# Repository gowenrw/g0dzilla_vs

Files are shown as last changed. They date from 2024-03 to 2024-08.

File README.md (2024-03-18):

# godzilla_vs

Godzilla VS Badge Artifacts

This is a DEFCON Indie badge created for DC32.

This is where all the files for the Badge will be stored.

This includes code and art and cad and fab files.  All the things.

## File Structure

This is the file structure of this repository

* [/](/README.md) - YOU ARE HERE
* [/art/](./art/) - Artwork and other graphics created by this project
  * [/art/inspiration/](./art/inspiration/) - Art and graphics pulled f6 other sources used as inspiration for this project
  * [/art/fonts/](./art/fonts/) - Fonts used in art and graphics
* [/code/](./code/) - All project related Code / Firmware
* [/docs/](./docs/) - Documentation created by this project including web pages
* [/eda/](./eda/) - Electronic Design Automation files (i.e. KiCad)
  * [/eda/godzilla_vs/](./eda/godzilla_vs/) - KiCad 7.x project folder for the godzilla_vs PCB
* [/reference_parts/](./reference_parts/) - Documentation pulled from other sources related to components
* [/README.md](/README.md) - This File
* [/LICENSE](/LICENSE) - Currently set to MIT

Note: the reference_parts directory is a link to a submodule repository.
To add it use the following cmd after cloning this:
```
git submodule update --init --recursive
```
If adding for the first time (i.e., it is not linked in the remote master) use this:
```
git submodule add https://github.com/gowenrw/reference_parts reference_parts
```
This will make a link to the current commit of that repo.
To update it to a newer commit after its been added use this cmd:
```
git submodule update --remote
```

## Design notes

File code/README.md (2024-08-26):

# Code

This is where all the project related Code / Firmware is located

# File Structure

This is the file structure of this repository

* [/](/README.md) - Home
* [/code/](/code/) - YOU ARE HERE

# Arduino IDE/CLI

The code presented here is mostly Arduino code.

In order to use this code and push new code to the ESP32 on the badge we recommend using the Arduino IDE/CLI software.
This can be downloaded for various platforms at [arduino.cc](https://www.arduino.cc/en/software).

The Arduino IDE UI will require some manual configuration to work with the badge ESP32 and our code.

The Arduino CLI can be used instead and allows for scripting much of the initial setup and use of whichever IDE you like (in my case I use VSCode).

# Arduino Versions

These are the Arduino IDE and CLI versions we have tested the code with:

* Arduino IDE v 2.3.2
  * [Windows MSI Link](https://downloads.arduino.cc/arduino-ide/arduino-ide_2.3.2_Windows_64bit.msi)
  * [Linux 64bit AppImage Link](https://downloads.arduino.cc/arduino-ide/arduino-ide_2.3.2_Linux_64bit.AppImage)
  * [MacOS ARM64bit DMG Link](https://downloads.arduino.cc/arduino-ide/arduino-ide_2.3.2_macOS_arm64.dmg)
  * [Installation Instructions](https://docs.arduino.cc/software/ide-v2/tutorials/getting-started/ide-v2-downloading-and-installing)
* Arduino CLI v 0.35.3
  * [Windows MSI Link](https://github.com/arduino/arduino-cli/releases/download/v0.35.3/arduino-cli_0.35.3_Windows_64bit.msi)
  * [Linux 64bit Tarball Link](https://github.com/arduino/arduino-cli/releases/download/v0.35.3/arduino-cli_0.35.3_Linux_64bit.tar.gz)
  * [MacOS ARM64bit Tarball Link](https://github.com/arduino/arduino-cli/releases/download/v0.35.3/arduino-cli_0.35.3_macOS_ARM64.tar.gz)
  * [Installation Instructions](https://arduino.github.io/arduino-cli/0.35/installation/)

WARNING - DO NOT use Arduino CLI v 1.x if you want the scripts here to work, it is very buggy concerning local config files and relative paths

# Quickstart

If you want to jump right in and start compiling and uploading code using the Arduino CLI and the scripts provided then checkout the [QUICKSTART page](QUICKSTART.md).

# Arduino IDE setup and use

Some additional setup is required to use the Arduino IDE with the ESP32 on the badge:

* Add the ESP32 boards manager URL in preferences
  * Under File->Preferences find the "Additional boards manager URLs" section and add the following
  * https://espressif.github.io/arduino-esp32/package_esp32_index.json
  * Then click OK and close the IDE.  When it is reopened it wil download the ESP32 board definitions.
* Select the board "ESP32 Dev Module"
  * You need to select a board to associate with the code even if that board is not connected
  * In the "Select Board" dropdown, choose "ESP32 Dev Module" from the list
  * The first time you do this it may download some addiotional software.
* Connect the ESP32 via USB cable and select the COM port if it is not autodetected
  * In most cases it should autodetect the port
  * Sometimes on first connect you need to help it by going to Tools->Port and choosing the port
* This code exceeds the normal partition size so make sure you select the Minimal SPIFFS Partition type
  * This setting can be found under Tools -> Partition Scheme
* This code uses the AdaFruit NeoPixel library which needs to be installed
  * The library can be installed via the Arduino IDE library manager or manually
  * Installation instructions can be found at [the adafruit neopixel github page](https://github.com/adafruit/Adafruit_NeoPixel)

Once the Arduino IDE environment has been set up you can simply open one of the sketches here, make whatever changes you like, then compile and upload the code to the badge.

# Arduino CLI

In an effort to bring portability to the code here (since this is lacking in the Arduino 2.x IDE) we will be providing a local configuration file for the Arduino CLI and scripts to make use of it.

While we cannot ensure this will work on all systems, the files provided should at a minimum help you configure your local environment.

## Using the CLI Local Config

The arduino cli will use a global default config if a config file is not specified.

A local config file is provided named ```arduino-cli.yml``` which uses relative path references for the data and staging and build and user area that Arduino CLI should use.

These directories are local to the repository code directory and the CLI will install all its needed files here instead of in the various places it usually defualts to on differnt systems.

While this might duplicate many files on your system if they are already installed in default locations, it provides a consistent cross platform way of knowing exactly what libraries, headers, etc., that Arduino will use in the compilation of your code.

NOTE that the .gitignore for this repository has been set up to ignore the local directories used to store the core and library files to prevent these files from accidentally getting uploaded to github.

To use the Arduino CLI with this local config file simply add the ```--config-file arduino-cli.yml``` argument to each CLI command.

For example, the command below uses the local config file and will dump the current config to the screen
```
arduino-cli --config-file arduino-cli.yml config dump
```

## Setup for CLI

There are a few things that need to be done to setup the Arduino CLI for use with the badge ESP32 and our code.

The ESP32 board core files must be loaded as well as any libraries the code will use.

To simplify this setup we have created setup bash script named ```cli-setup.sh``` that can be run on Linux and Windows (via Git Bash for Windows).

To perform the CLI setup via the script execute it in the code directory
```
bash ./cli-setup.sh
```

This script will save any std_out and std_err output to a file named ```arduino_cli_setup.log``` which you can review if you are having issues.

To perform the CLI setup manually without this script you can use the commands outlined below.

### Installing the ESP32 board core for CLI

Since the config is specifying a third party core for the ESP32 we need to pull an initial index from it.  This search command will pull that index.
```
arduino-cli --config-file arduino-cli.yml core search esp32
```

Next we need to install the ESP32 board core files using this command.
```
arduino-cli --config-file arduino-cli.yml core install esp32:esp32
```

If the ESP32 board core files were already installed the above will simply say already installed.

To update the core file indexs to check for newer versions of previously installed cores, use the following command
```
arduino-cli --config-file arduino-cli.yml core update-index
```

To upgrade any previously installed cores use the following command
```
arduino-cli --config-file arduino-cli.yml core upgrade
```

### Installing the Neopixel Library

This code uses the AdaFruit NeoPixel library which needs to be installed

If this is the first time we are installing a library we will need the indexes so this search command will get them
```
arduino-cli --config-file arduino-cli.yml lib search 'Adafruit NeoPixel'
```

Next we need to install the Adafruit NeoPixel library files with this command
```
arduino-cli --config-file arduino-cli.yml lib install 'Adafruit NeoPixel'
```

If the Adafruit NeoPixel library files were already installed the above will simply say already installed.

To upgrade a previously installed version of this library use the following command
```
arduino-cli --config-file arduino-cli.yml lib upgrade 'Adafruit NeoPixel'
```

### Installing Other Libraries

In addition to the Neopixel Library above the CTF portion of our code requires a few more libraries.

These should be installed using the same steps as above.

This is the list of additional libraries needed

* "AsyncTCP"
* "ESPAsyncWebSrv"
* "DNSServer"

## Connect badge ESP32 board via CLI

The following command will dump a list of all available board cores installed
```
arduino-cli --config-file arduino-cli.yml board listall
```

Make sure the ESP32 we are using on the badge is in that list
```
  ESP32 Dev Module                 esp32:esp32:esp32
```

If it is not then retry the CLI setup to install the core files.

Next we will connect the badge ESP32 to our machine using a USB C cable
and check if the CLI can see it.

The following command will list all the connected boards the CLI sees
```
arduino-cli --config-file arduino-cli.yml board list
```

This will show the detected COM port and board type (which may be Unknown)
```
  Port Protocol Type                Board Name FQBN Core
  COM4 serial   Serial Port (USB)   Unknown
```

Don't worry if the board FQBN shows up as Unknown since we can set that

Take note of the COM port since we will need that to communicate with it later

## Compile code via CLI

At this point we should be ready to compile and upload code to the badge ESP32 board.

In the following examples we will be referencing the sketch ```g0dzilla_vs_01``` code so you will need to change this for whichever sketch you wish to use.

The following command will compile the named sketch for use with our board fqbn
```
arduino-cli --config-file arduino-cli.yml compile --fqbn esp32:esp32:esp32 --build-path _build --export-binaries g0dzilla_vs_01 --build-property build.partitions=min_spiffs --build-property upload.maximum_size=1966080
```

The arg ```--build-path _build``` is optional to have it put all build artifacts here instead of temp for ease of troubleshooting.

The arg ```--export-binaries``` will save the final binary files into ```<sketch_name>/build/<fqbn>/``` for use by upload.

The build property args ```--build-property build.partitions=min_spiffs --build-property upload.maximum_size=1966080``` make sure that the partition size and upload size are set properly.
Our code is THIC and wont fit in the default partition size.

When the CLI compile is run it should show you compile stats and/or errors similar to this
```
  Sketch uses 1827197 bytes (92%) of program storage space. Maximum is 1966080 bytes.
  Global variables use 48884 bytes (14%) of dynamic memory, leaving 278796 bytes for local variables.
  Maximum is 327680 bytes.
  Used library        Version Path
  Adafruit NeoPixel   1.11.0  .\code\libraries\Adafruit_NeoPixel
  WiFi                2.0.0   .\code\_data\packages\esp32\hardware\esp32\2.0.11\libraries\WiFi
  AsyncTCP            1.1.4   .\code\libraries\AsyncTCP
  DNSServer           2.0.0   .\code\_data\packages\esp32\hardware\esp32\2.0.11\libraries\DNSServer
  ESPAsyncWebSrv      1.2.6   .\code\libraries\ESPAsyncWebSrv
  FS                  2.0.0   .\code\_data\packages\esp32\hardware\esp32\2.0.11\libraries\FS
  Used platform Version Path
  esp32:esp32   2.0.11  .\code\_data\packages\esp32\hardware\esp32\2.0.11
```

### Script to Compile code via CLI

To simplify the above we have created a bash script named ```cli-compile.sh``` that takes a single command line argument of the sketch name.

To perform the compile via the script execute it in the code directory
```
bash ./cli-compile.sh g0dzilla_vs_01
```

## Upload code via CLI

Now we are ready to upload the binary we compiled to the badge ESP32 board.

Note that the binary file needed is saved to ```<sketch_name>/build/<fqbn>/``` and will be named ```<sketch_name>.ino.bin```
The code we have written here may include binaries which can be used without compiling and if you make changes and compile then these files should be overwritten.

The following command will upload the named sketch binary to the badge
```
arduino-cli --config-file arduino-cli.yml upload -p COM4 --fqbn esp32:esp32:esp32 --input-file g0dzilla_vs_01/build/esp32.esp32.esp32/g0dzilla_vs_01.ino.bin
```

NOTE: Saving the compiled binary in a defined place and uploading from an input file allows for quickly changing between different code without the need to compile each again.

It should show you upload stats and/or errors
```
  esptool.py v4.5.1
  Serial port COM4
  Connecting....
  Chip is ESP32-D0WD-V3 (revision v3.0)
  Features: WiFi, BT, Dual Core, 240MHz, VRef calibration in efuse, Coding Scheme None
  Crystal is 40MHz
  MAC: a8:42:e3:47:f0:50
  Uploading stub...
  Running stub...
  Stub running...
  Changing baud rate to 921600
  Changed.
  Configuring flash size...
  Flash will be erased from 0x00001000 to 0x00005fff...
  ...
  Compressed 18960 bytes to 13073...
  Writing at 0x00001000... (100 %)
  Wrote 18960 bytes (13073 compressed) at 0x00001000 in 0.3 seconds (effective 538.9 kbit/s)...
  Hash of data verified.
  ...
  Compressed 732656 bytes to 475614...
  Writing at 0x00010000... (3 %)
  Writing at 0x0001c1bd... (6 %)
  ...
  Writing at 0x000bcec0... (96 %)
  Writing at 0x000c2b72... (100 %)
  Wrote 732656 bytes (475614 compressed) at 0x00010000 in 6.3 seconds (effective 925.8 kbit/s)...
  Hash of data verified.
  Leaving...
  Hard resetting via RTS pin...
```

### Script to Upload code via CLI

To simplify the above we have created a bash script named ```cli-upload.sh``` that takes two command line arguments of the sketch name and serial port.

To perform the compile via the script execute it in the code directory
```
bash ./cli-upload.sh g0dzilla_vs_01 COM4
```

## Monitor Serial Output

To monitor the serial output you can use the arduino-cli or your favorite serial app.

The following command will list all the connected boards so you can get the serial port
```
arduino-cli --config-file arduino-cli.yml board list
```

The arduino-cli monitor command with serial port (from above) and baud config can be used like this:
```
arduino-cli monitor --port COM4 --config baudrate=115200
```

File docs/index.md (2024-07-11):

---
layout: default
---

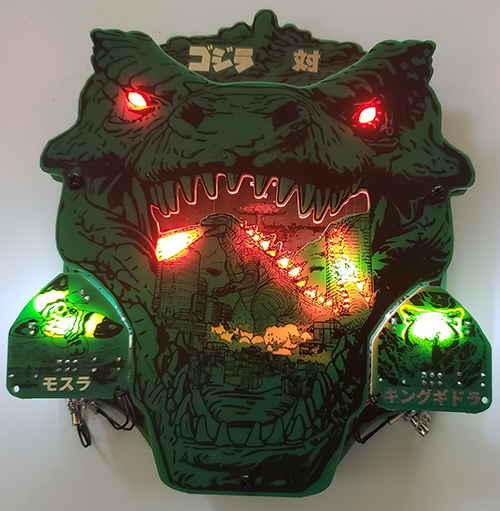
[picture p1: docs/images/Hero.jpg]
Hero Image


# G0dzilla VS Badge

Welcome to the G0dzilla VS Badge website.

This badge was designed for the DEFCON 32 security conference in August 2024.

On this page you will find all the details about this badge including an operations guide, an assembly guide (for those building the badge from a kit), and a detailed review of the art and cicuit design and pcb design.

-- [@alt_bier](https://twitter.com/alt_bier)  - [My Contact Info](https://gowen.net/about)

---

Touch Image

# Details

The badge theme was based on the fact that I love Godzilla and the movie Godzilla Minus One that was released in 2023 inspired me to do something with this theme.

Since I make badges I figured this would be my medium.  However, I made a previous badge that had Godzilla on it so if I was going to revisit this theme it was going to have to be bigger and better.

Having Godzilla fight different monsters that can be changed out since they are addons was the idea I had to bring a Godzilla badge to the next level.

This badge includes an ESP32 Wemos Lolin32 development board, eight neopixel addressable LEDs, eight traditional white LEDs, and four capacitive touch areas, four female SAO connectors (two of which are powered), and three PCBs stacked together, all powered by a LIPO battery.  And that is just the main badge!

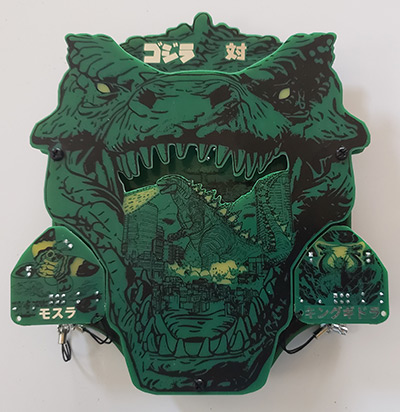
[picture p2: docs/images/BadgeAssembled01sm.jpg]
Badge Assembled

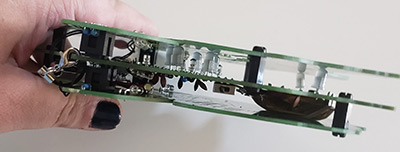
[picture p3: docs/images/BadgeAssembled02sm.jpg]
Badge Assembled


This badge also includes four Shitty Addons (SAOs) which are the monsters that Godzilla will fight.  These addons each have two traditional white LEDs and a male hooded SAO connector.
The SAOs also utilize one of the GPIO pins to send specific voltage back to the badge per SAO.  This allows for the main badge to detect which monsters are connected to it.
Up to two of the four SAOs can be connected to the front of the badge to fight Godzilla.
In order to keep the SAOs from getting separated from the badge we included mini SAO lanyards that attach them to the badge and there are two SAO connectors on the back of the badge (not powered) that act as a green room for monsters not currently in the fight.

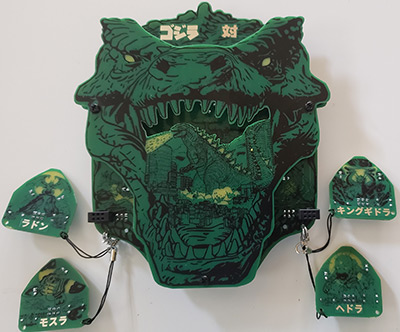
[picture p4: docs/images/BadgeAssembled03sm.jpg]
Badge with SAOs


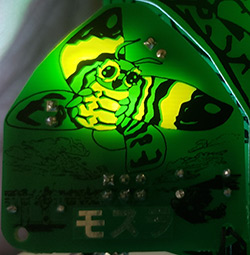
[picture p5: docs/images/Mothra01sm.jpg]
SAO Mothra

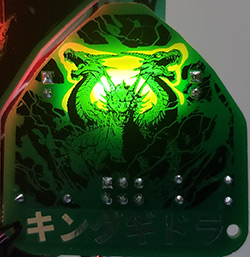
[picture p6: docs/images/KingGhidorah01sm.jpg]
SAO King Ghidorah

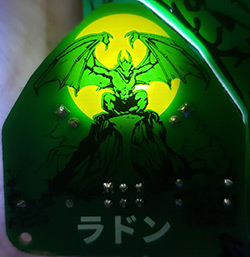
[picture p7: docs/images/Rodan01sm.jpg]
SAO Rodan

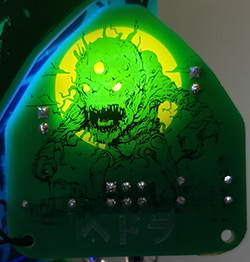
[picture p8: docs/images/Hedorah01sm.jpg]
SAO Hedorah


Since the ESP Dev board has an embedded battery charge circuit the schematic for the main badge was fairly simple.
The schematic for the SAO PCB had a challenge in that these were to be four seperate circuits but rules checks were complaining about 3V and GND not being connected between them.  I solved this by using four seperate 3V and GND power nets.
The PCB layout and tracing was a challenge due to all the solder mask voids and capacitive touch areas and the fact that there were four seperate PCBs (seven if you consider the SAO PCB breaks out to four) that all had to align perfectly with each other for when they were assembled together.

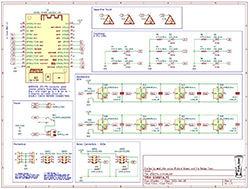
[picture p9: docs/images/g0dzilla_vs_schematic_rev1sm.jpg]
Schematic badge

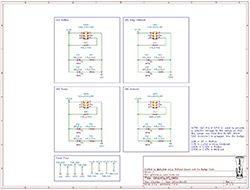
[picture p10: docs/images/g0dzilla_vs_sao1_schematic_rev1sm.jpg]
Schematic SAOs


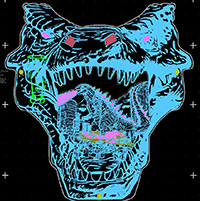
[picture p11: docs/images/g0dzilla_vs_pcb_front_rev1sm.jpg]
PCB Front

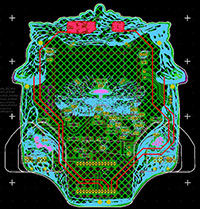
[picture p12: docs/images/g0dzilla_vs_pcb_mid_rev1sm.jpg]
PCB Middle

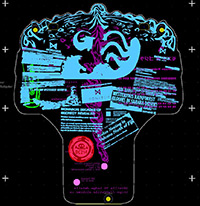
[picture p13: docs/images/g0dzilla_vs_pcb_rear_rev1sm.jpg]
PCB Rear

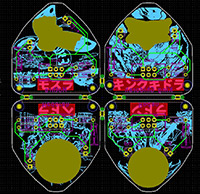
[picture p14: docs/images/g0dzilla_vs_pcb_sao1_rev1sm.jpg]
PCB SAOs


# Kit Assembly

Assembly Instructions for the G0dzilla VS Badge kit can be found here: [G0dzilla VS Badge Assembly Instructions](assembly.md)

An assembly video can be found here:
TBD

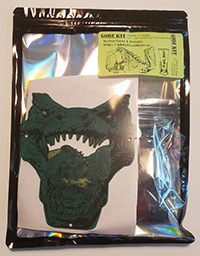
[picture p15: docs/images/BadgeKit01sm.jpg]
Badge_Kit

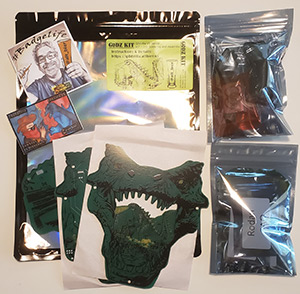
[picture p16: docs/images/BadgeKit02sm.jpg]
Badge_Kit

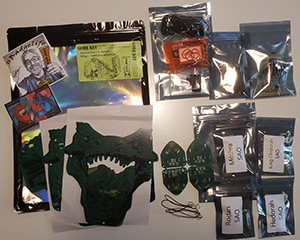
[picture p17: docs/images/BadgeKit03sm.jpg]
Badge_Kit


# Badge Operations

Here are the basics for operating the badge.

## Power Switch and Battery Charging

This badge uses an ESP32 Development board with a USB-C connector that is connected to and powered by a LIPO rechargeable battery.

The power switch on the badge is a direct cutoff to the LIPO battery.
So the switch must be in the ON position in order to charge the battery from the dev board.

The switch is on the side of the badge and is in the OFF position when it is closer to the bottom of the badge (down).

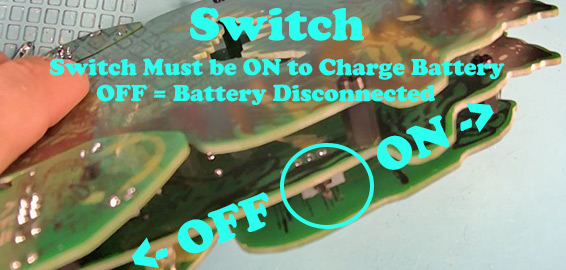
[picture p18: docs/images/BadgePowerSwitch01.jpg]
Power Switch Image


To charge the battery follow these steps:
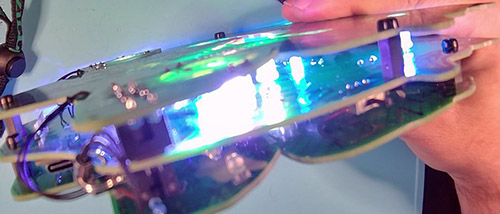
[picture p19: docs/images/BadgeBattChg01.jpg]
Power ON Image
* Turn the power switch to ON (towards the top of the badge) which will power on the badge if the battery has any charge remaining.  But, even if the badge does not power on the switch should be in the ON position. 
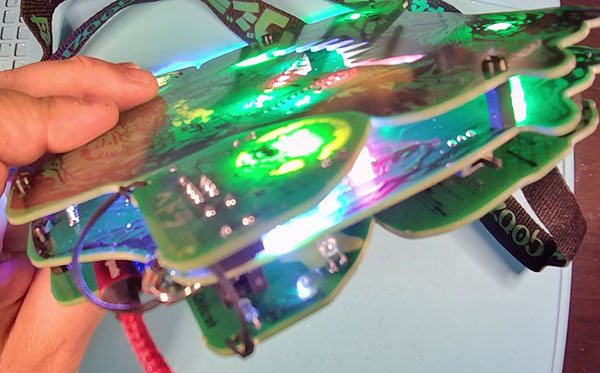
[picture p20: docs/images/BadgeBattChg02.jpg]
USB Cable Image
* Plug in a USB-C cable to the badge dev board and apply power either from a PC or wall charger. 
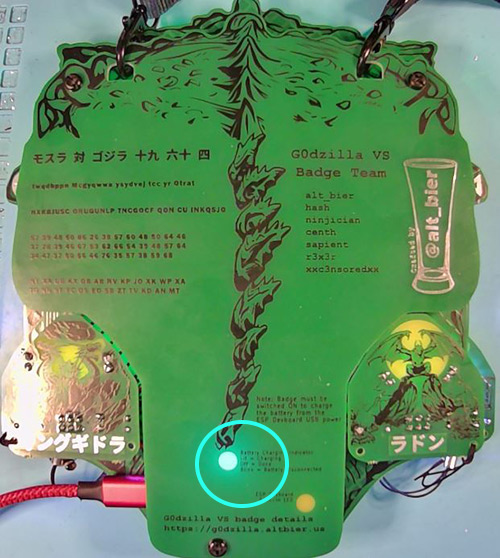
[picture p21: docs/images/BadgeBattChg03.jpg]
Charge Indicator Image
* On the back of the badge you should see the battery charge indicator light lit up.  If it is not then repeat the first two steps to try again.  This indicator light should flash if it does not see a battery connected and will turn off when a connected battery is fully charged. 
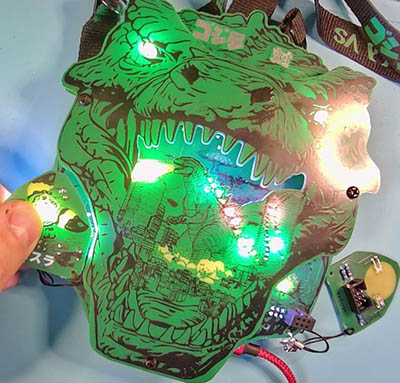
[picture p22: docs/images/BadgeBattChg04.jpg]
Remove SAOs Image
* The powered SAOs on the front of the badge should be removed while charging. This will allow for less power drain while charging from those LEDs being removed.  But more imortantly stops shining those bright lights. 
* It should take about 3 to 4 hours to fully charge a battery from fully discharged at which point the battery charge indicator light will turn off.
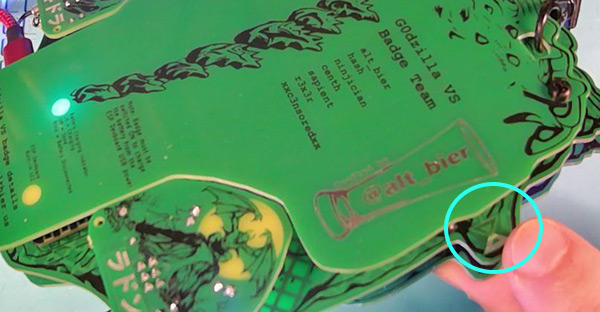
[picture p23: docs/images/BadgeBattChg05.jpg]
Logo Press Image
* Since it can be annoying to have the badge flashing all its LEDs while charging we added a LED-Off mode that can be activated by pressing on the Monarch Logo button (located on the back side of the middle PCB) for a LONG PRESS press of about 20 to 30 seconds. 
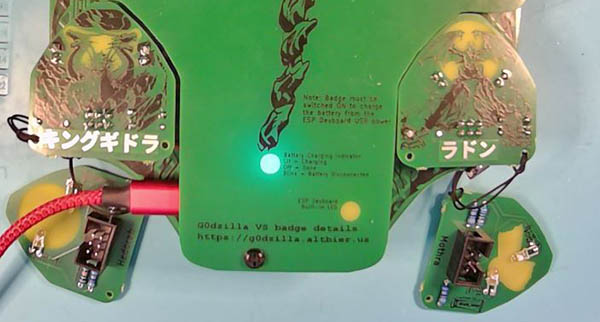
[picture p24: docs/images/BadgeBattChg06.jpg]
LED Off Mode Image
* In the LED-Off mode all the badge LEDs will turn off except for the two on the ESP dev board.  The battery charge indicator light should be on if it charging and the on-board LED will flash once every 20 seconds or so.  The flashing LED is there to tell you the badge is still powered on even if the charge is done and the charge light turns off. This LED mode can be disabled by long pressing the Monarch Logo again or by power cycling the badge (including disconnecting the USB) 

## Touching Godzilla Text - Change badge LED mode

Pressing the word "Godzilla" will change the LED mode.

The default mode color cycles all the neopixels and slowly pulses some of the white LEDs.

There is a battle mode where Godzilla is animated fighting.

Other modes will be added as time permits, but these two modes are what is shipping with the badges. 

## Touching VS Text - Boop

Pressing the word "VS" will flash all the white LEDs briefly in a boop effect.

## Touching Monarch Logo - Boop and LED-Off

Pressing the Monarch Logo will flash all the Neopixel LEDs in a random color briefly in a boop effect.

Holding a long press of 20 seconds on the Monarch Logo will enter the LED-Off mode (as explained in the battery charging section above).

## Touching Godzilla Minus One Logo - Boop and Crypto Challenge Mode

Pressing the Godzilla Minus One Logo will flash all the Neopixel LEDs in a random color briefly in a boop effect.

Holding a long press of 20 seconds on the Godzilla Minus One Logo will enter the Cryppto CTF Mode.

This is a crypto challenge game that is launched on a local wireless ap and web server.

When this mode is activated the eyes on the badge will turn solid red and the badge will launch a wireless access point with the name "GDZL-badge-<MAC>" and a web server on 192.168.1.31

Connect to the access point which is open and does not require a password, then browse http://192.168.1.31 to start the crypto challenge.

This Mode can be disabled by long pressing the Godzilla Minus One Logo again or by power cycling the badge.

## Silkscreen Crypto Challenge

In addition to the web based crypto challenge there is an additional crypto challenge built into the silkscreen layer on the back of the badge.

While similar in style and layout of the web based challenge these are seperate challenges that do not depend upon each other for solving.

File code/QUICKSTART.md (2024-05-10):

# Code Quickstart

Notes:

* You will need Arduino CLI Installed and a Bash shell (on Windows Git Bash is provided by Git for Windows)
* The CTF code is a precompiled library so you cant change that for now, source to be released after defcon
* The current code that is loaded on the badge is the sketch named ```g0dzilla_vs_01```

## Setting up Arduino CLI environment

Follow these steps:

* Change directory to the code directory if you arent already there
* Run the following command preceding it with ```bash``` if needed by your OS
  * ```./cli-setup.sh```
* If it completes without errors then setup is complete
  * If you have errors then refer to the main README doc or script file to try the steps manually

## Compiling Code

Once you have made whatever changes you wanted to the code here is how we compile it.

* Change directory to the code directory if you arent already there
* Run the following command preceding it with ```bash``` if needed by your OS changing the sketch name if needed
  * ```./cli-compile.sh g0dzilla_vs_01```
* If it completes without errors then the compile is complete
  * If you have errors then read what they are and make the appropriate changes to your code

## Upload Code

Once the code has been compiled we can upload it to the badge.

Follow these steps:

* Change directory to the code directory if you arent already there
* Run the following command
  * ```arduino-cli --config-file arduino-cli.yml board list```
* Take note of the serial port name of the connected board 
* Run the following command preceding it with ```bash``` if needed and changing the serial port to above
  * ```./cli-upload.sh g0dzilla_vs_01 COM6```

## Serial Monitor

Once the code has been uploaded you can use the serial monitor to look for any text the code is sending.

* Run the following command changing the serial port to what board list showed above
  * ```arduino-cli monitor --port COM6 --config baudrate=115200```

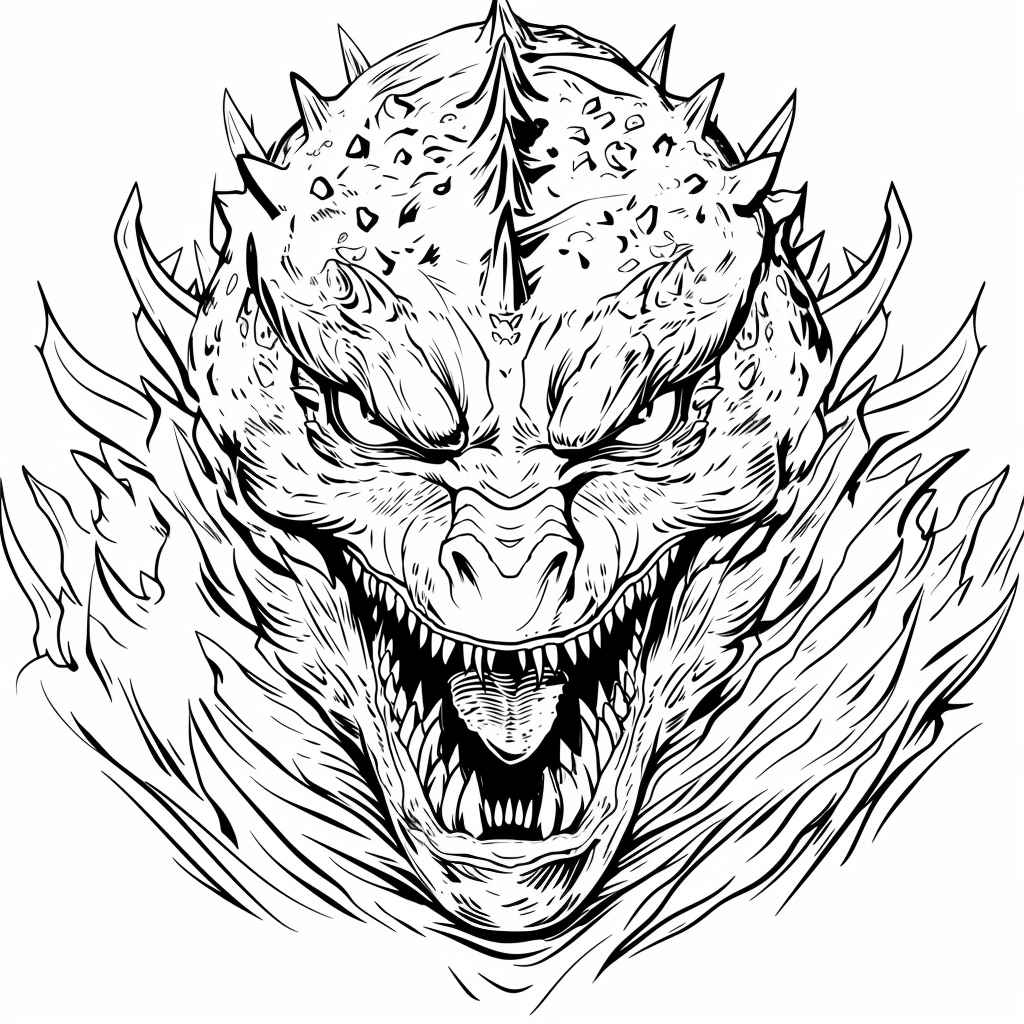
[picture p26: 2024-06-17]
art/inspiration/alt_bier_godzilla_face_both_eyes_visible_about_to_eat_the_viewe_f581bc2f-0139-48a3-ba4f-096c2e8dd892.png

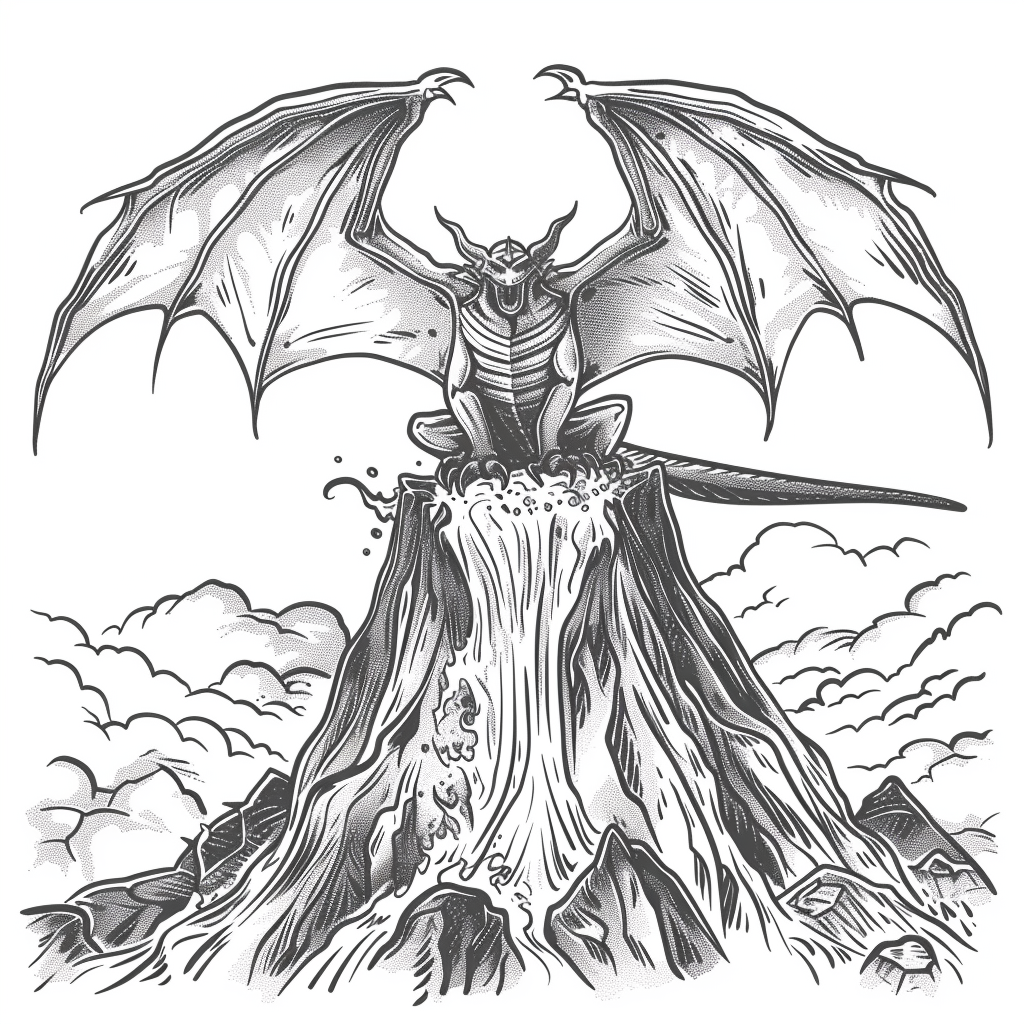
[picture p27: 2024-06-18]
art/inspiration/alt_bier_The_monster_Rodan_sitting_atop_a_volcano_that_is_spill_625bf1e6-68ef-4f6c-bedc-f5eaeb14153d.png

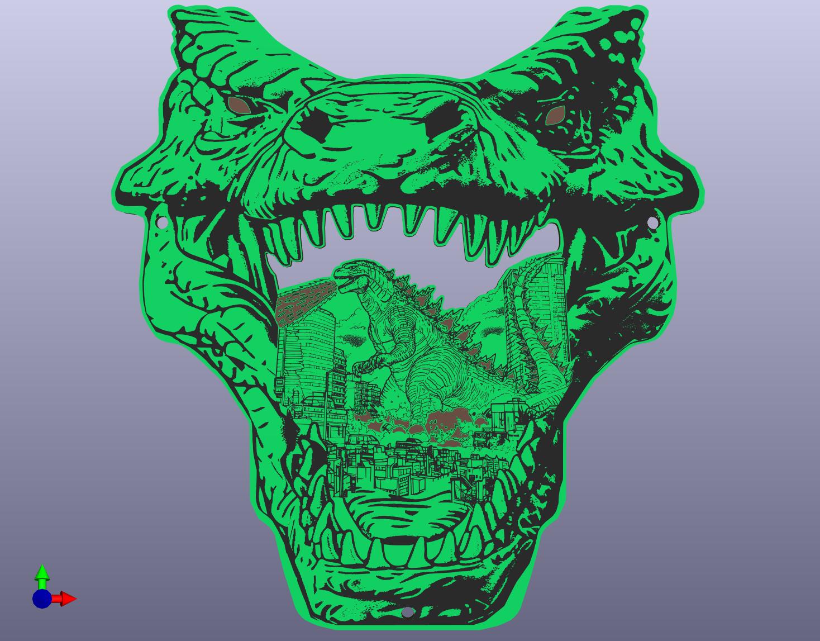
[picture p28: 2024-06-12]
eda/g0dzilla_vs/snapshots/g0dzilla_vs_3D_proto01.jpg

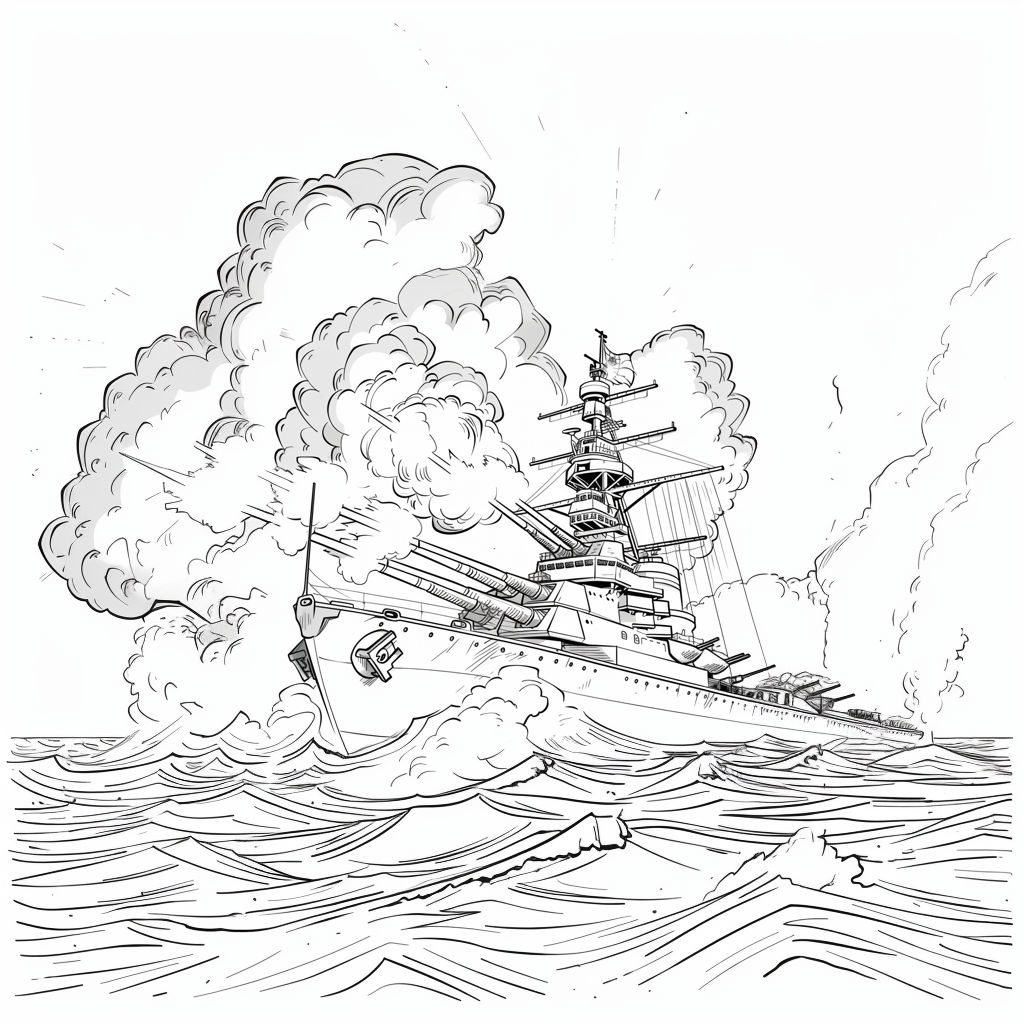
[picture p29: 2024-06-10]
art/inspiration/alt_bier_a_battleship_shooting_at_a_distant_target_with_smoke_p_26e57a6c-4ae1-4770-afa3-136d2fdbe578.png

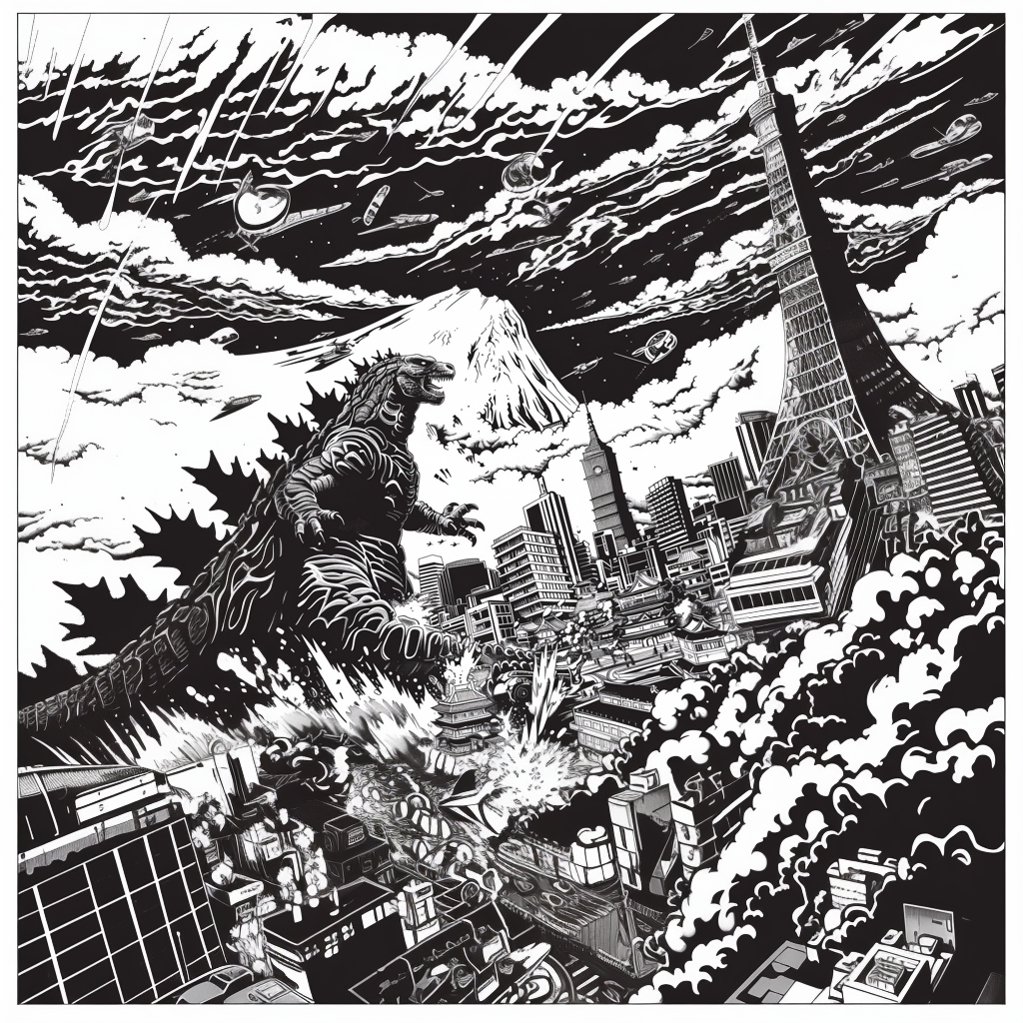
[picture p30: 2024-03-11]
art/inspiration/alt_bier_black_and_white_coloring_page_black_lines_no_color_no__eb211865-8d01-49a8-a5e8-c46503b37f65.png

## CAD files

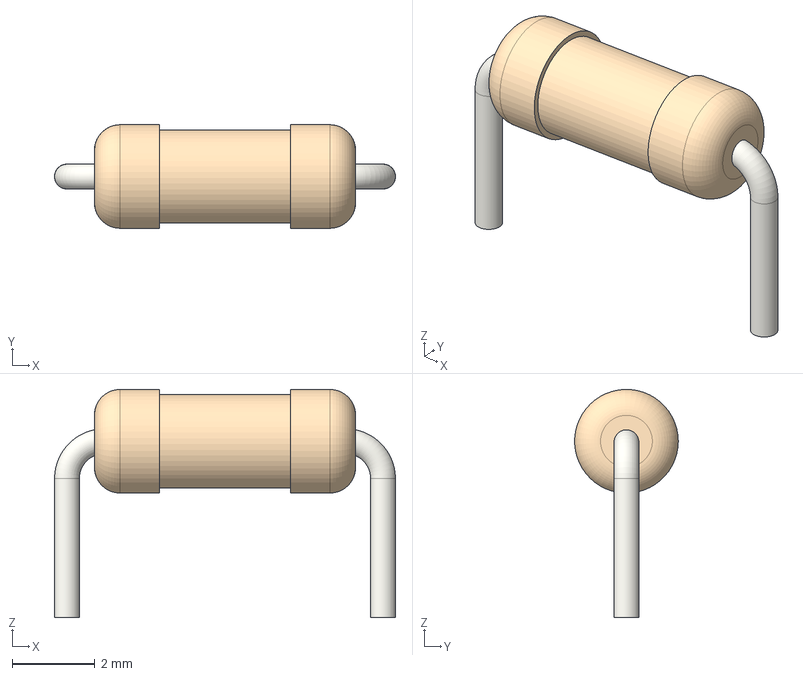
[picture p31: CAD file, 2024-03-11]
eda/g0dzilla_vs/3d_models/R_Axial_DIN0207_L6.3mm_D2.5mm_P7.62mm_Horizontal.step
8.22 x 2.50 x 5.50 mm

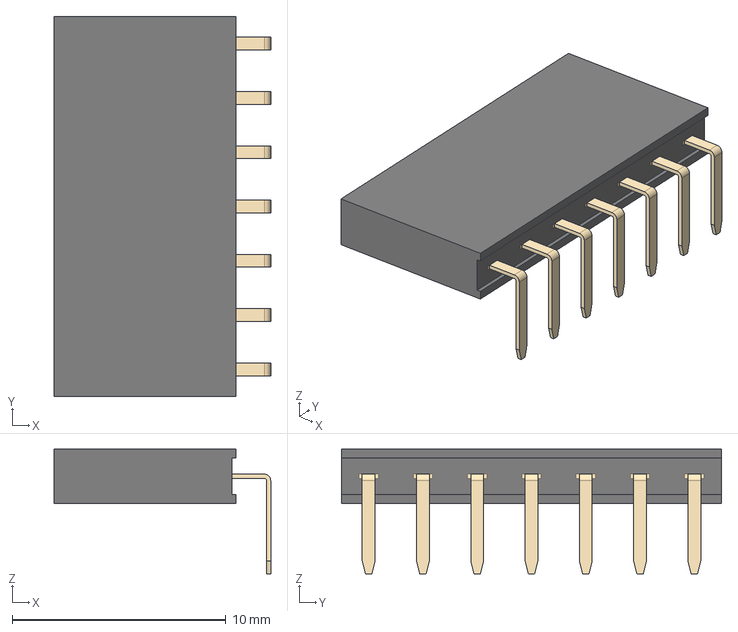
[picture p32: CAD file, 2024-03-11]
eda/g0dzilla_vs/3d_models/PinSocket_1x07_P2.54mm_Horizontal.step
10.1 x 17.8 x 5.84 mm

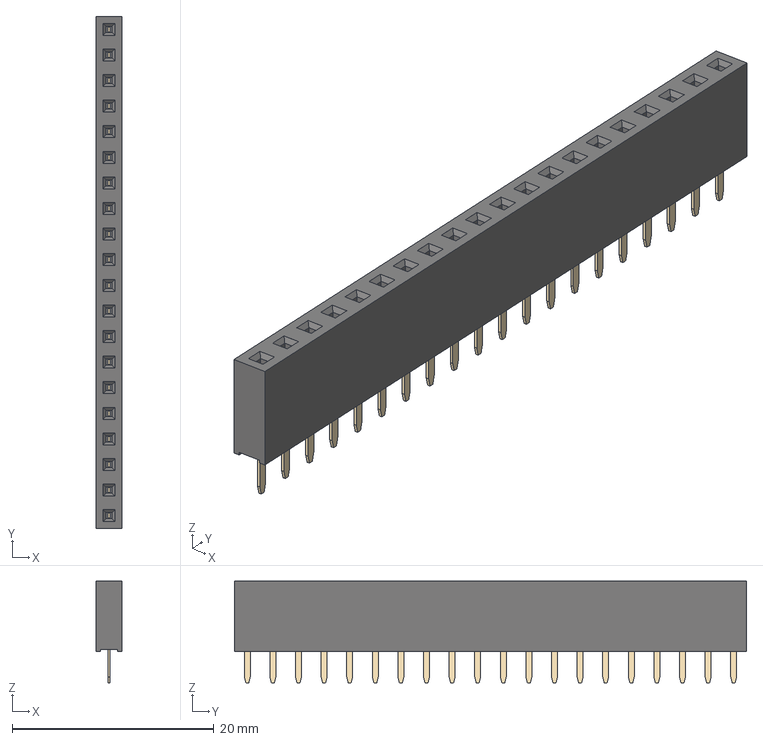
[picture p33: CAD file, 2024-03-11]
eda/g0dzilla_vs/3d_models/PinSocket_1x20_P2.54mm_Vertical.step
2.54 x 50.8 x 10.1 mm

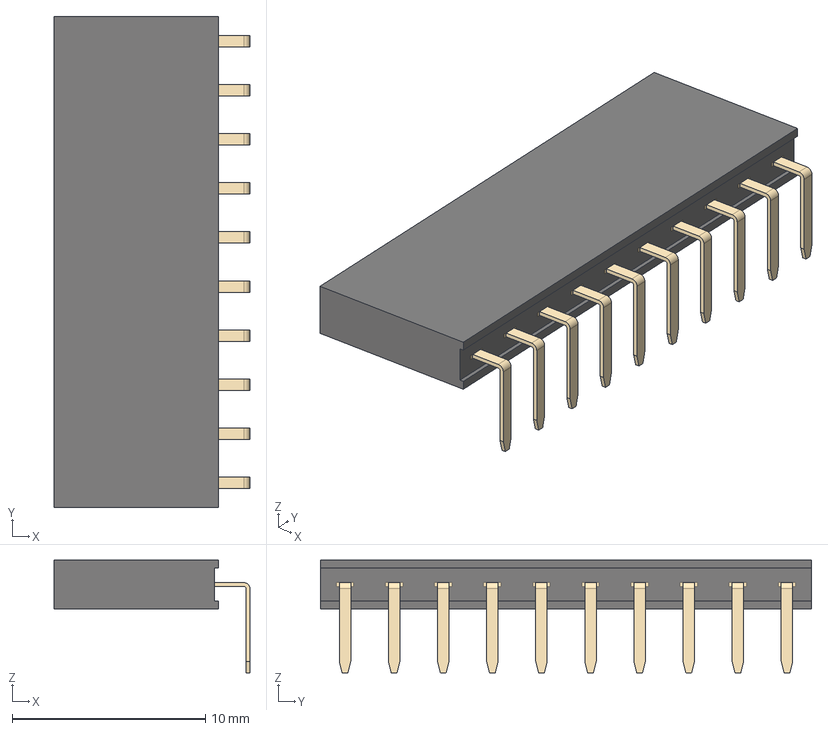
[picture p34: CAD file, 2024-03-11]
eda/g0dzilla_vs/3d_models/PinSocket_1x10_P2.54mm_Horizontal.step
10.1 x 25.4 x 5.84 mm

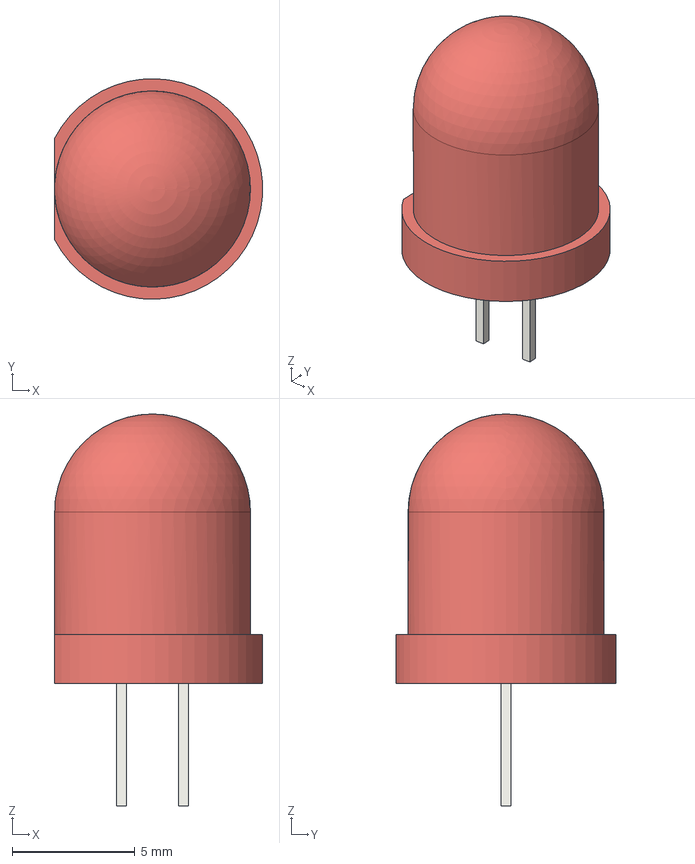
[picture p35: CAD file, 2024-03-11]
eda/g0dzilla_vs/3d_models/LED_D8.0mm.step
8.49 x 9.00 x 16.0 mm

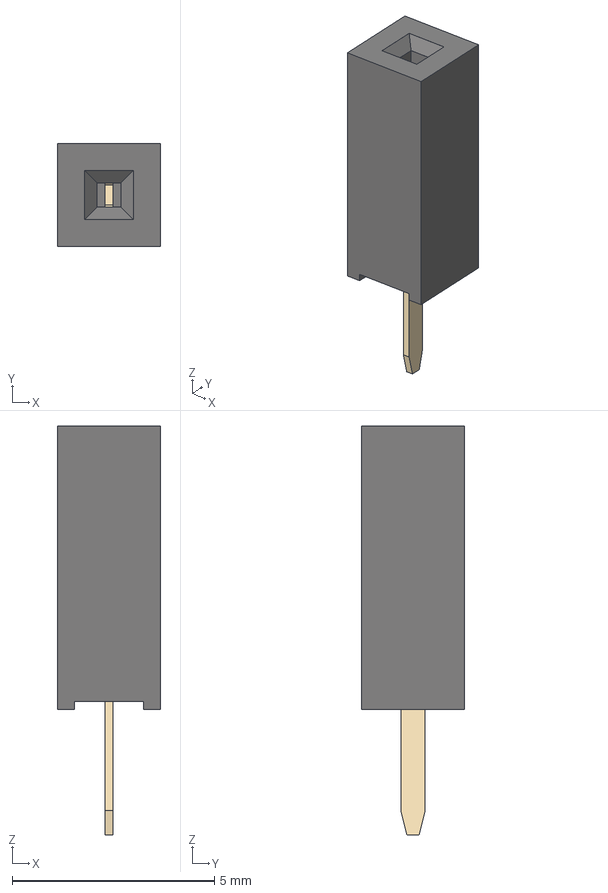
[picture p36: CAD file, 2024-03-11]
eda/g0dzilla_vs/3d_models/PinSocket_1x01_P2.54mm_Vertical.step
2.54 x 2.54 x 10.1 mm

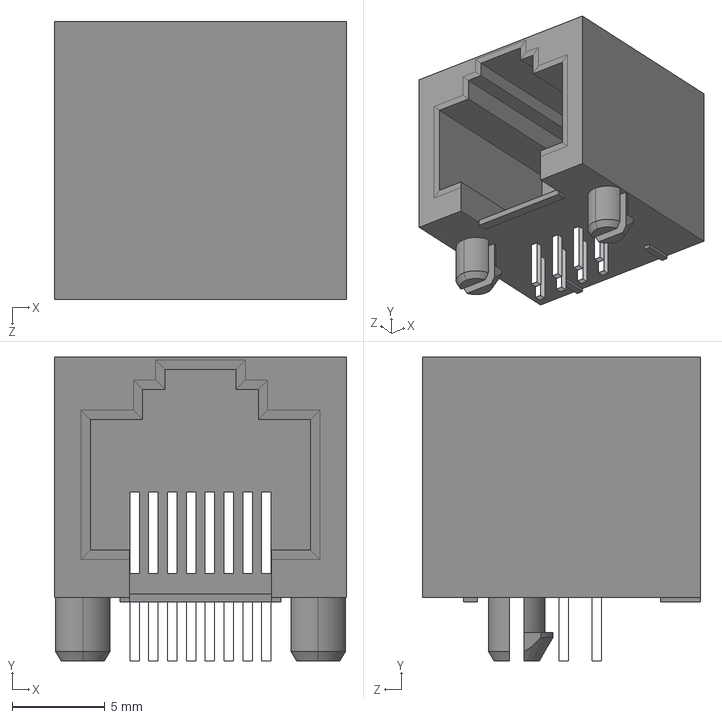
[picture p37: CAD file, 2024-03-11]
eda/g0dzilla_vs/3d_models/RJ45_Amphenol_RJHSE-5080-56544.STEP
15.7 x 16.4 x 15.0 mm

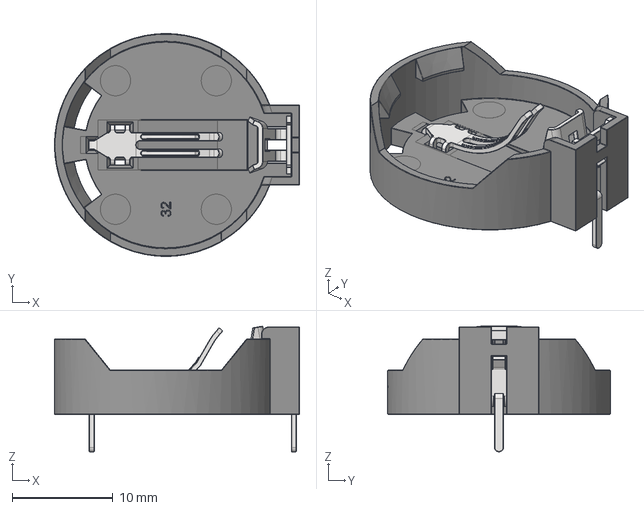
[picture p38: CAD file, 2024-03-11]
eda/g0dzilla_vs/3d_models/Battery_Holder_CR2032_BS-2-1.stp
24.3 x 22.1 x 12.5 mm

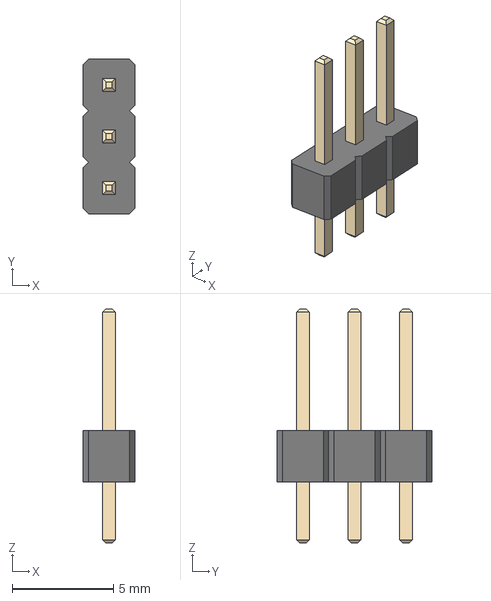
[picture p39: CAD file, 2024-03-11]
eda/g0dzilla_vs/3d_models/PinHeader_1x03_P2.54mm_Vertical.step
2.54 x 7.62 x 11.5 mm

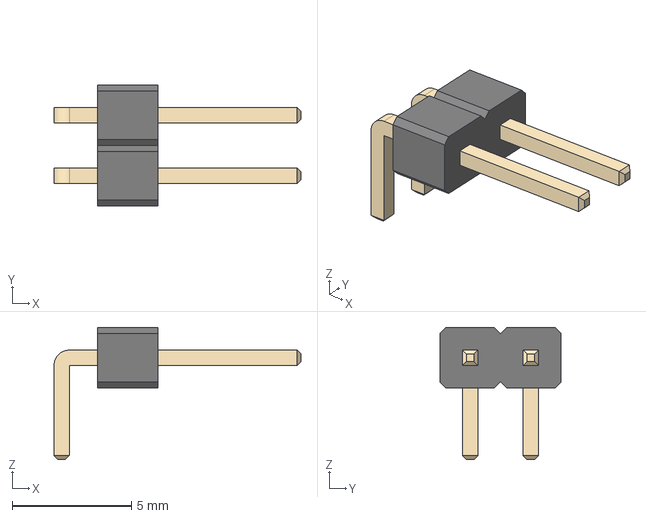
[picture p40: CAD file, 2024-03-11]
eda/g0dzilla_vs/3d_models/PinHeader_1x02_P2.54mm_Horizontal.step
10.4 x 5.08 x 5.54 mm

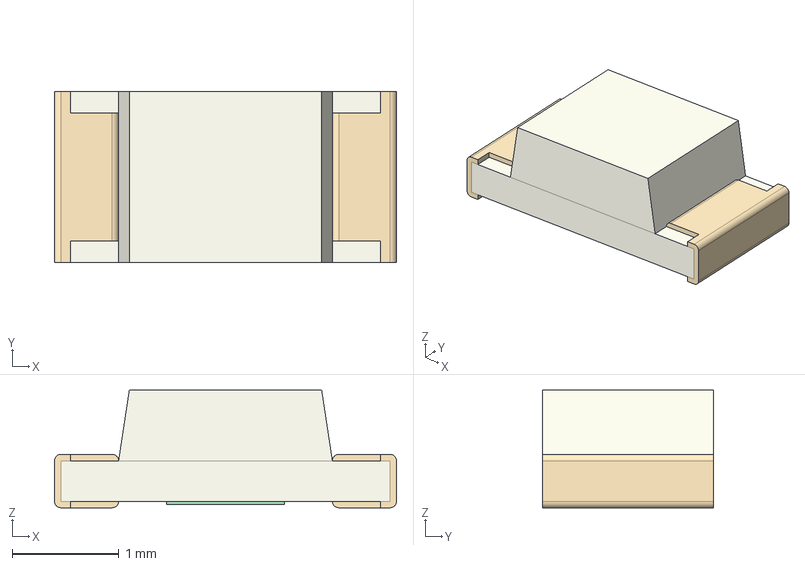
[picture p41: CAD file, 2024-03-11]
eda/g0dzilla_vs/3d_models/LED_1206_3216Metric.step
3.20 x 1.60 x 1.10 mm

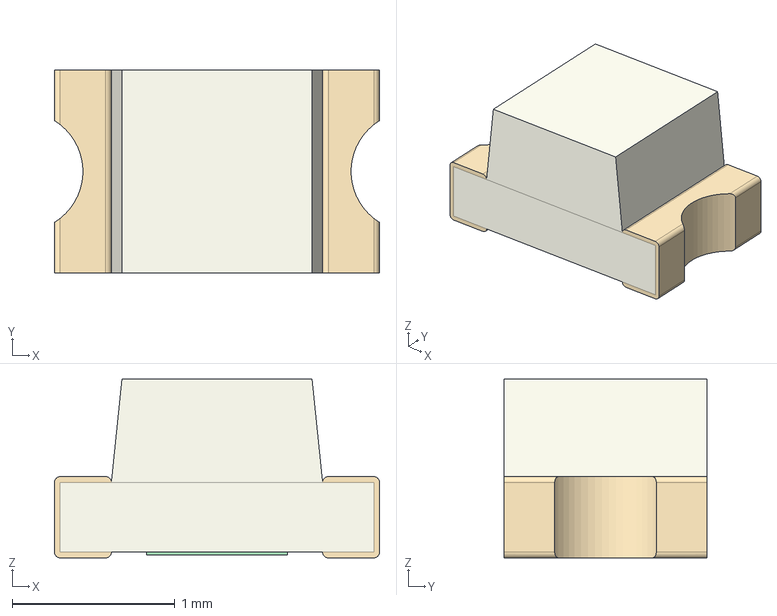
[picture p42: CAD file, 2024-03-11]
eda/g0dzilla_vs/3d_models/LED_0805_2012Metric_Castellated.step
2.00 x 1.25 x 1.10 mm

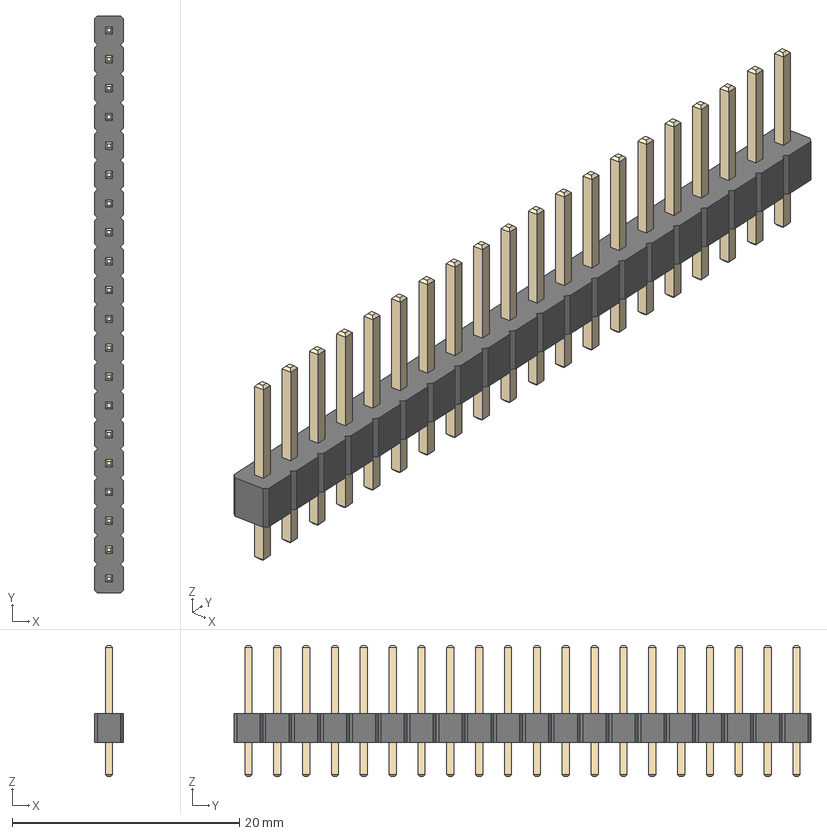
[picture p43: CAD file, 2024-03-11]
eda/g0dzilla_vs/3d_models/PinHeader_1x20_P2.54mm_Vertical.step
2.54 x 50.8 x 11.5 mm

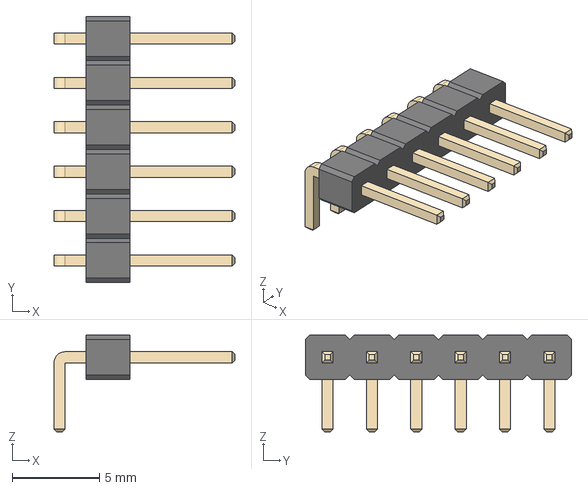
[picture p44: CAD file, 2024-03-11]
eda/g0dzilla_vs/3d_models/PinHeader_1x06_P2.54mm_Horizontal.step
10.4 x 15.2 x 5.54 mm

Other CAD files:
eda/g0dzilla_vs/3d_models/PinSocket_1x20_P2.54mm_Horizontal.step
eda/g0dzilla_vs/3d_models/BatteryHolder_2466_1xAAA.step
eda/g0dzilla_vs/3d_models/PinHeader_1x08_P2.54mm_Vertical.step
eda/g0dzilla_vs/3d_models/RJ45_Amphenol_RJHSE538X.step
eda/g0dzilla_vs/3d_models/BatteryHolder_2468_2xAAA.step
eda/g0dzilla_vs/3d_models/Battery_Holder_3xAAA_Simple.step
eda/g0dzilla_vs/3d_models/CP_Radial_D5.0mm_P2.00mm.step
eda/g0dzilla_vs/3d_models/CP_Radial_D6.3mm_P2.50mm.step
eda/g0dzilla_vs/3d_models/CUI_PXO7803-500-M-TR.step
eda/g0dzilla_vs/3d_models/C_0603_1608Metric.step
eda/g0dzilla_vs/3d_models/C_0805_2012Metric.step
eda/g0dzilla_vs/3d_models/C_1206_3216Metric.step
eda/g0dzilla_vs/3d_models/C_Disc_D3.0mm_W2.0mm_P2.50mm.step
eda/g0dzilla_vs/3d_models/C_Rect_L4.6mm_W2.0mm_P2.50mm_MKS02_FKP02.step
eda/g0dzilla_vs/3d_models/GC9A01_1.28IN_240x240_v1.step
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

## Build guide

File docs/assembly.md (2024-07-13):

---
layout: default
---

# G0dzilla VS Badge Kit Assembly Instructions

Welcome to the G0dzilla VS Badge kit assembly instructions.

This page will detail what comes in the badge kit and step by step instructions to build your badge. 

-- [@alt_bier](https://twitter.com/alt_bier)  - [My Contact Info](https://gowen.net/about)

## Badge Distribution Packages

The badges have been distributed in two different packages

* KIT - This is a kit that requires DIY soldering/assembly of all components
* ASS - This is a Fully Assembled ready to wear badge

## Component List

This is the list of components that are provided in the kit

* Main Kit Bag (20x25cm-8x10in Black & Holographic) Containing:
  * 3x PCBs (front, middle, and rear) separated with paper
  * Badge Component Bag (10x15cm-4x6in Mylar) Containing:
    * Small Component Bag #1 (4x5cm-1.5x2in Clear) Containing:
      * 6x Black Nylon Standoff and M3 Screw sets
    * Small Component Bag (5x7cm-2x2.8in Red) Containing:
      * 1x Lipo Battery 103040
      * 1x JST mini PH Connector Wire
      * 4x Rubber Band Size #8 (2 req. 2 spare)
    * Small Bag (5x8cm-2x3in Clear) Containing:
      * 1x Lanyand
    * Small Component Bag (6x9cm-2.4x3.5in Mylar) Containing:
      * 1x ESP32 WeMos Lolin32 Dev Board
      * 2x Header Male 2.54mm 1x13 Pin Strip
    * Small Component Bag (8x12cm-3.2x4.7in Mylar) Containing:
      * 8x WS2812D 5mm 4-Pin Addressable Neopixel LED
      * 8x White 3mm 2-pin LED
      * 8x 100nF Ceramic Disc Capacitor
      * 10x 47 Ohm 6.2mm Metal Film Resistor
      * 2x 100K Ohm 6.2mm Metal Film Resistor
      * 1x SS12D00 3-Pin SPDT Right Angle Switch
      * 4x Header Male 2.54mm 1x2 Pin Right Angle Strip
      * 4x Header Female 2.54mm 2x3 Pin Keyed (SAO)
  * Badge Component Bag (10x15cm-4x6in Mylar) Containing:
    * 1x PCB panel (which breaks apart into four small SAO PCBs) Note: This PCB might have broken apart during shipping, but this is not a problem as breaking is required for assembly.
    * 4x Mini 2in Lanyard with tiny keyring
    * Small Component Bag (6x9cm-2.4x3.5in Mylar) Labeled "Mothra SAO" Containing:
      * 2x White 3mm 2-pin LED
      * 2x 47 Ohm 6.2mm Metal Film Resistor
      * 1x 10K Ohm 6.2mm Metal Film Resistor
      * 1x Header Male 2.54mm 2x3 Pin Keyed Hooded (SAO)
    * Small Component Bag (6x9cm-2.4x3.5in Mylar) Labeled "King Ghidorah SAO" Containing:
      * 2x White 3mm 2-pin LED
      * 2x 47 Ohm 6.2mm Metal Film Resistor
      * 1x 47K Ohm 6.2mm Metal Film Resistor
      * 1x Header Male 2.54mm 2x3 Pin Keyed Hooded (SAO)
    * Small Component Bag (6x9cm-2.4x3.5in Mylar) Labeled "Rodan SAO" Containing:
      * 2x White 3mm 2-pin LED
      * 2x 47 Ohm 6.2mm Metal Film Resistor
      * 1x 100K Ohm 6.2mm Metal Film Resistor
      * 1x Header Male 2.54mm 2x3 Pin Keyed Hooded (SAO)
    * Small Component Bag (6x9cm-2.4x3.5in Mylar) Labeled "Hedorah SAO" Containing:
      * 2x White 3mm 2-pin LED
      * 2x 47 Ohm 6.2mm Metal Film Resistor
      * 1x 220K Ohm 6.2mm Metal Film Resistor
      * 1x Header Male 2.54mm 2x3 Pin Keyed Hooded (SAO)
  * 2x Sticker (Not Required for badge Assembly)

Badge_Kit
Badge_Kit
Badge_Kit

## Assembly Steps for the Badge

* All the badge components will be added to the middle PCB board
  * Identify the middle PCB board and use this for all the following steps up to the stack assembly.
  * Any reference to the back side of the PCB is talking about the side of the middle PCB that has the Monarch and Godzilla Minus one Logos in copper.
  * Any reference to the front side of the PCB is talking about the side of the middle PCB that has the Japanese text "Godzilla VS" in copper.

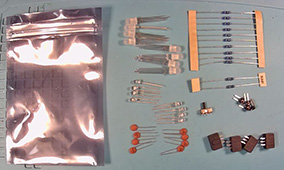
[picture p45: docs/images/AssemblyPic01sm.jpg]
Components

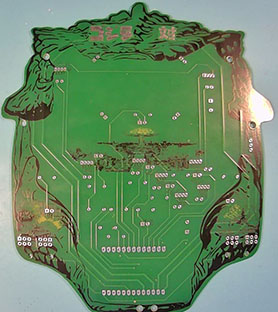
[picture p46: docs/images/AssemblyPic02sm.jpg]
PCB Mid Front

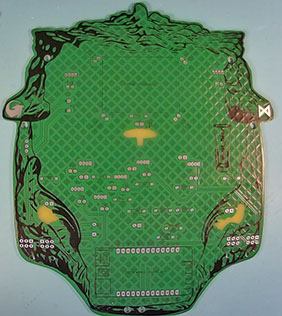
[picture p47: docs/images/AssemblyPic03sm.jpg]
PCB Mid Back


* Resistors
  * The ten 47-Ohm resistors are labeled R1-R8, R10 and R20 on the back side of the PCB
  * The two 100K-Ohm resistors are labeled R32 and R32 on the back side of the PCB
  * Resistors are non-polar so they can be placed in either direction.
  * Place all the resistors into the back side of the PCB bending thier legs outward on the front side to hold them in place
  * Solder all the resistor connections on the front side of the PCB.
  * When cooled cut the component legs off at the top of the solder joints (do not cut into the solder joint)

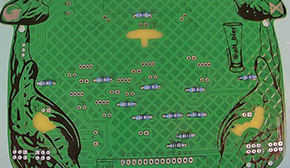
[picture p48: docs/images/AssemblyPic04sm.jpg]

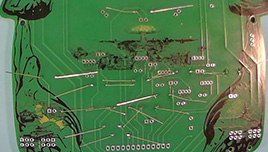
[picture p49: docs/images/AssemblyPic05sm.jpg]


* One Color (White) 3mm 2 pin LEDs
  * The eight traditional one color (white) 2 pin LEDs are easy to solder.
  * LEDs are polar and must be placed in the proper direction.  They have one leg longer than the other to indicate the cathode and anode legs.
    * The PCB silk has drawings of the short and long pin positions as a guide for each LED.
    * The PCB solder pad shapes provide another guide as the short leg should always go in the square hole
  * Three of these LEDs are labeled D6-8 on the back side of the PCB
    * These LEDs need to be bent over for specific positioning on the PCB so be careful with placement
    * Place these LEDs into thier labeled positions on the back side of the PCB
    * Make sure to align the LEDs properly using the silk guide to place short leg in square hole, folding the LEDs in the direction indicated to place the body of the LED over the solder mask void on the PCB
    * Solder all the LED connections
    * When cooled cut the component legs off at the top of the solder joints (do not cut into the solder joint)
  * Five of these LEDs are labeled D1-5 on the frront side of the PCB
    * Place these LEDs into thier labeled positions on the back side of the PCB
    * Make sure to align the LEDs properly using the silk guide to place short leg in square hole
    * Solder all the LED connections
    * When cooled cut the component legs off at the top of the solder joints (do not cut into the solder joint)

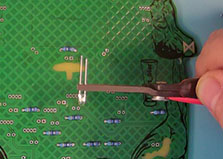
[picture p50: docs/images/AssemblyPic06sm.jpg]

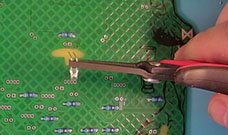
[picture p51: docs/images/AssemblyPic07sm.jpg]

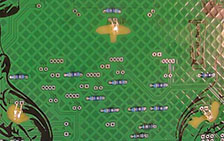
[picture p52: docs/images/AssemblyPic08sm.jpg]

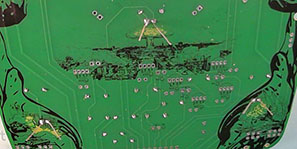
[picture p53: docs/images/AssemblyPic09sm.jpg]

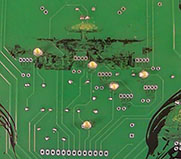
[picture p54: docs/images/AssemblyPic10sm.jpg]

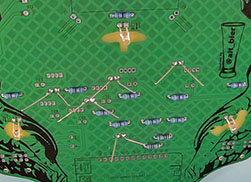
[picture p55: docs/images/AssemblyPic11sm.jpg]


* Addressable Neopixel 5mm 4-Pin LEDs
  * The eight Neopixel LEDs are a bit more difficult to solder given the pins are close together
  * These LEDs are polar and must be placed in the proper direction.  Each of the four legs has a different length.  One leg is longer than all the others in one of the middle positions away from the shortest leg.
    * The PCB silk has drawings of all four legs with thier lengths and positions as a guide for each LED.
    * The PCB solder pad shapes provide another guide as the longest leg should always go towards the square hole (one position over from it)
  * These eight LEDs are labeled D10-13, and D20-23 on the frot side of the PCB
  * Place the LEDs in thier designated places on the front side of the PCB
    * Make sure to align the LEDs properly using the silk guide to place longest leg one position over from the square hole
    * Solder all the LED connections
    * When cooled cut the component legs off at the top of the solder joints (do not cut into the solder joint)

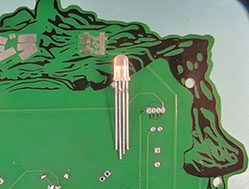
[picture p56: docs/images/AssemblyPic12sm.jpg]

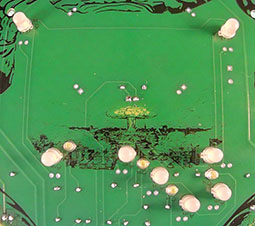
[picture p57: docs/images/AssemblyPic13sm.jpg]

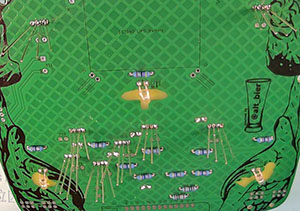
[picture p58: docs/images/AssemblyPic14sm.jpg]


* Capacitors
  * The eight capacitors are tan colored 2.5mm wide 2 pin 100nF non-polar ceramic disc capacitors (that look like Ibuprofen tablets) which are labeled C10-13, and C20-23 on the back side of the PCB
  * Place all the capacitors in thier designated places on the PCB bending legs out to hold in place
  * These are non-polar so they can be placed in either direction.
  * Solder all the capacitor connections
  * The large ground plane makes one of the pins take a bit longer to heat up and the thin legs and larger pads make for uneven heating.  So, take a little more time to make sure these have a good connection.
  * Watch the position of your iron as you solder these since they are close to LEDs that you don't want to damage.
  * When cooled cut the component legs off at the top of the solder joints (do not cut into the solder joint)

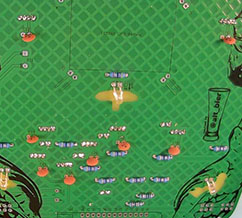
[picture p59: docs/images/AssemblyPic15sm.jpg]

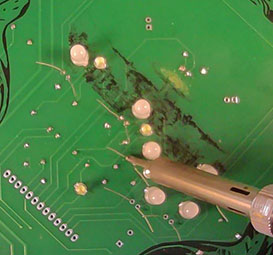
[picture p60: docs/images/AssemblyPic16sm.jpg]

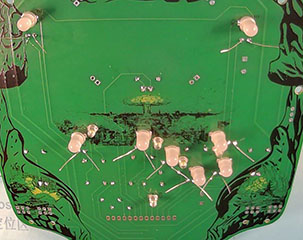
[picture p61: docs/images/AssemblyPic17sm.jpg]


* Switch for battery power
  * The battery power switch is a 3-pin SPDT switch with a 5mm lever and right angle pins
  * Place the switch in its designated place on the back side of the PCB with the lever pointing towards the PCB edge. 
  * You might need to tilt it a bit to allow the pins to stick through the PCB enough to easily solder them.
  * Solder all the switch connections

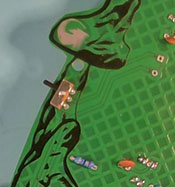
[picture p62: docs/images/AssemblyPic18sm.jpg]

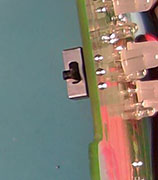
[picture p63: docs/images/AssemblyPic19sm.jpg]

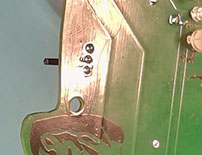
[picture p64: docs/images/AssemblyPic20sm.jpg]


* Battery Holder Right Angle Male Headers
  * The four 2.54mm 1x2 Pin Right Angle Male Headers are used with a rubber band to secure the lipo battery and are labeled J2-5 on the back side of the PCB
  * Place the short side of the header pins into the designated positions on the PCB with the long side pointing away from where the battery will be placed later.
  * Solder all the connections
  * It may be tricky to solder them while keeping them from pressing against the PCB, try soldering only one pin then adjust the header while applying heat to that pin

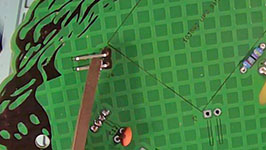
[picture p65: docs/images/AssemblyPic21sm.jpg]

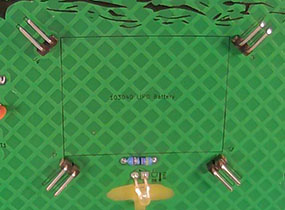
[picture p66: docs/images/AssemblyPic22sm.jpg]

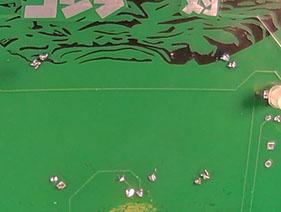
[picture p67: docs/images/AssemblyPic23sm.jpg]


* SAO Female Keyed 2x3 Headers
  * The four 2.54mm 2x3 Pin Keyed Female Headers are labeled JSAO1-2 on the front side of the PCB and JSAO3-4 on the back side of the PCB
  * The two headers on the back side of the PCB will be placed further towards the middle of the PCB than the two on the front side which are placed closer to the edges of the PCB.
  * All of the headers should be placed with thier key notch towards the top of the PCB as indicated by the drawing in the PCB silk (which might be difficult to see given all the art near it).
  * It is best to place and solder each of these individually

BadgeSAOs
BadgeSAOs
BadgeSAOs
BadgeSAOs
BadgeSAOs
BadgeSAOs
BadgeSAOs
BadgeSAOs

* The ESP32 development board
  * This is a 26 pin ESP32 WeMos Lolin32 development board with two 1x13 pin male header strips
  * Place the male header pins into the ESP32 dev board with the longer pins being inserted into the board (which is inverse of how they would normally be attached if plugging this into female headers or a bread board)
  * Placing this onto a small bread board while soldering ensures that the headers maintain the required 90 degree angle.  Otherwise you should solder only one pin on each side adjusting the angle while applying heat to get a 90 degree angle before continuing with the remaining pins.
  * Solder all the connections on the ESP dev board
  * When cooled place the ESP32 dev board into the back side of the PCB
  * Make sure to place the ESP32 in its designated place on the PCB and ensure it is aligned properly according to the silk drawing on the badge PCB (look at the USB and Battery connector symbols drawn in silkscreen)
  * Solder all the connections

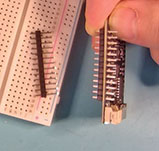
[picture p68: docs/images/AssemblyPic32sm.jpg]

ESP32Dev
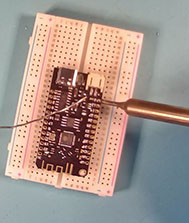
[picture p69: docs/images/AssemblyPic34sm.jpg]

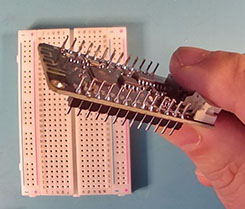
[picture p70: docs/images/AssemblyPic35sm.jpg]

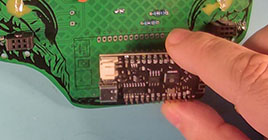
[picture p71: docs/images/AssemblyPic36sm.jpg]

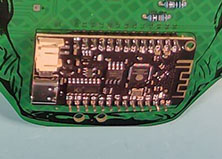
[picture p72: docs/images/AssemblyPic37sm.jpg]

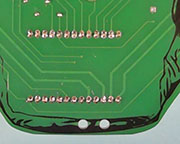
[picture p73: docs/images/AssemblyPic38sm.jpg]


* ESP32 Battery Power Wires
  * The ESP32 power wire connections are labeled J1 on the back side of the PCB
  * The ESP32 development board has a JST mini PH battery power connector which needs to be connected to J1 on the PCB
  * The JST mini PH connector is keyed allowing it to only be plugged into the ESP32 dev board one way
  * You can plug the connector into the ESP32 dev board to measure where to cut these wires to size, do not cut them too short or leave too much slack.
  * Disconnect the connector before attaching and soldering the wires.
  * WARNING: Unfourtunatley the JST mini PH Connector Wires that were available for this project had the red and black wires in the WRONG positions for this ESP32 dev board.
    * This means that the red wire which is usually an indication of Positive power is actually aligned with the Ground/Negative power terminal on the ESP32 dev board and visa versa for the black wire.
    * When connecting these wires to the badge PCB J1 pads you will need to connect the RED TO GND (round pad) and BLACK TO + (square pad)
    * Failure to do this will result in REVERSE POLARITY that will DESTROY the ESP32 dev board.
    * Reminder labels have been attached to these wires as a WARNING
  * Solder the connections
  * When cooled trim any excess wire at the top of the solder joints (do not cut into the solder joint)
  * Verify that the connector can reach to be plugged into the ESP32 dev board (you might need to twist the connector around to line it up)
  * Be sure to disconnect this connector since we do not want it connected when working with the LIPO Battery

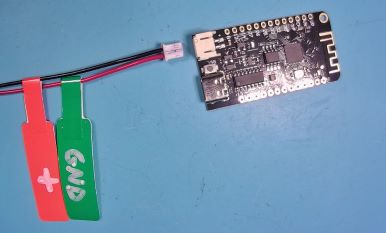
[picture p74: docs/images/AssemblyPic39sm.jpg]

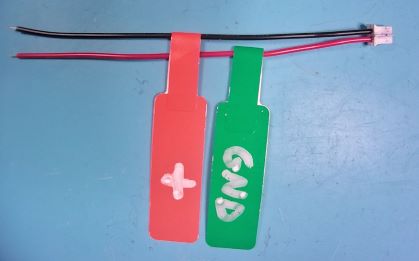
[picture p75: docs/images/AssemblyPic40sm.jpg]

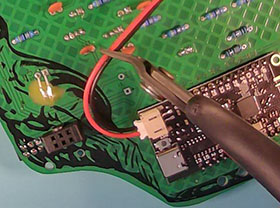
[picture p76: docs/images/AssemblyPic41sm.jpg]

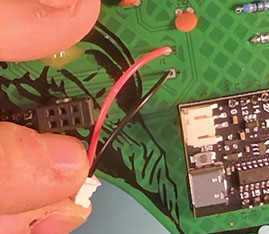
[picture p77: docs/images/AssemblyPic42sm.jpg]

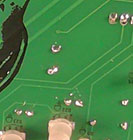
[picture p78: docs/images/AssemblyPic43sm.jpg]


* LIPO Battery
  * The LIPO Battery has a charge so you need to be careful when working with it
    * Make sure not to touch the battery wires together by only stripping and soldering one wire at a time
    * Make sure battery power will not be applied to the badge by ensuring the ESP32 battery connector is disconnected and the badge switch is in the off position (towards the center of the badge)
  * The battery power wire connections are labeled BT1 on the back side of the PCB
  * Strip the tip of the BLACK battery wire and insert it into BT1 on the badge PCB in GND (round pad)
  * Solder this wire to the PCB
  * Strip the tip of the RED battery wire and insert it into BT1 on the badge PCB in + (square pad)
  * Solder this wire to the PCB
  * Place the battery onto the PCB within the designated square drawn in silk on the PCB
  * Attach a rubber band over the battery between the male header pins in J2 and J5
  * Attach a rubber band over the battery between the male header pins in J3 and J4
  * Plug in the ESP32 power connector

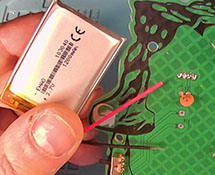
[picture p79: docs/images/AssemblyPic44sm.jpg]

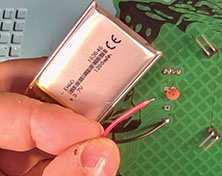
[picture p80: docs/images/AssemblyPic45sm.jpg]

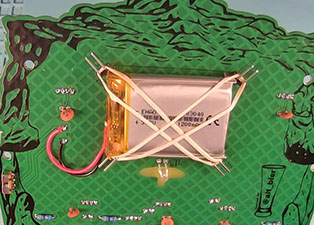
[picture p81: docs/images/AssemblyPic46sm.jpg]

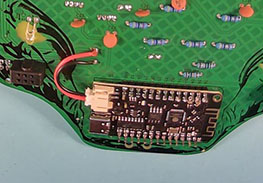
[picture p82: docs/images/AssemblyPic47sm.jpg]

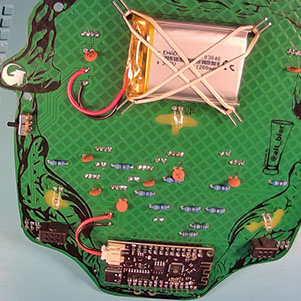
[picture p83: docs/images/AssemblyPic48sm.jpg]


* Testing
  * Turn on the badge and make sure all the LEDs light up
  * If any of them do not then turn the badge off, make any necessary corrections and try again.
  * Turn the badge off when done before connecting the three PCBs

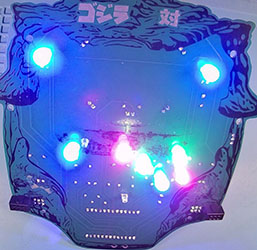
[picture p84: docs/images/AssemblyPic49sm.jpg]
Test


* PCB Stack Assembly
  * Attach all the standoffs to the middle PCB using M3 screws
    * Take note of which standoffs need to go on which side of the middle PCB
    * The higher side holes are aligned with the rear PCB so these standoffs will go on the back side of the middle PCB
    * The lower side holes (near the power switch) are aligned with the front PCB so these standoffs will go on the front side of the middle PCB
    * The bottom holes have the centered one aligned with the front PCB and the off center one aligned with the rear PCB so place those standoffs in the proper sides of the middle PCB
  * Attach the rear PCB to the middle PCB using M3 screws into the standoffs
  * Attach the front PCB to the middle PCB using M3 screws into the standoffs
  * Screw down the M3 screws resonably tight so they do not come loose easily, but DO NOT over tighten as this could strip the plastic screw or even crack the PCB

Stack
Stack
Stack
Stack
Stack
Stack
Stack

## Assembly Steps for the SAOs

* Break apart the PCBs on the mouse bites
  * To provide an even break line placing one PCB on a hard surface (like a desk) and pushing down on the other PCB works well
  * Break off the mouse bites from the PCB(s) that they are still attached to
  * Mini pliers are helpful but not required
  * The rough edges can be filed or sanded down if a smooth edge is preferred

SAOPanel
SAOPanel
SAOPanel
SAOPanel

* All of these SAOs are almost identical in assembly
  * The only real difference being the resistance value of a single resistor on the SAO
  * The component labels reflect the SAO number in them so that R1 on the second SAO would be labeled R21 and D1 on the third SAO would be labeled D31
  * The following instructions will reference the components simply without the SAO number (e.g. R1, D1)

* Resistors
  * Each SAO has two 47-Ohm resistors labeled R1-R2 on the PCB
  * Each SAO has one unique value resistor labeled R3 on the PCB
    * Mothra = 10K Ohm
    * King Ghidorah = 47K Ohm
    * Rodan = 100K Ohm
    * Hedorah = 220K Ohm
  * Resistors are non-polar so they can be placed in either direction.
  * Place all the resistors into the back side of the PCB bending thier legs outward on the front side to hold them in place
  * Solder all the resistor connections on the front side of the PCB.
  * When cooled cut the component legs off at the top of the solder joints (do not cut into the solder joint)

Resistors
Resistors

* One Color (White) 3mm 2 pin LEDs
  * LEDs are polar and must be placed in the proper direction.  They have one leg longer than the other to indicate the cathode and anode legs.
    * The PCB silk has drawings of the short and long pin positions as a guide for each LED.
    * The PCB solder pad shapes provide another guide as the short leg should always go in the square hole
  * Each SAO has two of these LEDs labeled D1-2 on the PCB
    * These LEDs need to be bent over for specific positioning on the PCB so be careful with placement
    * Place these LEDs into thier labeled positions on the back side of the PCB
    * Make sure to align the LEDs properly using the silk guide to place short leg in square hole, folding the LEDs in the direction indicated to place the body of the LED over the solder mask void on the PCB
    * Solder all the LED connections
    * When cooled cut the component legs off at the top of the solder joints (do not cut into the solder joint)

LEDs
LEDs
LEDs

* SAO Male Keyed Hooded 2x3 Headers
  * Each SAO has a 2.54mm 2x3 Pin Keyed Hooded Male Header are labeled JSAO on the back side of the PCB
  * The header should be placed with the key notch towards the top of the PCB as indicated by the drawing in the PCB silk
  * Solder all the header connections

SAOMale
SAOMale
SAOMale

## Final Assembly Steps

* Optional SAO Mini Lanyards
  * Place a mini lanyard on each SAO
    * Insert the thread side of the lanyard into on of the bottom SAO holes extending a small loop of lanyard thread
    * Feed the keyring side of the lanyard through the loop and pull tight
  * Connect the tiny keyrings from the SAO lanyards to the badge middle PCB holes at the bottom edge
    * Pry open the tiny keyring extending it over the edge of the badge PCB
    * Work the end of the keyring into the hole and work it around until the keyring is closed again connected to the badge
    * The keyrings are difficult to attach to the PCB but mini pliers can help
    * Only one keyring on each side needs to be connected to the PCB, the other two can be connected to the first two rings which is much easier to do

SAOminiLanyard
SAOminiLanyard
SAOminiLanyard
SAOminiLanyard

* Attach the badge lanyard
  * Attach the lanyard to the rear PCB of the badge using the lanyard aligator clips

Lanyard

* Enjoy!

Complete

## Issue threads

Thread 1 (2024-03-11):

GV Silkscreen Art

gowenrw, 2024-03-11:
Godzilla VS Silkscreen Art
Need to create new PS or AI art for the front silk layer of the GVbadge
Use images in art/inspiration/ for ideas of what is needed
While vector image is not required, the image should be black and white only with no grayscale, preferably with components in separate layers to allow for moving items around as needed without reworking the entire image.

Closed 2024-07-12.

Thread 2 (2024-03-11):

GV Circuit Design Planning

gowenrw, 2024-03-11:
Godzilla VS circuit design planning
Based on the badge concept requirements, plan at a high level:

- What circuit features do we need to include (e.g., capacitive touch, lip charging, etc.)
- What microcontroller would be the best fit
- What other major components would be needed

Document the high level plan including major component choices

Closed 2024-07-12.

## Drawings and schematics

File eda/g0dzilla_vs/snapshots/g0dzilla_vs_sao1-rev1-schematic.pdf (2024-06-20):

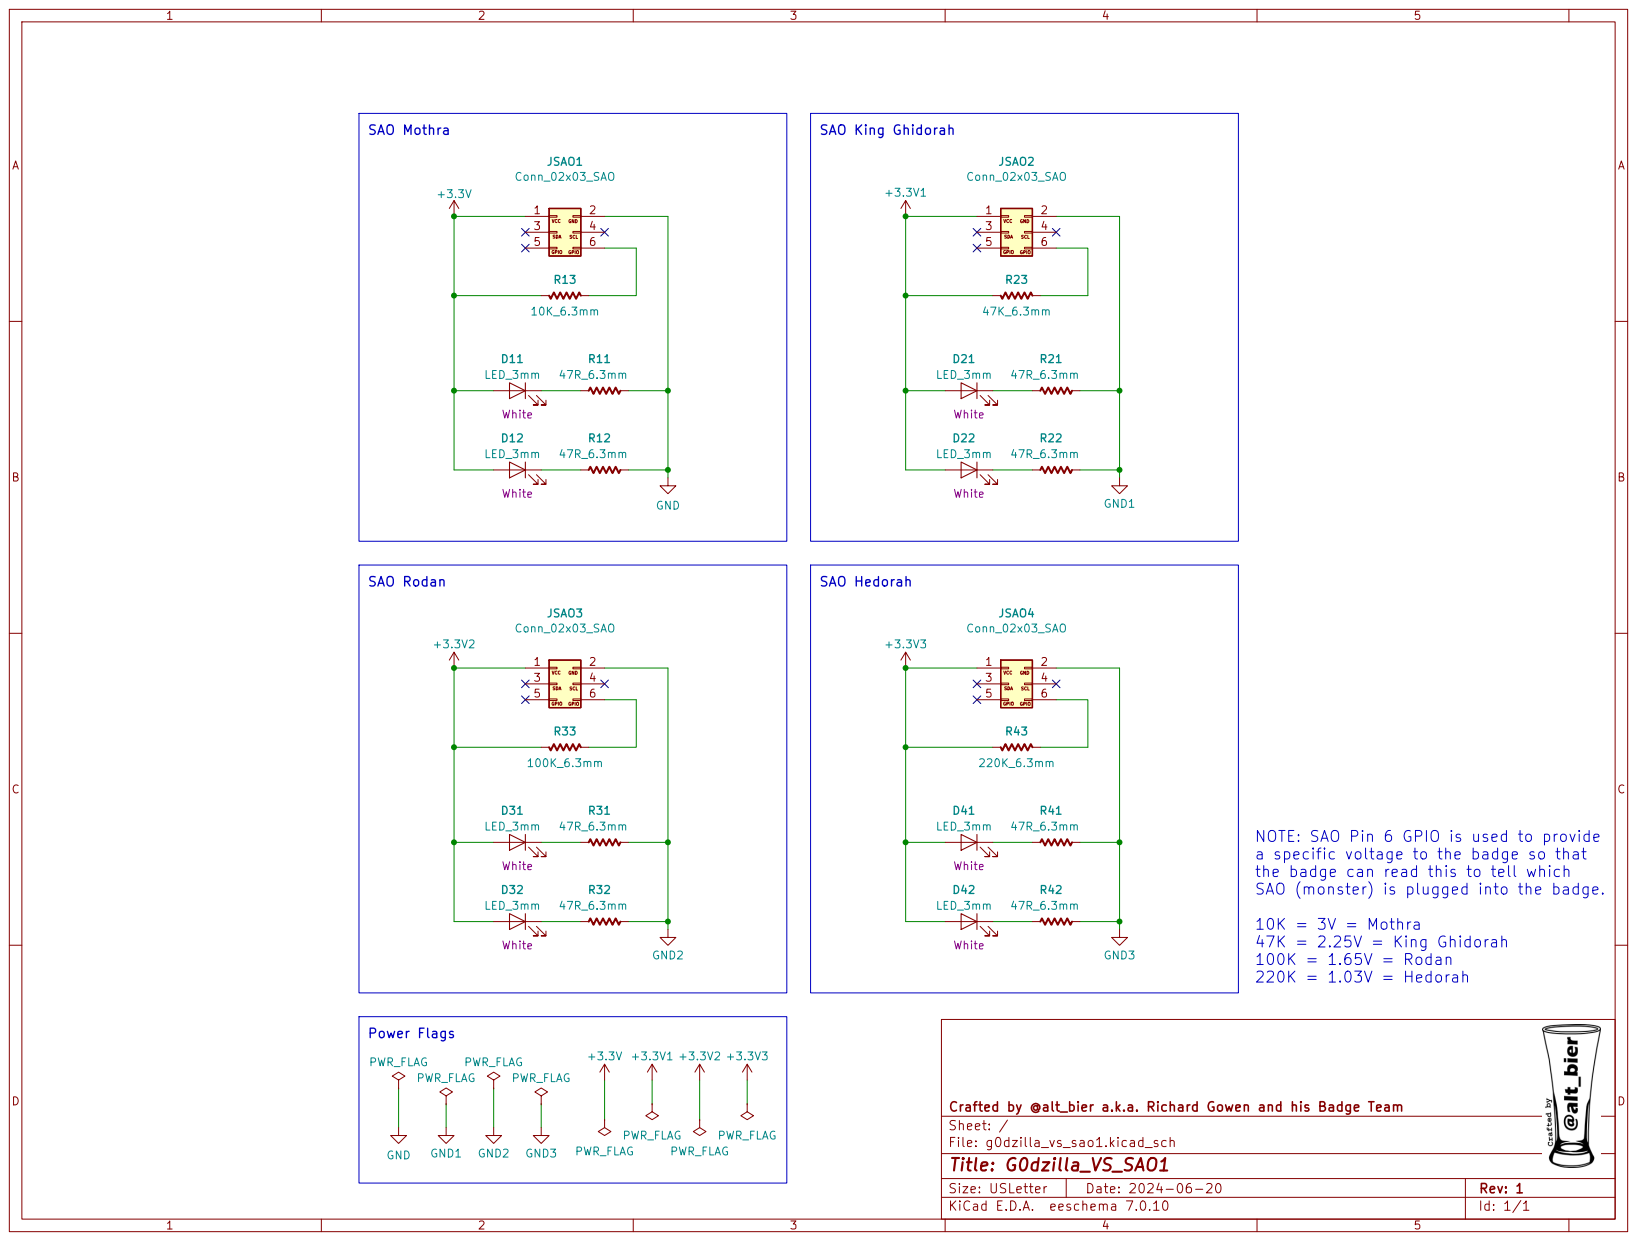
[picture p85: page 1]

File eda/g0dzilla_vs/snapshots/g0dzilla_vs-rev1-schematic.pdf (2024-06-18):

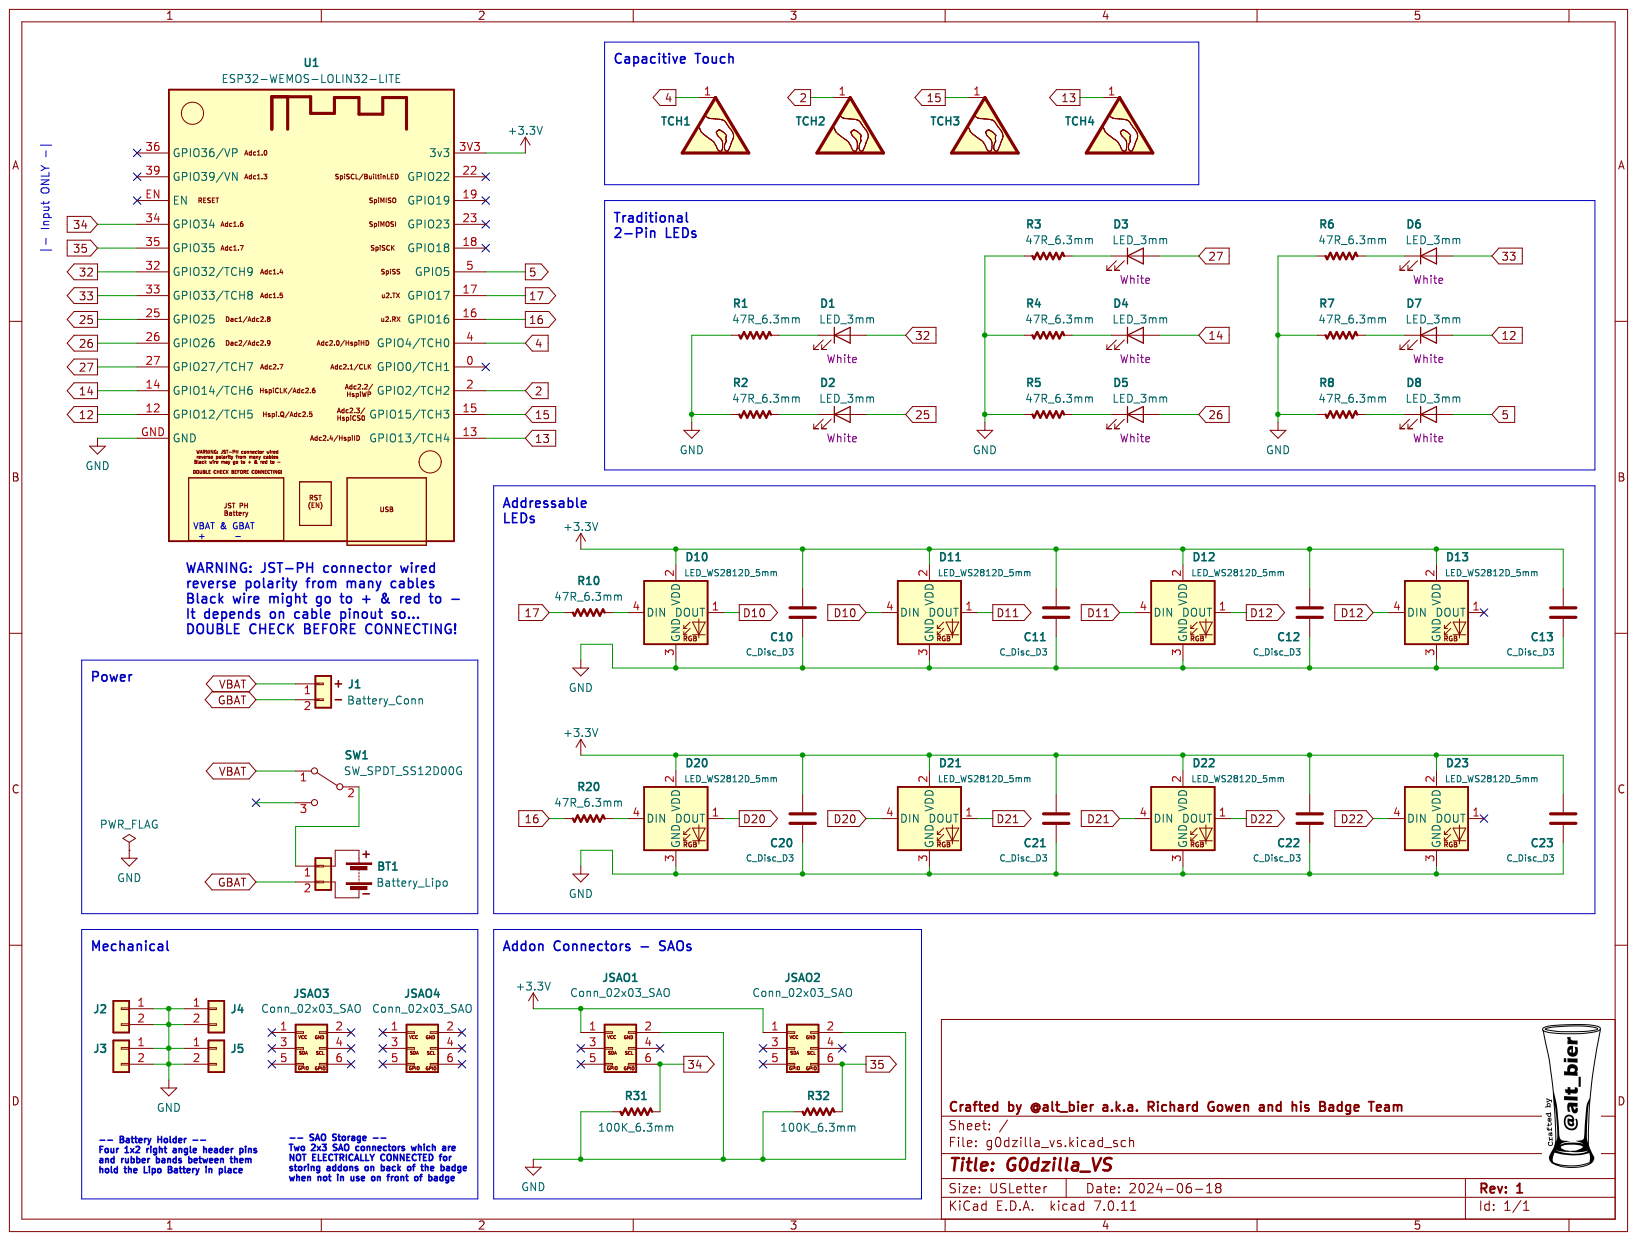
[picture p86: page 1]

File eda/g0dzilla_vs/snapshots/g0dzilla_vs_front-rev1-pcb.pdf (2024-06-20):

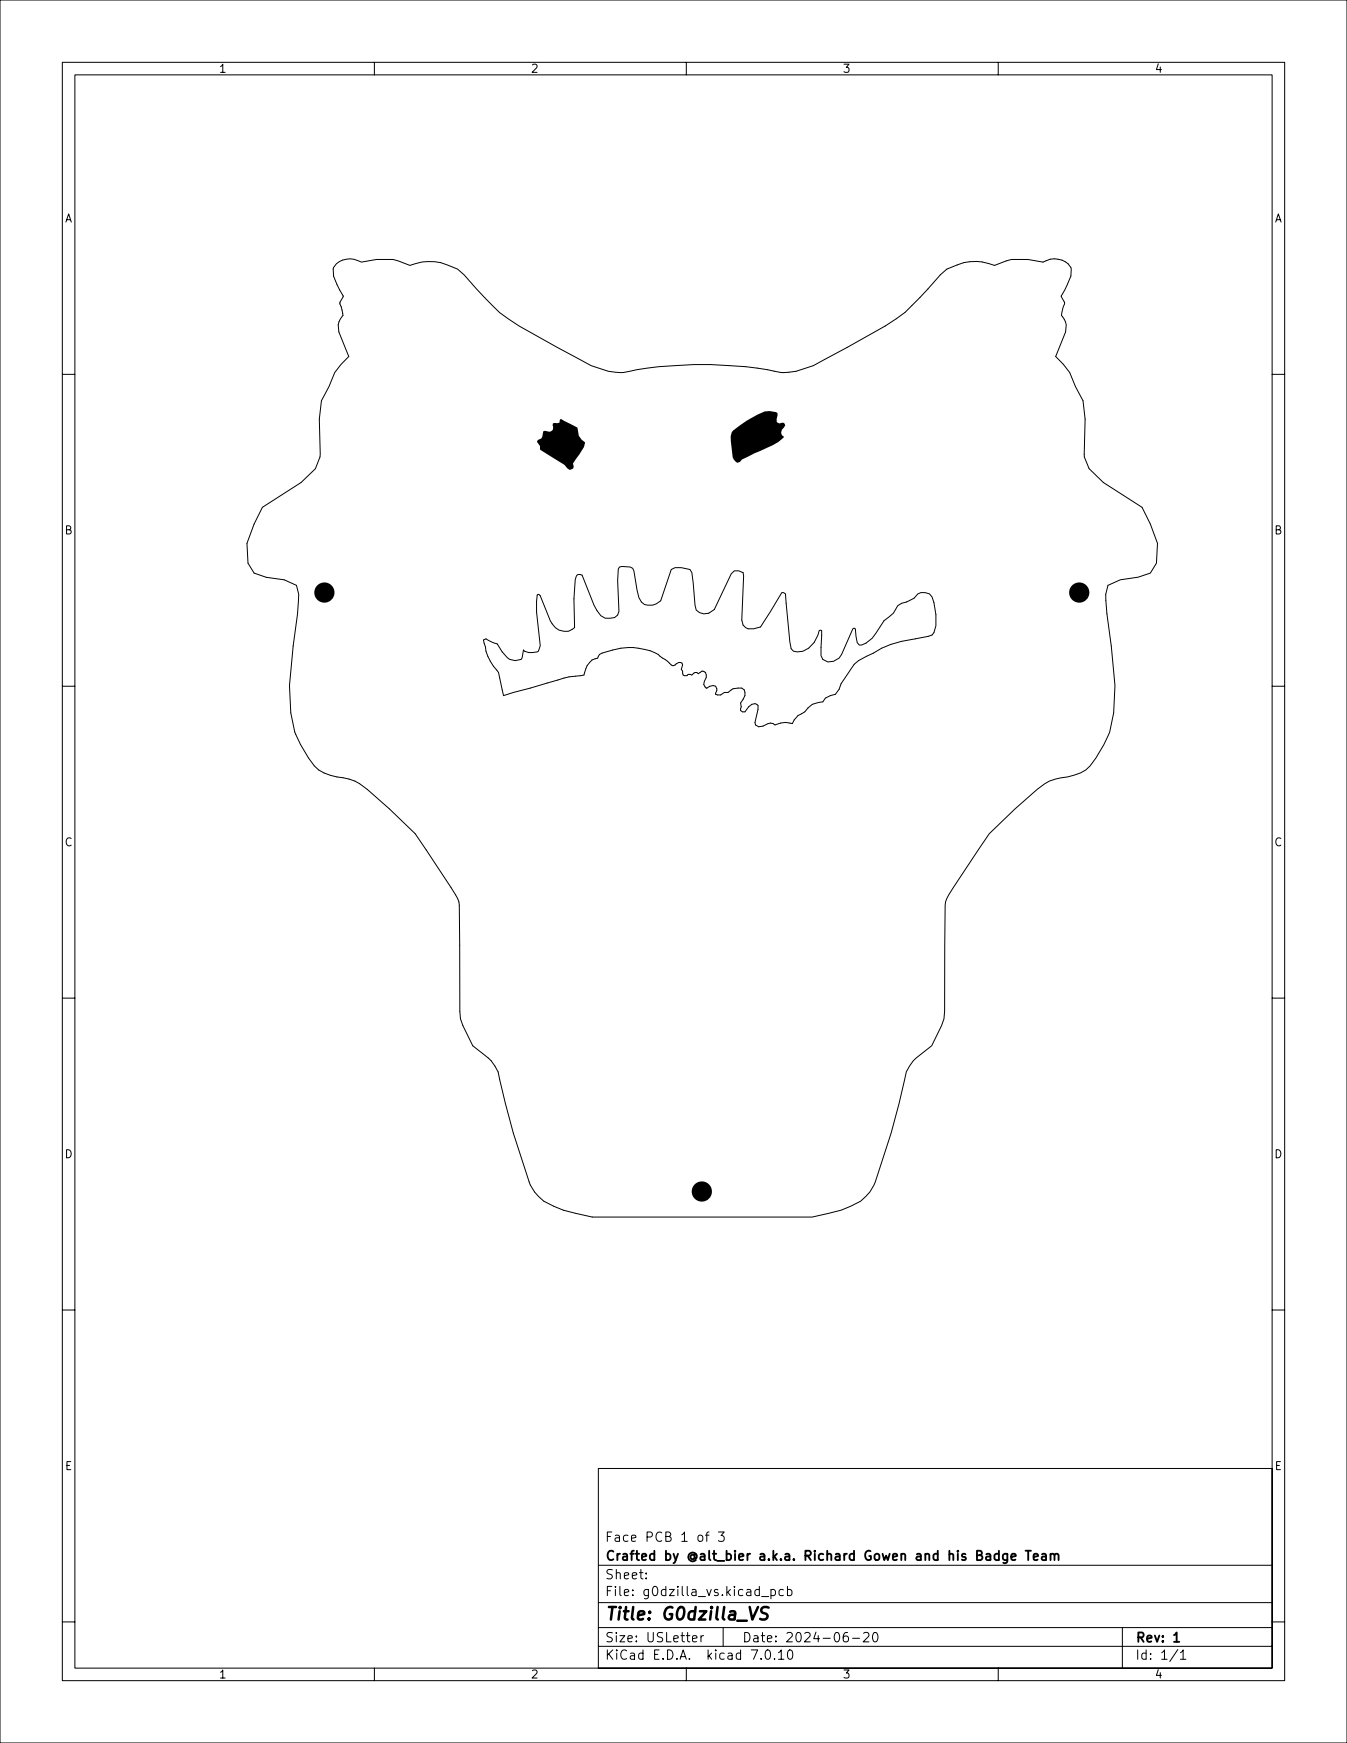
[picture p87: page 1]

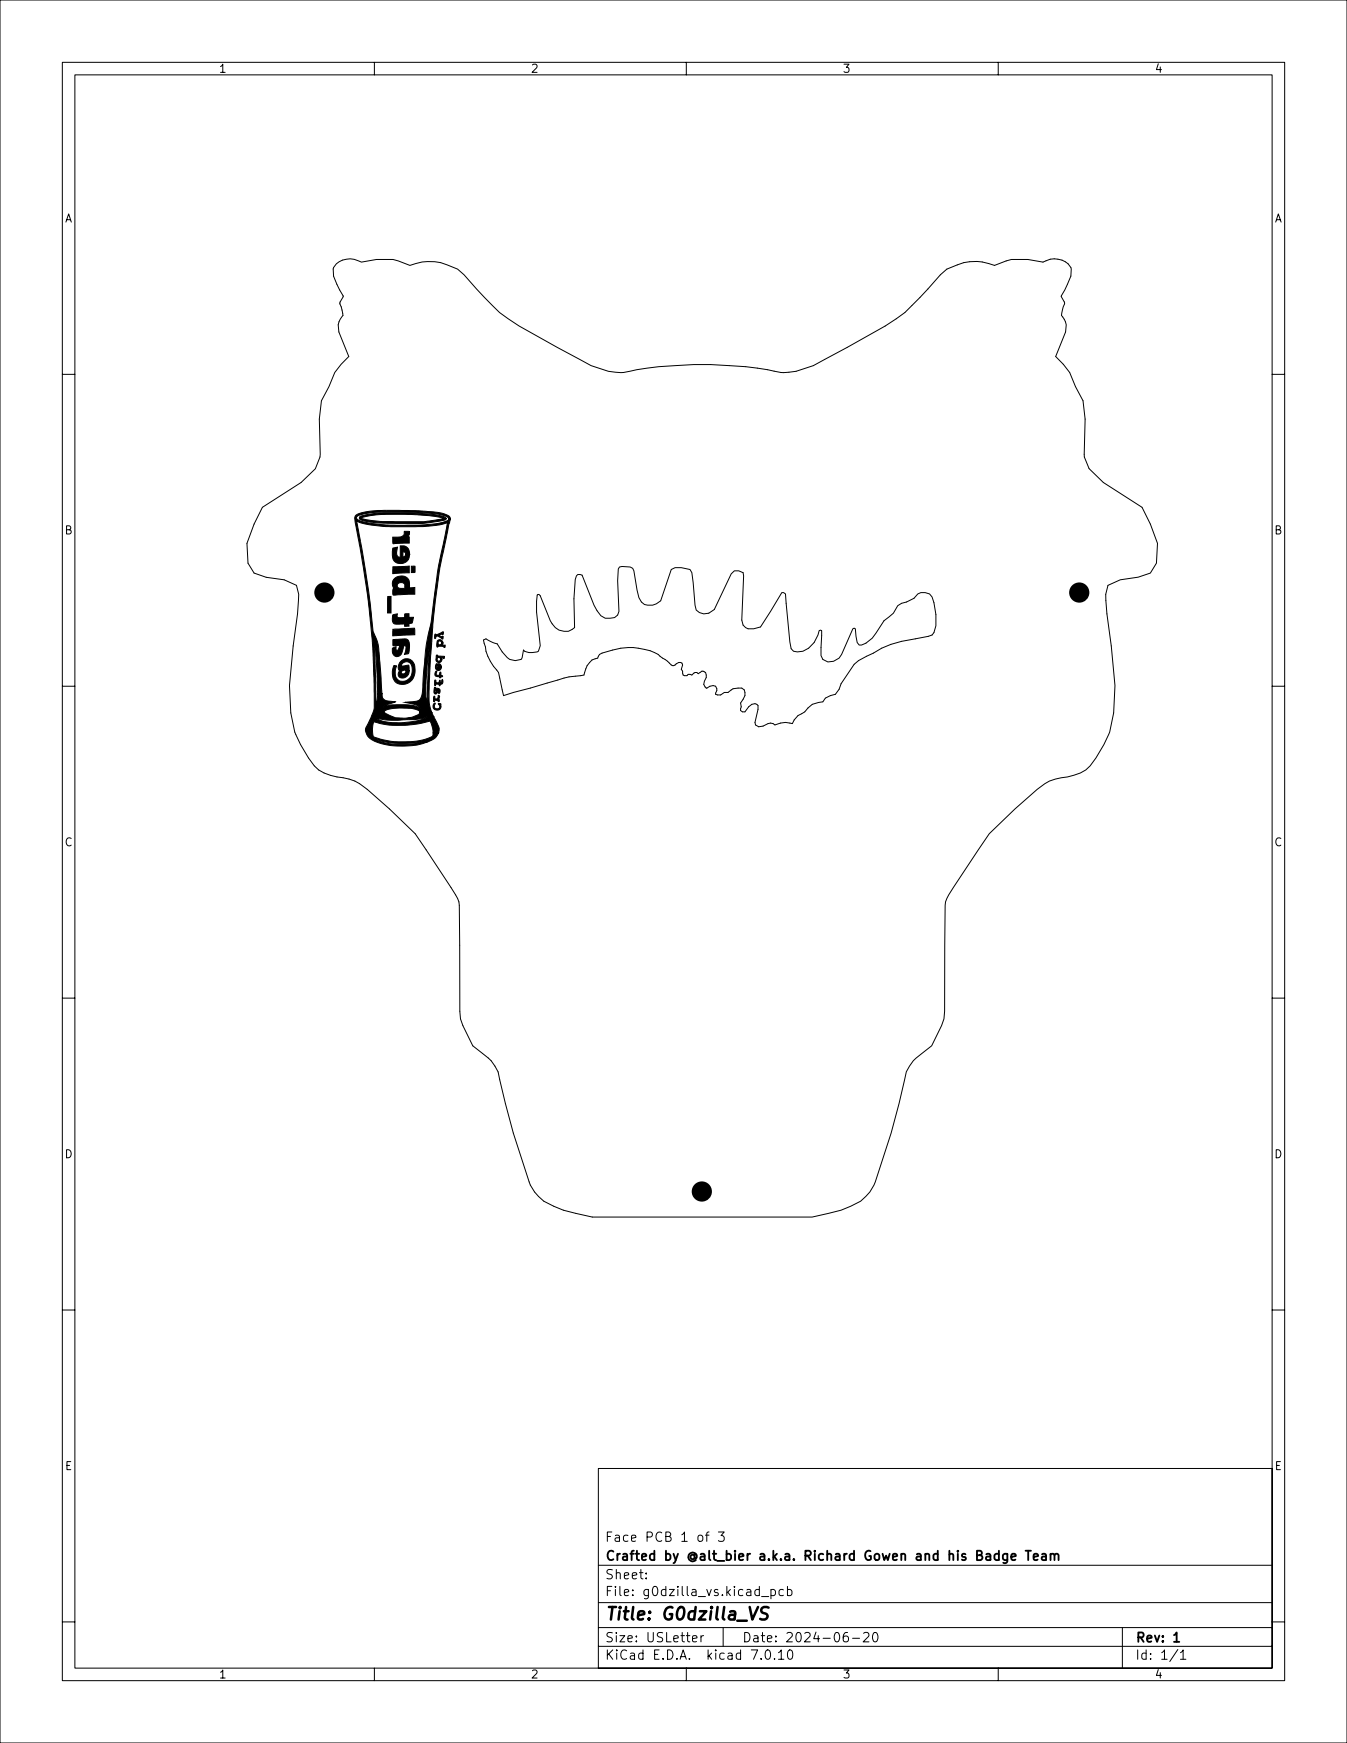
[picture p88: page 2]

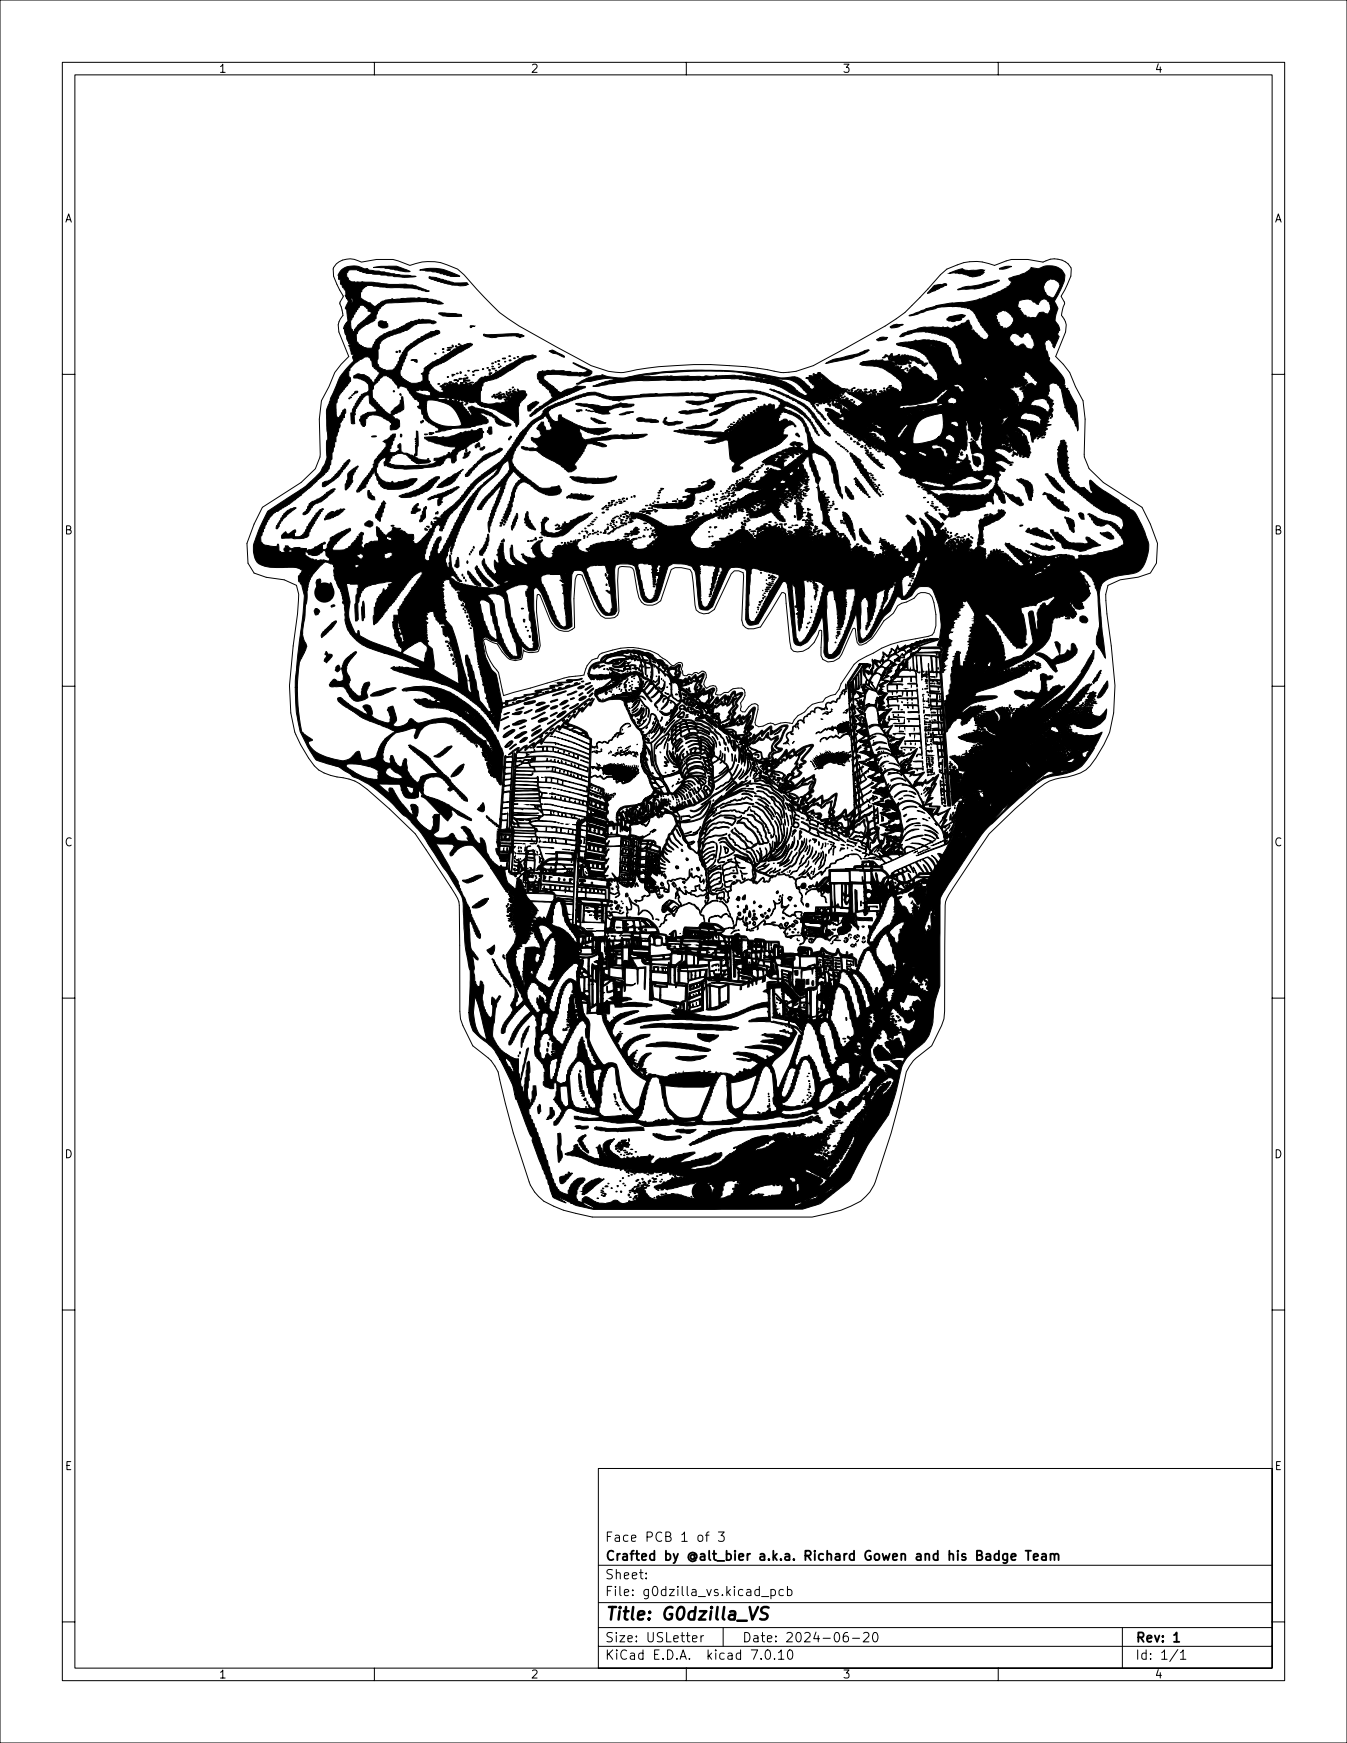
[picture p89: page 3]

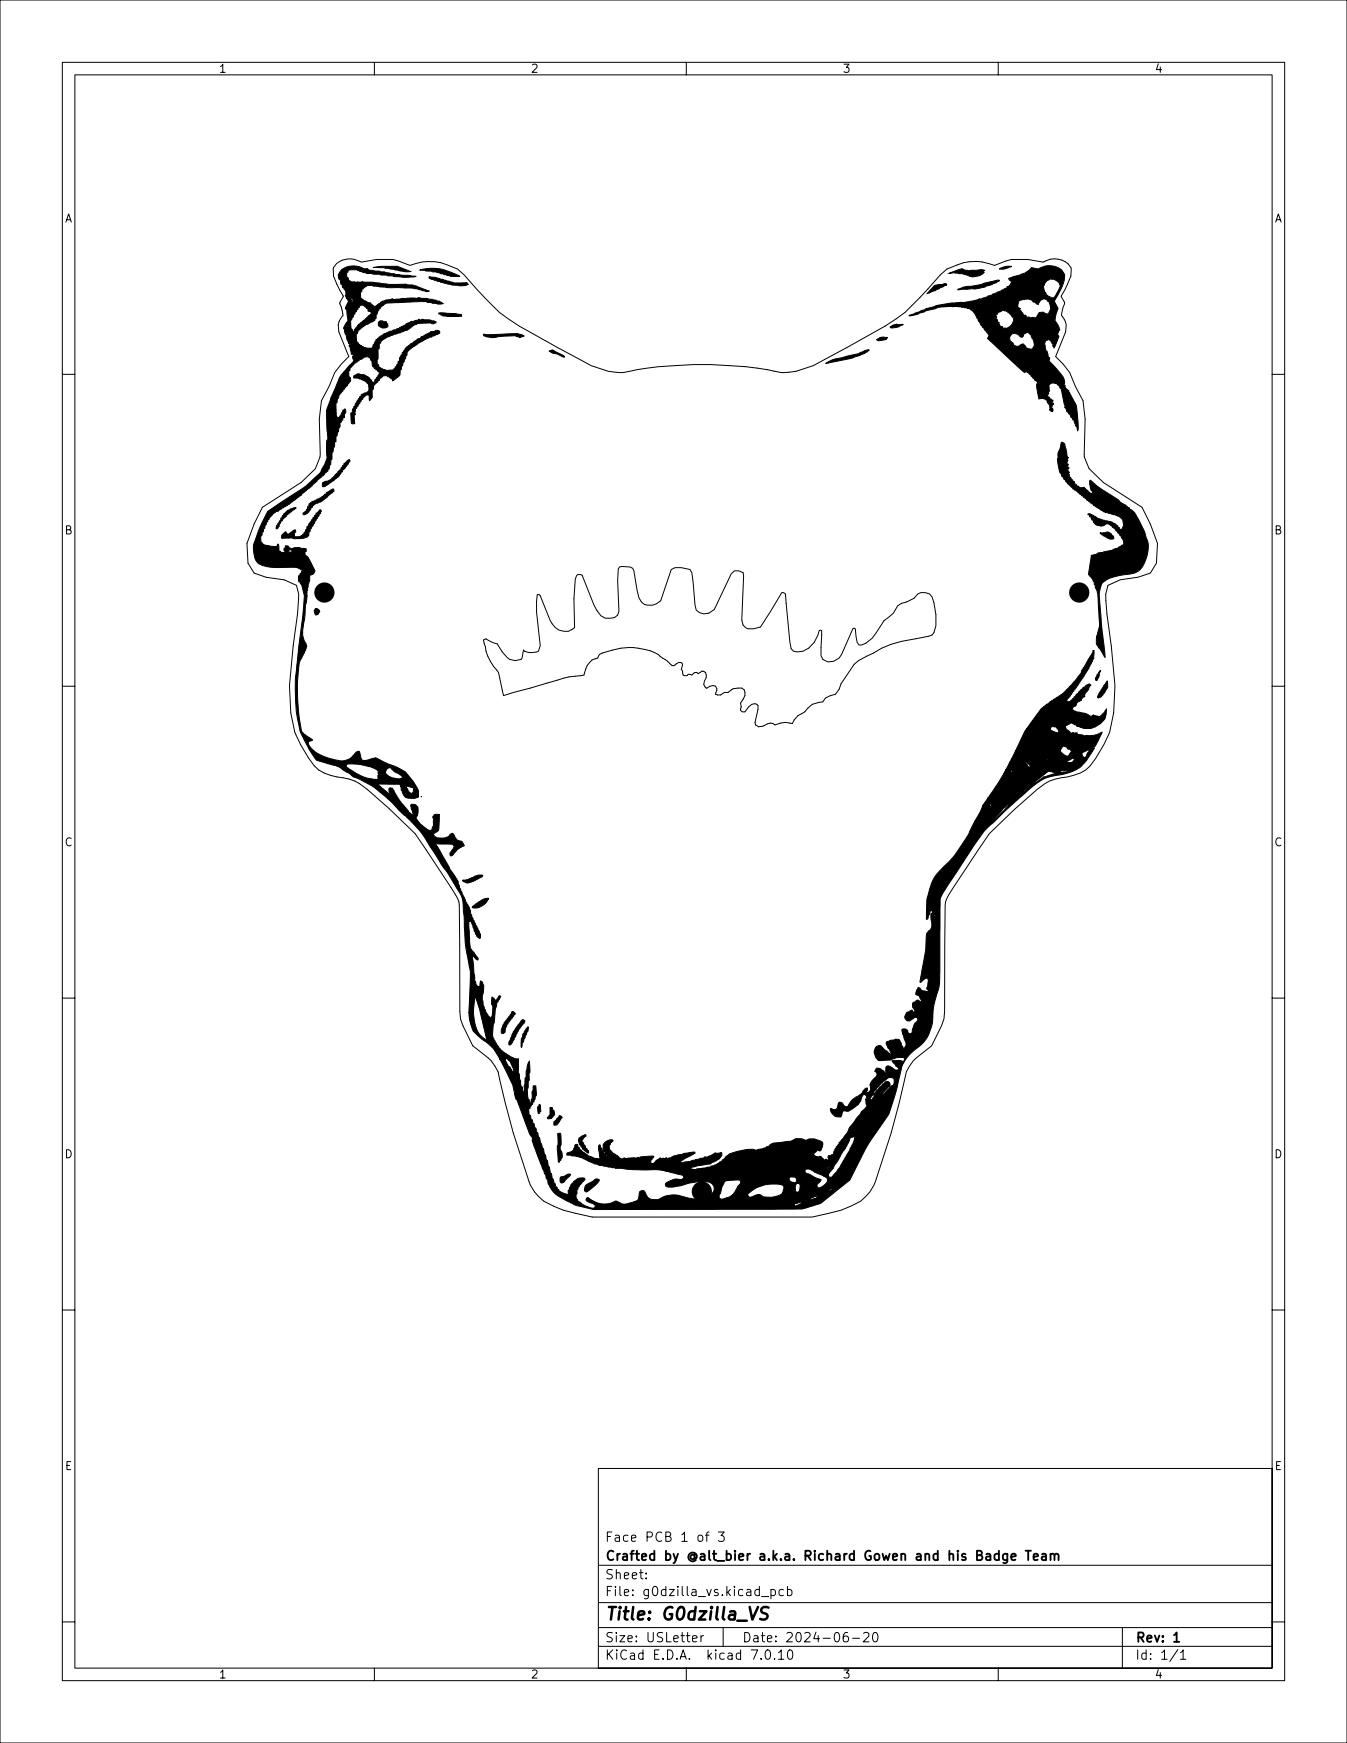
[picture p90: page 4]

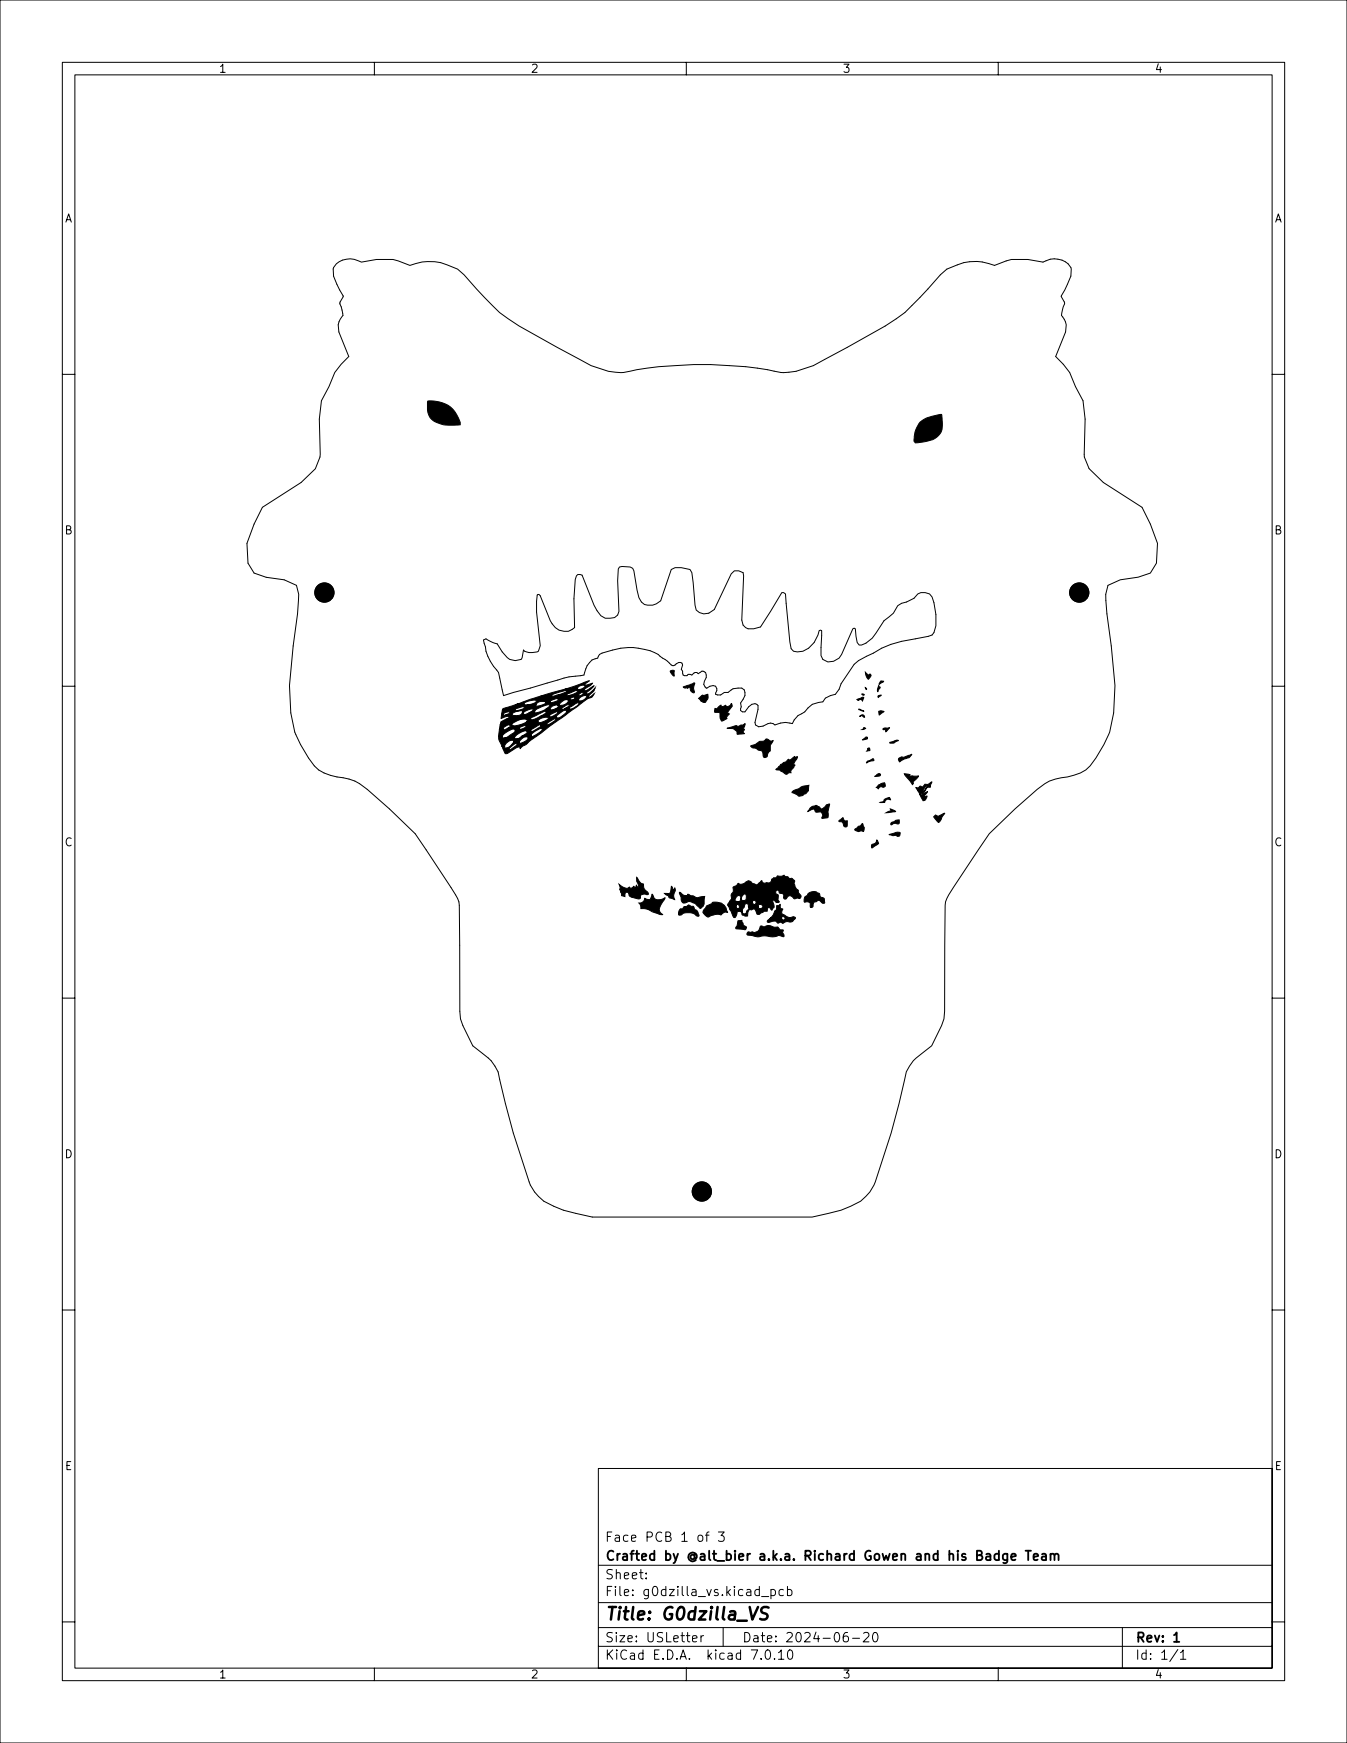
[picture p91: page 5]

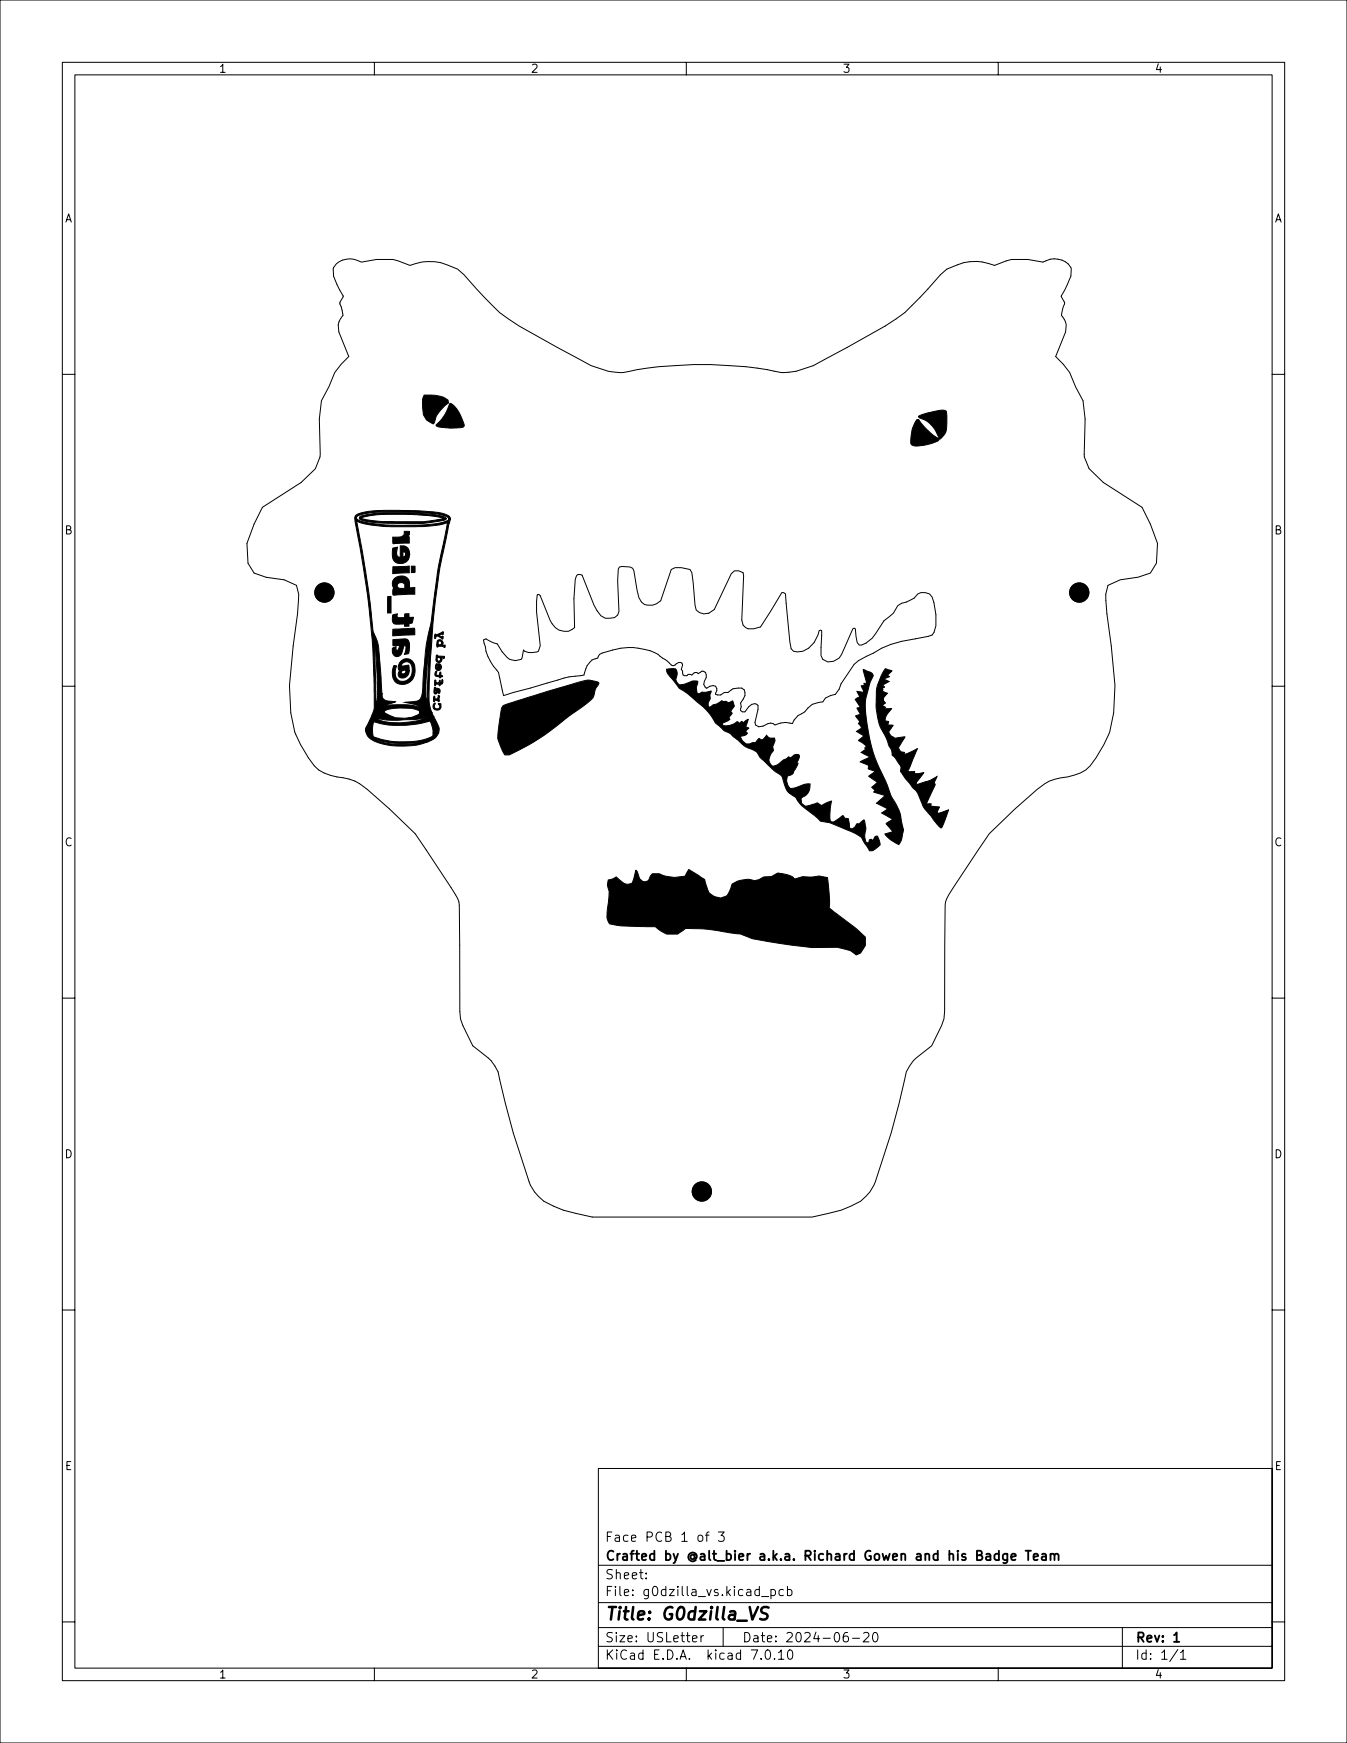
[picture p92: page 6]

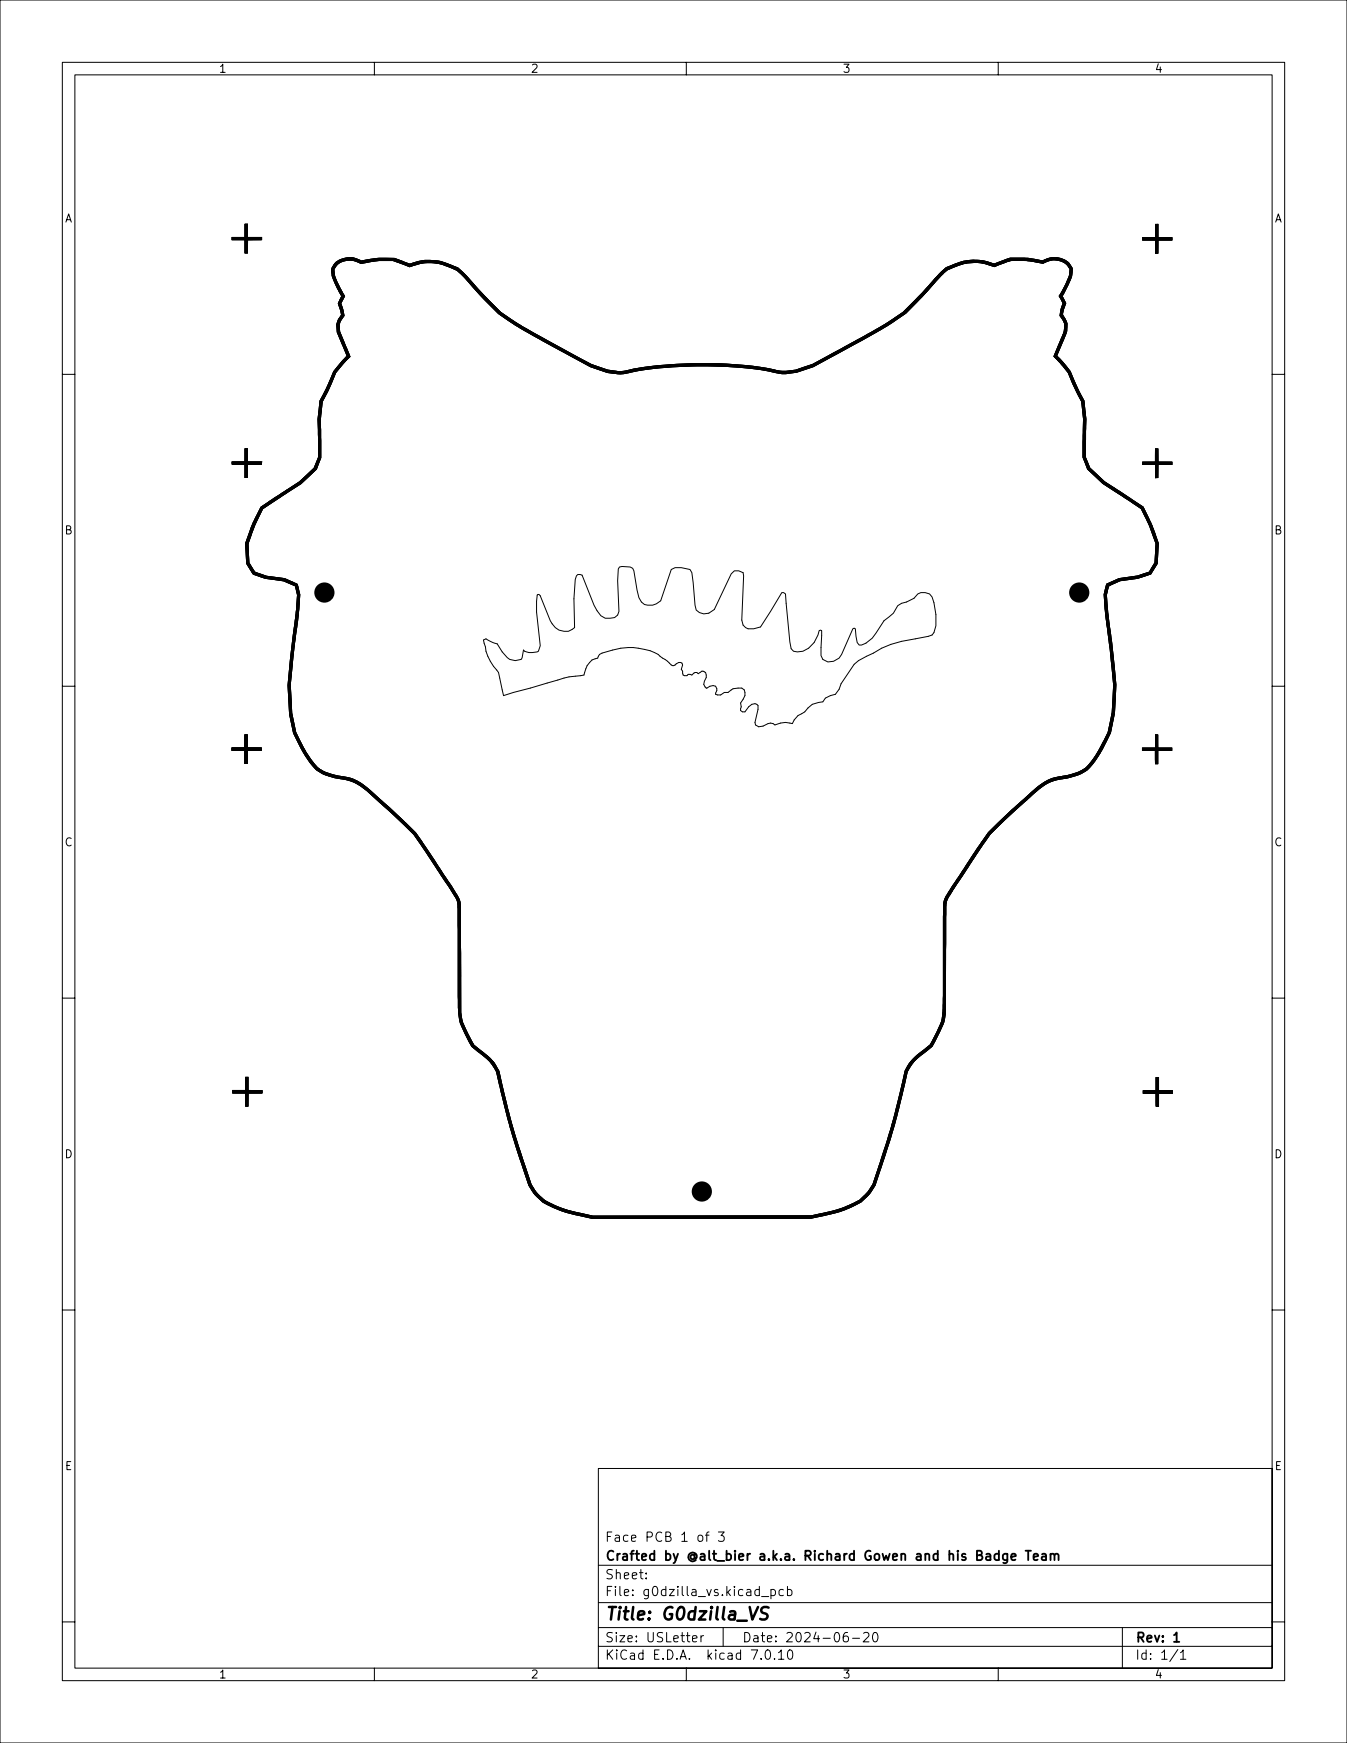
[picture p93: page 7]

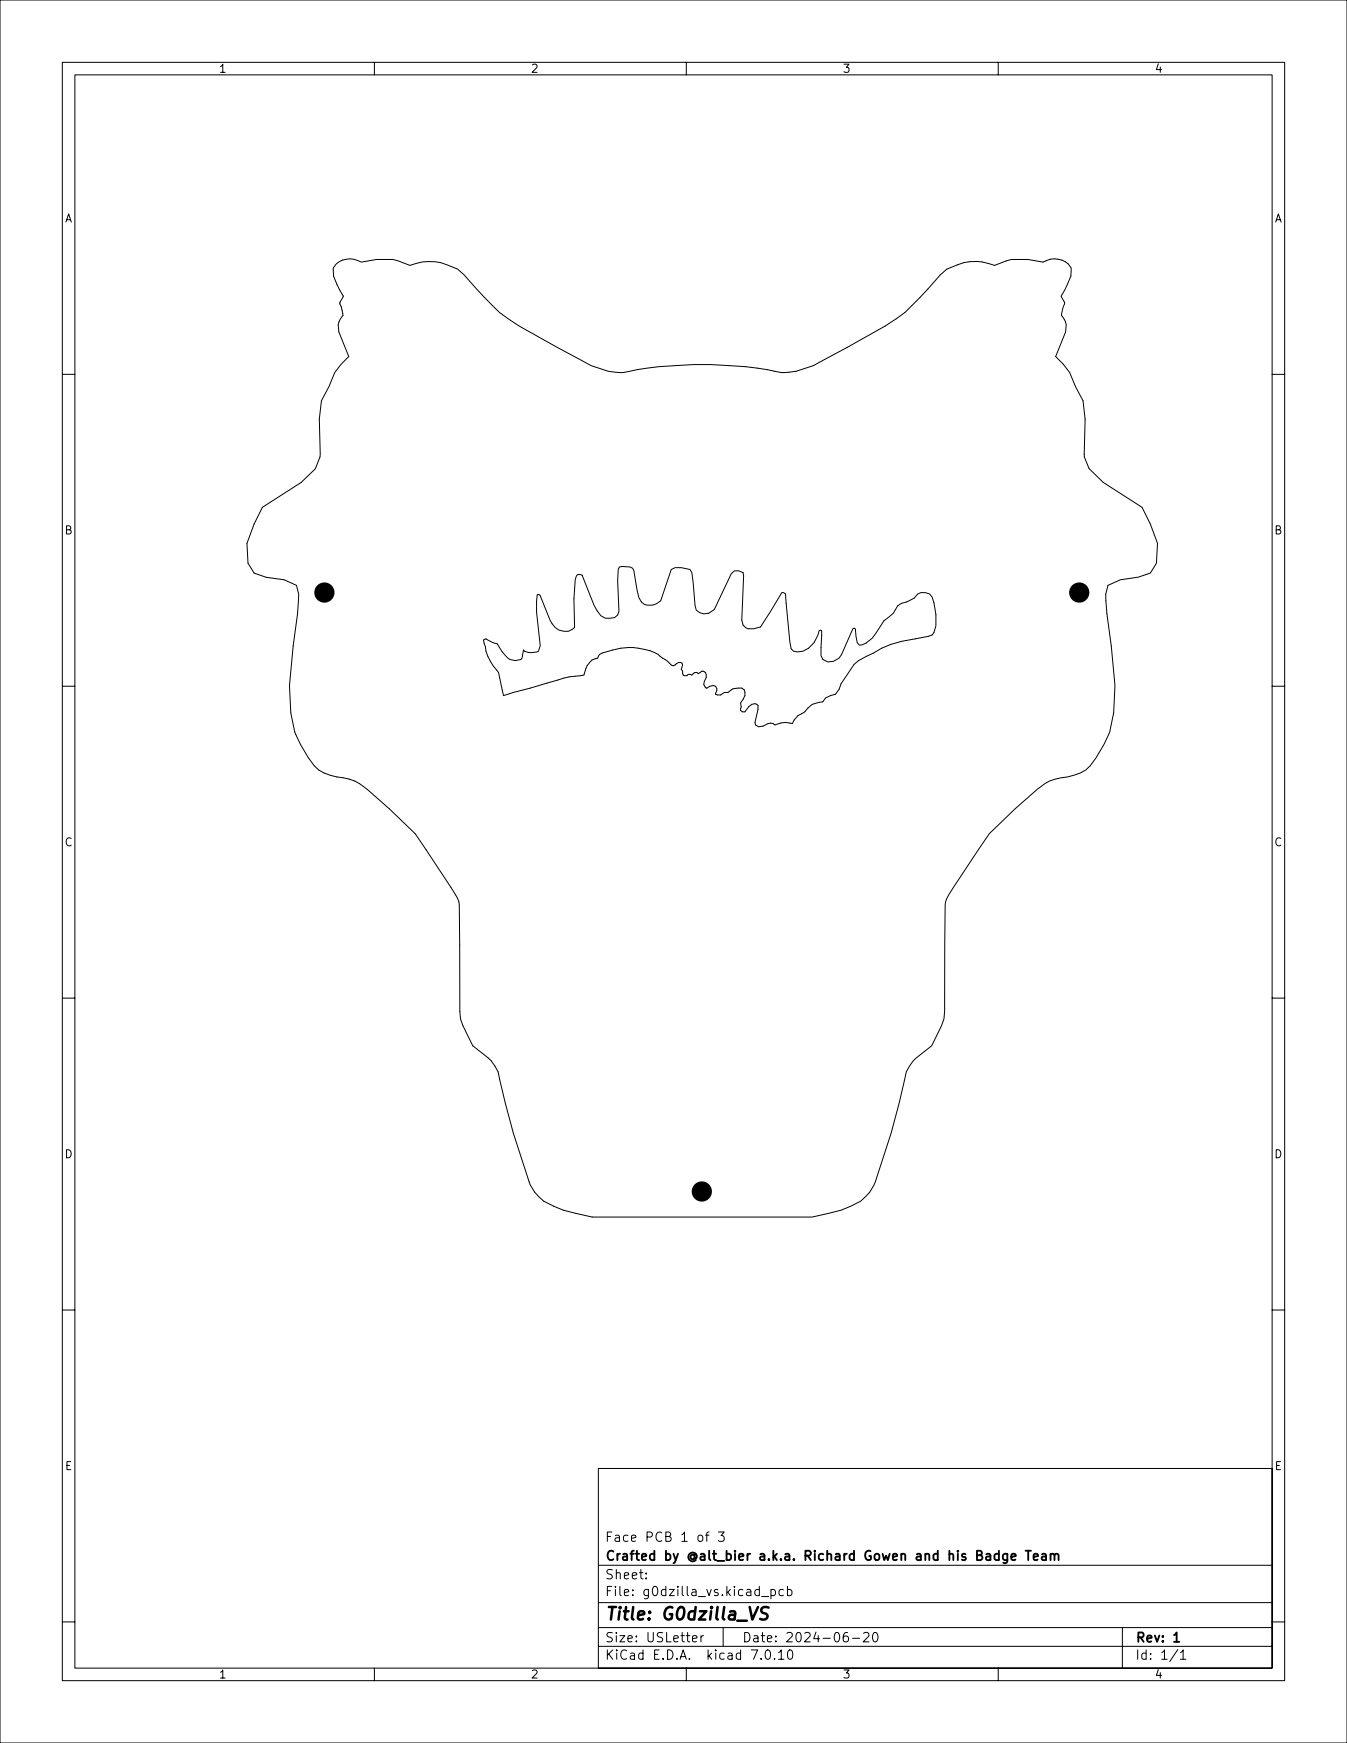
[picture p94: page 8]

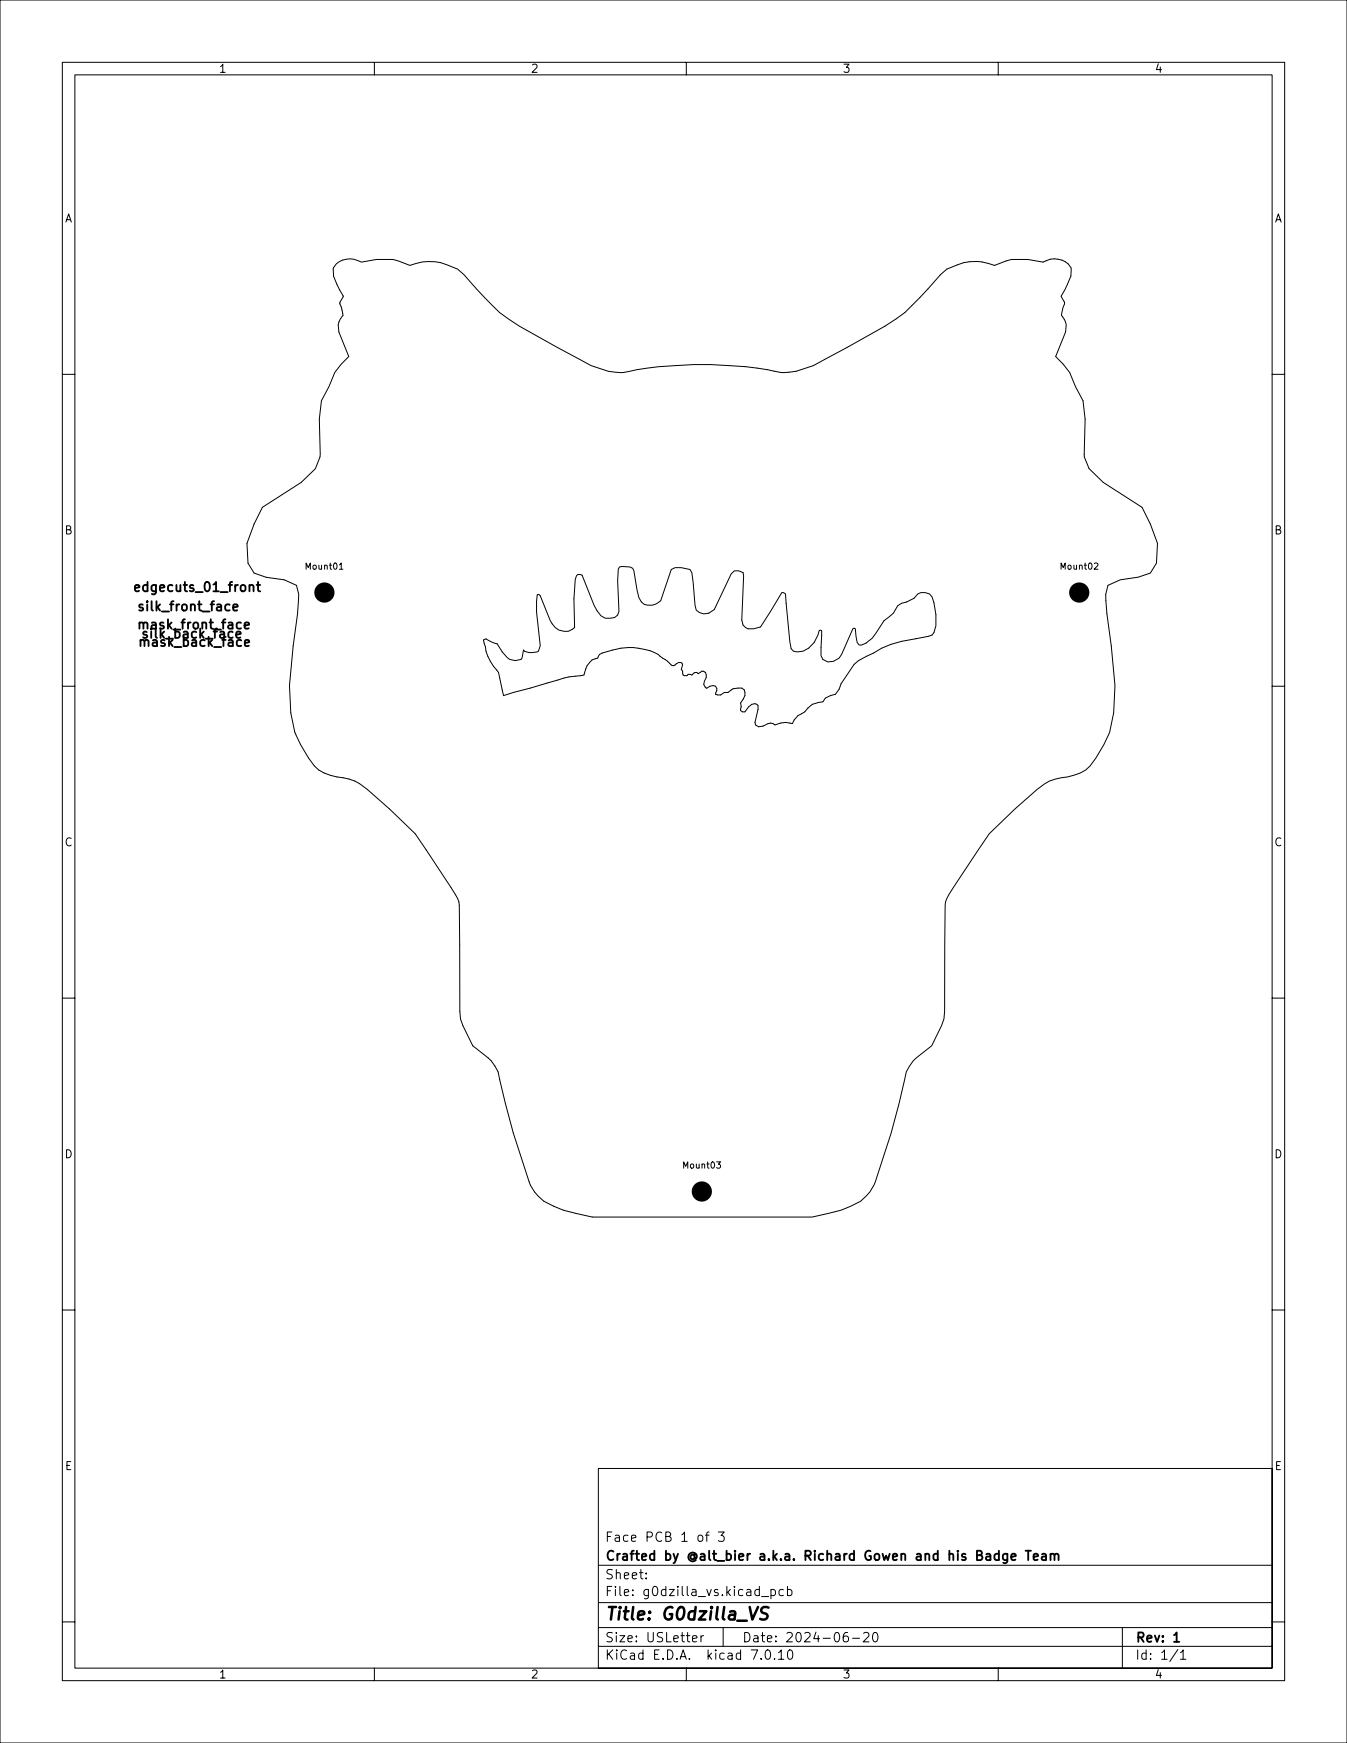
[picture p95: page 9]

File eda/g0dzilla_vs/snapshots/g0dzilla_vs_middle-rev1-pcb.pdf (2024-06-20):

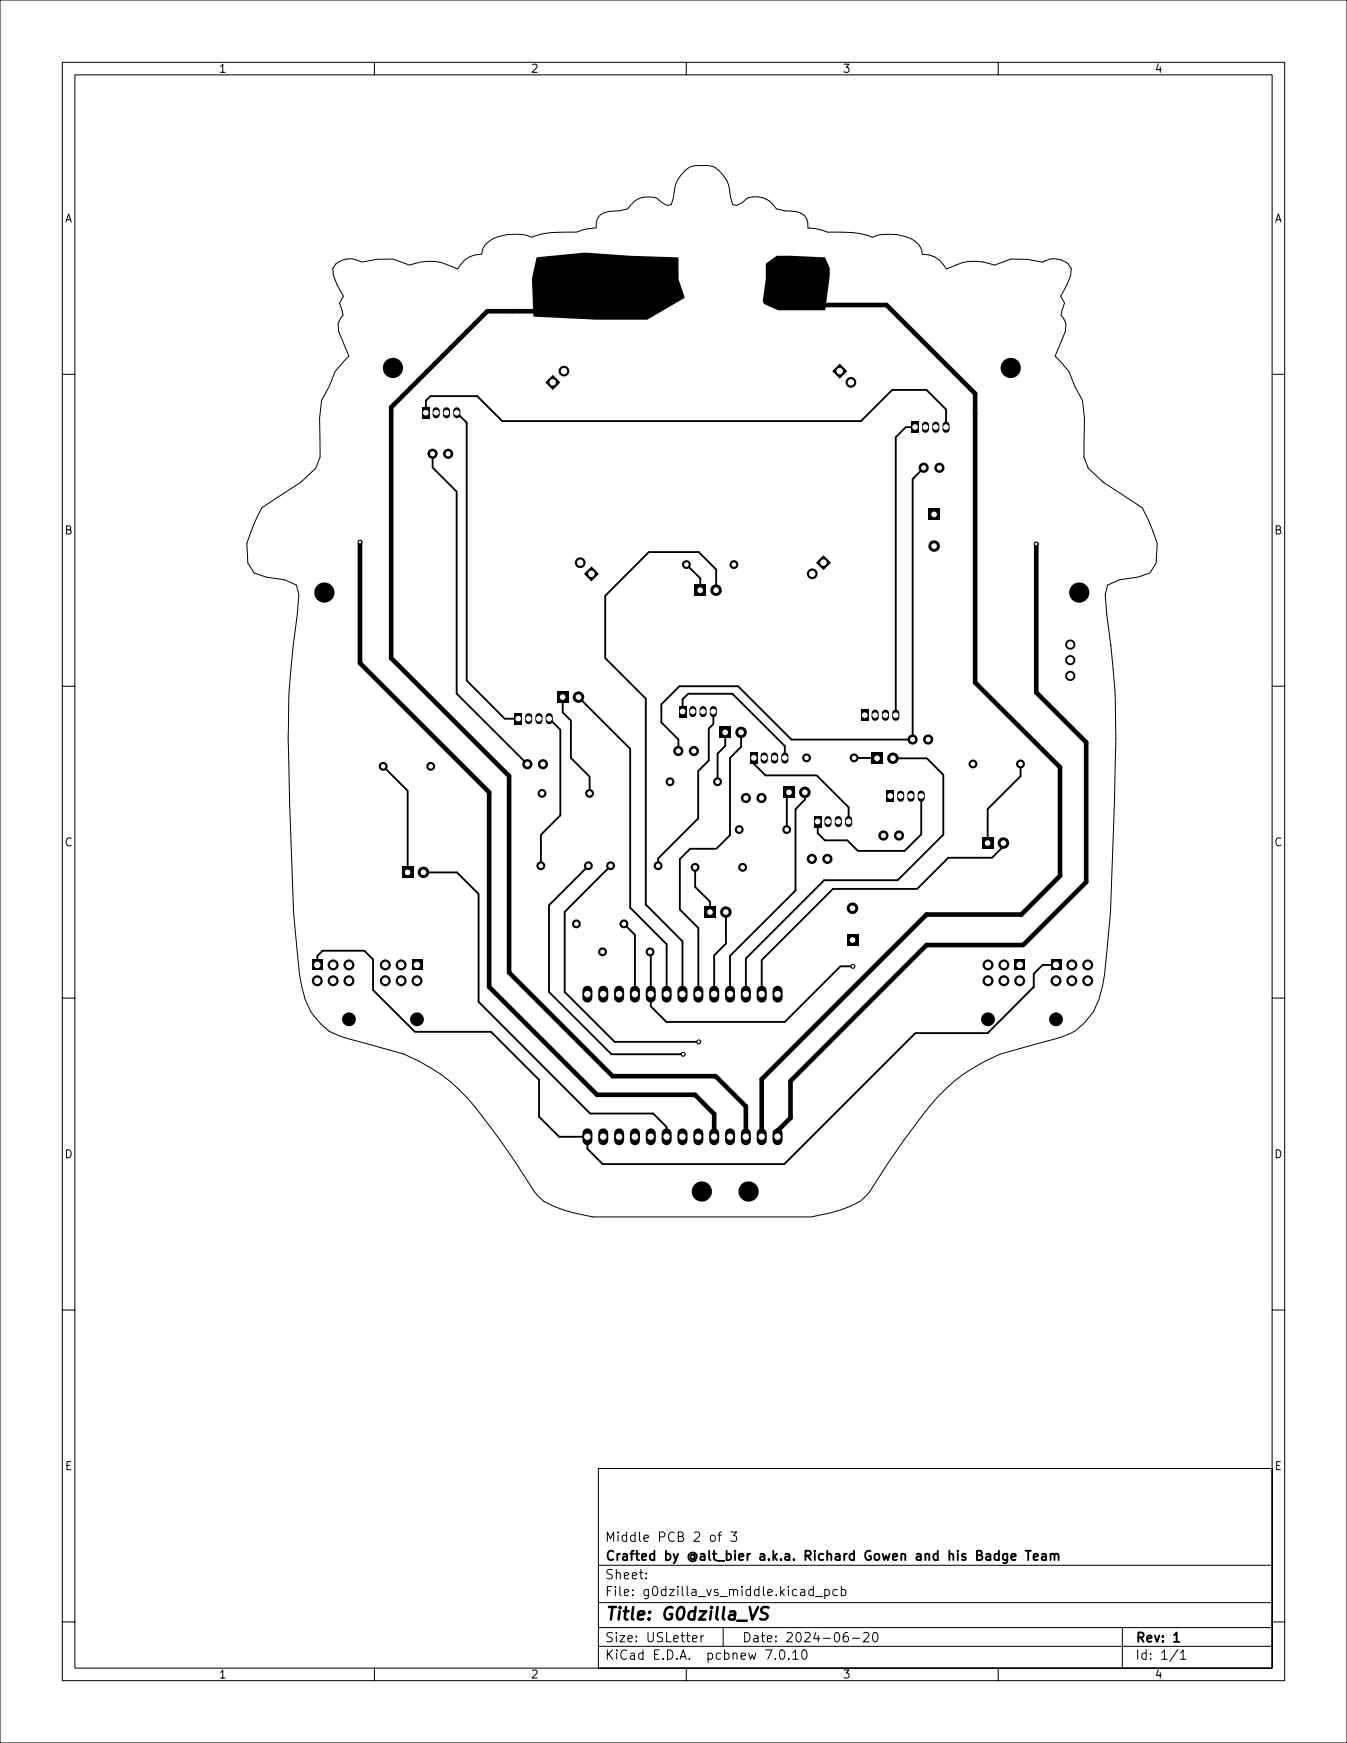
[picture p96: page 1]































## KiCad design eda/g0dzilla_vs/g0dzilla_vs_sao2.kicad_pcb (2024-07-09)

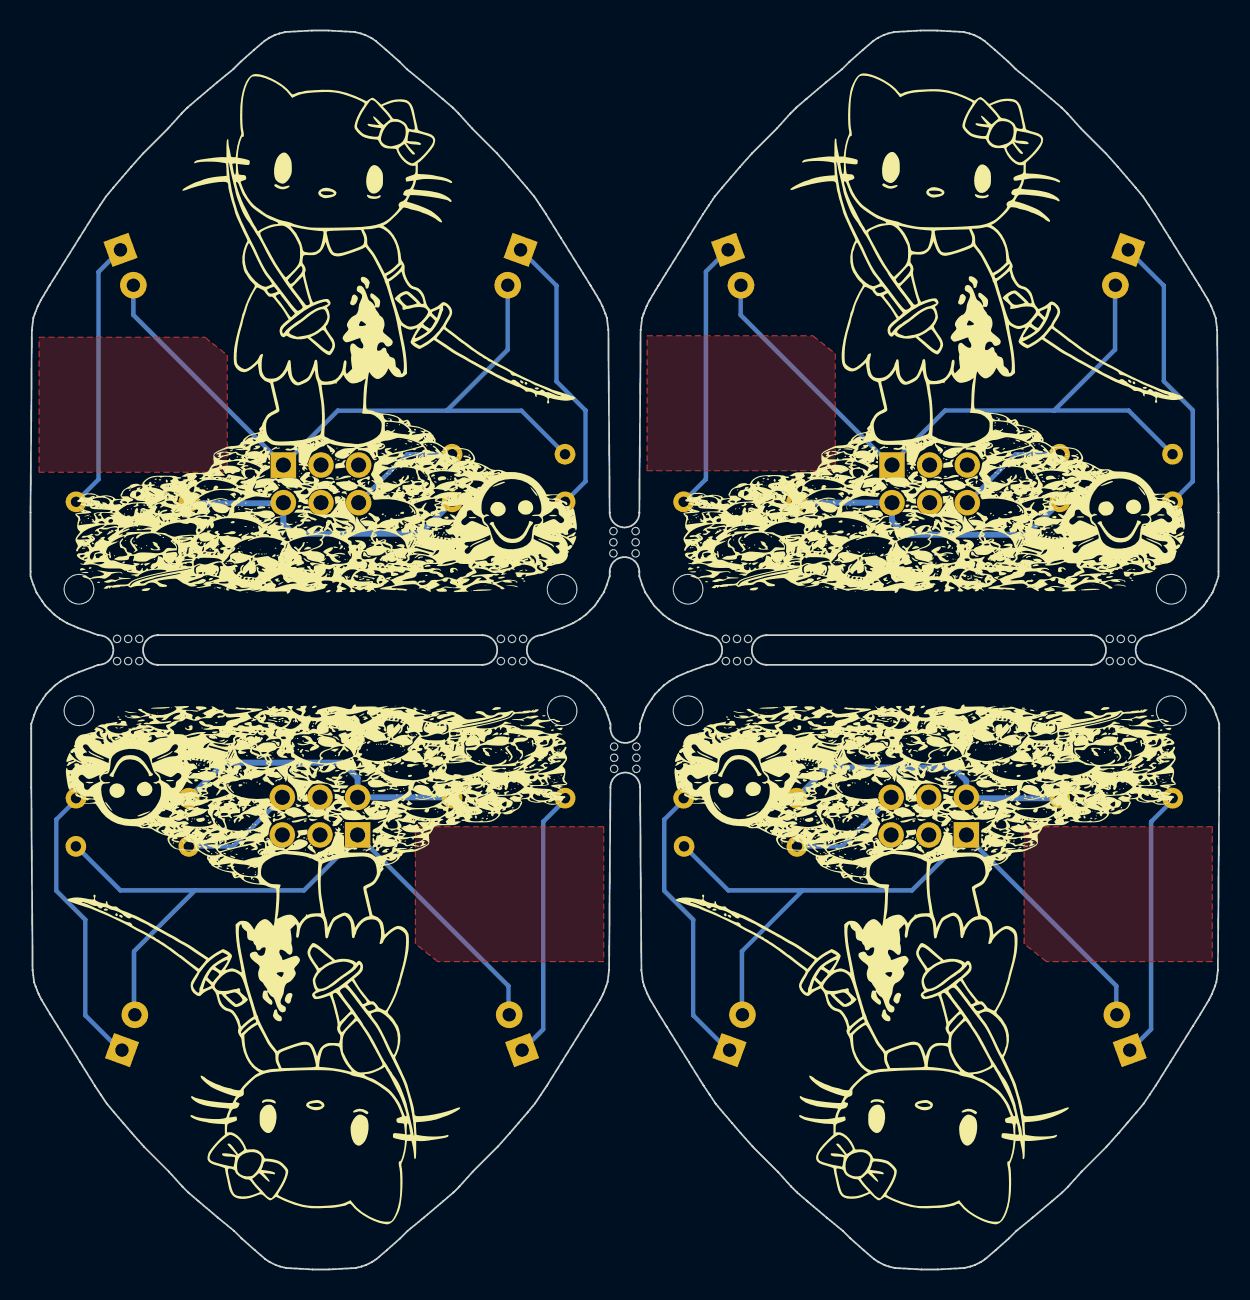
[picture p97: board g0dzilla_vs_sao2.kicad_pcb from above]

Board: 2 copper layers, 80.2 x 83.6 mm, 36 parts (0 on the bottom side), 20 nets.

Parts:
D11, D12, D21, D22, D31, D32, D41, D42: LED_3mm; LED_D3.0mm-2-std_back
Fold: LED_Fold_Indicator_1; LED_Fold_Indicator_back
Fold#2, Fold#3, Fold#4, Fold#5, Fold#6, Fold#7, Fold#8: LED_Fold_Indicator_1; LED_Fold_Indicator_back
JSAO1, JSAO2, JSAO3, JSAO4: Conn_02x03_SAO; SAOv169-SAOv3-2x3
R11, R12, R21, R22, R31, R32, R41, R42: 47R_6.3mm; R_Axial_DIN0207_L6.3_D2.5_P7.62_Horiz_back
R13: 10K_6.3mm; R_Axial_DIN0207_L6.3_D2.5_P7.62_Horiz_back
R23: 47K_6.3mm; R_Axial_DIN0207_L6.3_D2.5_P7.62_Horiz_back
R33: 100K_6.3mm; R_Axial_DIN0207_L6.3_D2.5_P7.62_Horiz_back
R43: 220K_6.3mm; R_Axial_DIN0207_L6.3_D2.5_P7.62_Horiz_back
mask_back_sao2: Back Mask; g0dzilla_vs_sao2_mask_b
mask_front_sao2: Front Mask; g0dzilla_vs_sao2_mask_f
sao_edgecuts_01: Edge Cuts; g0dzilla_vs_SAO_edgecuts_01
silk_front_sao2: Front Silk; g0dzilla_vs_sao2_silk_f

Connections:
+3.3V: D11.2 (A), D12.2 (A), JSAO1.1, R13.2
+3.3V1: D21.2 (A), D22.2 (A), JSAO2.1, R23.2
+3.3V2: D31.2 (A), D32.2 (A), JSAO3.1, R33.2
+3.3V3: D41.2 (A), D42.2 (A), JSAO4.1, R43.2
GND: JSAO1.2, R11.2, R12.2
GND1: JSAO2.2, R21.2, R22.2
GND2: JSAO3.2, R31.2, R32.2
GND3: JSAO4.2, R41.2, R42.2
unnamed: D11.1 (K), R11.1
unnamed: D12.1 (K), R12.1
unnamed: D21.1 (K), R21.1
unnamed: D22.1 (K), R22.1
unnamed: D31.1 (K), R31.1
unnamed: D32.1 (K), R32.1
unnamed: D41.1 (K), R41.1
unnamed: D42.1 (K), R42.1
unnamed: JSAO1.6, R13.1
unnamed: JSAO2.6, R23.1
unnamed: JSAO3.6, R33.1
unnamed: JSAO4.6, R43.1

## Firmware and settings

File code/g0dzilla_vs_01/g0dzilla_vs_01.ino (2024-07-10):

// g0dzilla_vs badge code rev01

// Include Libraries
#include <Arduino.h>
#include <WiFi.h>
#include "Adafruit_NeoPixel.h"
#include "SPI.h"
#include <driver/adc.h>
#include <esp_wifi_types.h>
#include <esp_wifi.h>
// Include CTF Library
#include <g0dzilla_vs_lib.h>

// Pin Definitions
//
// NeoPixel Data Pins
#define NEO01_DATA 17
#define NEO02_DATA 16
// NEO01-0 D10 Breath
// NEO01-1 D11 Eye-Left
// NEO01-2 D12 Eye-Right
// NEO01-3 D13 Tail-Top
// NEO02-0 D20 Back-Top
// NEO02-1 D21 Back-Mid
// NEO02-2 D22 Back-Bot
// NEO02-3 D23 Tail-Bot
//
// One color LED Pins
#define LED_D1 32  // Breath
#define LED_D2 25  // Back-Top
#define LED_D3 27  // Back-Bot
#define LED_D4 14  // Tail
#define LED_D5 26  // Stomp
#define LED_D6 33  // Nuke
#define LED_D7 12  // Navy
#define LED_D8 5   // Army
//
// Built-in LED
#define LED_BI 22

//
// Capacitive Touch Pins
#define TCH01_PIN 4  // Monarch
#define TCH02_PIN 2  // Godzilla
#define TCH03_PIN 15 // VS
#define TCH04_PIN 13 // Minus-One

//
// Analog Inut Pins
#define JSAO01 34 // Left Front SAO
#define JSAO02 35 // Right Front SAO

// NeoPixel Properties
//
// Define NeoPixel Strips - (Num pixels, pin to send signals, pixel type, signal rate)
Adafruit_NeoPixel NEO01 = Adafruit_NeoPixel(4, NEO01_DATA, NEO_RGB + NEO_KHZ800);
Adafruit_NeoPixel NEO02 = Adafruit_NeoPixel(4, NEO02_DATA, NEO_RGB + NEO_KHZ800);

// LED Variables
//
// Main LED mode 0=default 1=battleone 2=?
int main_led_mode = 0;
//
// NeoPixel Big Color Value 32 bit = (W-8bit << 24) + (R-8bit << 16) + (G-8bit <<8) + (B-8bit)
uint32_t neo_big_color = 0;
uint8_t neo_col_whi = 0;
uint8_t neo_col_red = 0;
uint8_t neo_col_grn = 0;
uint8_t neo_col_blu = 0;
// Neo Color bitvector 1=red 2=green 4=blue (3=R&G 5=R&B 6=G&B 7=R&G&B)
int neo_color_bitv = 0;

// PWM Properties
//
// Signal Frequency in Hz
const int freq = 1000;
// Duty Cycle Resolution in bits (1-16)
const int resolution = 8;
// PWM channel Assignment (0-15)
const int LED_D1_pwm = 1;
const int LED_D2_pwm = 2;
const int LED_D3_pwm = 3;
const int LED_D4_pwm = 4;
const int LED_D5_pwm = 5;
const int LED_D6_pwm = 6;
const int LED_D7_pwm = 7;
const int LED_D8_pwm = 8;

// Wireless Properties
//
// WIFI status codes
const char* wl_status_to_string(wl_status_t status) {
  switch (status) {
    case WL_NO_SHIELD: return "WL_NO_SHIELD";
    case WL_IDLE_STATUS: return "WL_IDLE_STATUS";
    case WL_NO_SSID_AVAIL: return "WL_NO_SSID_AVAIL";
    case WL_SCAN_COMPLETED: return "WL_SCAN_COMPLETED";
    case WL_CONNECTED: return "WL_CONNECTED";
    case WL_CONNECT_FAILED: return "WL_CONNECT_FAILED";
    case WL_CONNECTION_LOST: return "WL_CONNECTION_LOST";
    case WL_DISCONNECTED: return "WL_DISCONNECTED";
  }
}

// Capacitive Touch Properties
//
// Touch Thresholds
int Touch01_Threshold = 28;
int Touch02_Threshold = 28;
int Touch03_Threshold = 28;
int Touch04_Threshold = 28;
// Touch Initial Values
int Touch01_Value = 30;
int Touch02_Value = 30;
int Touch03_Value = 30;
int Touch04_Value = 30;
//
// Touch Counters
//
// Touch Iteration Counter
int Touch01_IntCount = 0;
int Touch02_IntCount = 0;
int Touch03_IntCount = 0;
int Touch04_IntCount = 0;
// Touch Iteration Flag
int Touch01_IntFlag = 0;
int Touch02_IntFlag = 0;
int Touch03_IntFlag = 0;
int Touch04_IntFlag = 0;
// Touch Loop Counter
int Touch01_LoopCount = 0;
int Touch02_LoopCount = 0;
int Touch03_LoopCount = 0;
int Touch04_LoopCount = 0;
// Touch Loop Threshold (Touch Held for X Loops of Main)
int Touch01_Loop_Threshold = 3;
int Touch02_Loop_Threshold = 3;
int Touch03_Loop_Threshold = 3;
int Touch04_Loop_Threshold = 3;

// Analog Input Values
int JSAO01_Value = 0;
int JSAO02_Value = 0;

// Loop Control Properties
//
// Main Loop LED Iteration Delay Time [in ms] - Default 20
int LEDDelayTime = 20;
//
// Debug Serial - If set greater than 0 it writes to serial for debugging
// 0 = no debug text
// 1 = basic debug info once per main loop
// 2 = extra debug info
int DebugSerial = 2;

// //////////////////////////////////////////////////
//
// SETUP - RUN ONCE
//
// //////////////////////////////////////////////////
void setup(){
  // Add a delay to allow opening serial monitor
  delay(800);

  // setup the serial output baud rate
  Serial.begin(115200);

  if (DebugSerial >= 1) {
    Serial.println("Starting Setup");
  }

  // Turn Off WiFi/BT
  if (DebugSerial >= 2) {
    Serial.println("Turn Off WiFi / BlueTooth");
  }
  setModemSleep();

  // Configure LED PWM functionalitites per channel
  if (DebugSerial >= 2) {
    Serial.println("Configure PWM Channels");
  }
  ledcSetup(LED_D1_pwm, freq, resolution);
  ledcSetup(LED_D2_pwm, freq, resolution);
  ledcSetup(LED_D3_pwm, freq, resolution);
  ledcSetup(LED_D4_pwm, freq, resolution);
  ledcSetup(LED_D5_pwm, freq, resolution);
  ledcSetup(LED_D6_pwm, freq, resolution);
  ledcSetup(LED_D7_pwm, freq, resolution);
  ledcSetup(LED_D8_pwm, freq, resolution);

  // Attach the channel to the GPIO to be controlled
  if (DebugSerial >= 2) {
    Serial.println("Attach PWM Channels to LED Pins");
  }
  ledcAttachPin(LED_D1, LED_D1_pwm);
  ledcAttachPin(LED_D2, LED_D2_pwm);
  ledcAttachPin(LED_D3, LED_D3_pwm);
  ledcAttachPin(LED_D4, LED_D4_pwm);
  ledcAttachPin(LED_D5, LED_D5_pwm);
  ledcAttachPin(LED_D6, LED_D6_pwm);
  ledcAttachPin(LED_D7, LED_D7_pwm);
  ledcAttachPin(LED_D8, LED_D8_pwm);

  //Normal LED output
  if (DebugSerial >= 2) {
    Serial.println("Set Output for non-PWM LED Pins");
  }
  pinMode(LED_BI, OUTPUT);

  // Initialize the NeoPixels
  if (DebugSerial >= 2) {
    Serial.println("Initialize NeoPixels");
  }
  NEO01.begin();
  NEO02.begin(); 
  // Set Neopixel Brightness (0-255 scale)
  NEO01.setBrightness(170);
  NEO02.setBrightness(170);
  // Set an initial random color for neopixel functions
  setRandomColor();

  // Start all LEDs in OFF mode
  if (DebugSerial >= 2) {
    Serial.println("Turn OFF all LEDs");
  }
  ledAllOff();

  // Set a Random Seed
  int myrandseed = (analogRead(0) + analogRead(34) + (touchRead(TCH02_PIN) * 2) + (touchRead(TCH03_PIN)*3) + touchRead(TCH04_PIN));
  randomSeed(myrandseed);
  if (DebugSerial >= 2) {
    Serial.print("Set Random Seed "); Serial.println(myrandseed);
  }

  if (DebugSerial >= 1) {
    Serial.println(F("Setup Done!"));
  }

  // END OF SETUP
}

// //////////////////////////////////////////////////
//
// LOOP - MAIN 
//
// //////////////////////////////////////////////////
void loop(){
  if (DebugSerial >= 1) {
    Serial.println("******************** TOP OF MAIN LOOP ********************");
  }
  // Capacitive Touch Dynamic Threshold Adjustment
  // Adjust thresholds UP to account for assembly conditions and battery vs usb
  Touch01_Value = touchRead(TCH01_PIN);
  if ( (Touch01_Value / Touch01_Threshold) > 2 ) { Touch01_Threshold = int(Touch01_Threshold * 1.8); }
  Touch02_Value = touchRead(TCH02_PIN);
  if ( (Touch02_Value / Touch02_Threshold) > 2 ) { Touch02_Threshold = int(Touch02_Threshold * 1.8); }
  Touch03_Value = touchRead(TCH03_PIN);
  if ( (Touch03_Value / Touch03_Threshold) > 2 ) { Touch03_Threshold = int(Touch03_Threshold * 1.8); }
  Touch04_Value = touchRead(TCH04_PIN);
  if ( (Touch04_Value / Touch04_Threshold) > 2 ) { Touch04_Threshold = int(Touch04_Threshold * 1.8); }

  // //////////////////////////////////
  //     START OF ITERATION LOOP
  // //////////////////////////////////
  //
  // Iterate 0 to 254
  for(int i=0; i<255; i++){
    // Set position value to iteration value
    int pos = i;

    // DEBUG - Print current Iteration value to serial console for troubleshooting
    if (DebugSerial >= 2) {
      Serial.print(" Iteration="); Serial.print(i);
      Serial.print(" Pos="); Serial.print(pos);
    }

    //
    // TOUCH
    //
    // Read Touch Values
    Touch01_Value = touchRead(TCH01_PIN); // Monarch
    Touch02_Value = touchRead(TCH02_PIN); // Godzilla
    Touch03_Value = touchRead(TCH03_PIN); // VS
    Touch04_Value = touchRead(TCH04_PIN); // Minus-One
    //
    // **************************************************************
    //
    // Do Stuff If We Detect a Touch on TCH01_PIN
    if (Touch01_Value < Touch01_Threshold) {
      // DEBUG - Print current Touch value/threshold to serial console for troubleshooting
      if (DebugSerial >= 2) {
        Serial.print(" T1_TCH="); Serial.print(Touch01_Value);
        Serial.print("/"); Serial.print(Touch01_Threshold);
        Serial.print("-"); Serial.print(Touch01_IntCount);
        Serial.print("/"); Serial.print(Touch01_LoopCount);
      }
      // STUFF - TCH01_PIN TOUCHED
      if (Touch01_IntFlag == 0){
        // Put stuff to happen once per iteration loop here
        Touch01_IntFlag = 1;
      }
      // Put stuff to happen every iteration here
      Touch01_IntCount++;
      //
      monarch_neo_color();
    //
    // Do Stuff If We DONT Detect a Touch on TCH01_PIN
    } else {
      // DEBUG - Print current Touch value/threshold to serial console for troubleshooting
      if (DebugSerial >= 2) {
        Serial.print(" T1="); Serial.print(Touch01_Value);
        Serial.print("/"); Serial.print(Touch01_Threshold);
        Serial.print("-"); Serial.print(Touch01_IntCount);
        Serial.print("/"); Serial.print(Touch01_LoopCount);
      }
      // STUFF - TCH01_PIN NOT TOUCHED
      if (Touch01_IntCount > 1) { Touch01_IntCount--; } else { Touch01_IntCount = 0; }
    }
    // **************************************************************
    //
    // Do Stuff If We Detect a Touch on TCH02_PIN
    if (Touch02_Value < Touch02_Threshold) {
      // DEBUG - Print current Touch value/threshold to serial console for troubleshooting
      if (DebugSerial >= 2) {
        Serial.print(" T2_TCH="); Serial.print(Touch02_Value);
        Serial.print("/"); Serial.print(Touch02_Threshold);
        Serial.print("-"); Serial.print(Touch02_IntCount);
        Serial.print("/"); Serial.print(Touch02_LoopCount);
      }
      // STUFF - TCH02_PIN TOUCHED
      if (Touch02_IntFlag == 0){
        // Put stuff to happen once per iteration loop here
        Touch02_IntFlag = 1;
        main_led_mode = main_led_mode + 1;
        if (main_led_mode > 1) { main_led_mode = 0; }
        setRandomColor();
      }
      // Put stuff to happen every iteration here
      Touch02_IntCount++;
      //
      //
    //
    // Do Stuff If We DONT Detect a Touch on TCH02_PIN
    } else {
      // DEBUG - Print current Touch value/threshold to serial console for troubleshooting
      if (DebugSerial >= 2) {
        Serial.print(" T2="); Serial.print(Touch02_Value);
        Serial.print("/"); Serial.print(Touch02_Threshold);
        Serial.print("-"); Serial.print(Touch02_IntCount);
        Serial.print("/"); Serial.print(Touch02_LoopCount);
      }
      // STUFF - TCH02_PIN NOT TOUCHED
      if (Touch02_IntCount > 1) { Touch02_IntCount--; } else { Touch02_IntCount = 0; }
    }
    // **************************************************************
    //
    // Do Stuff If We Detect a Touch on TCH03_PIN
    if (Touch03_Value < Touch03_Threshold) {
      // DEBUG - Print current Touch value/threshold to serial console for troubleshooting
      if (DebugSerial >= 2) {
        Serial.print(" T3_TCH="); Serial.print(Touch03_Value);
        Serial.print("/"); Serial.print(Touch03_Threshold);
        Serial.print("-"); Serial.print(Touch03_IntCount);
        Serial.print("/"); Serial.print(Touch03_LoopCount);
      }
      // STUFF - TCH03_PIN TOUCHED
      if (Touch03_IntFlag == 0){
        // Put stuff to happen once per iteration loop here
        Touch03_IntFlag = 1;
      }
      // Put stuff to happen every iteration here
      Touch03_IntCount++;
      //
      vs_pwm_on();
    //
    // Do Stuff If We DONT Detect a Touch on TCH03_PIN
    } else {
      // DEBUG - Print current Touch value/threshold to serial console for troubleshooting
      if (DebugSerial >= 2) {
        Serial.print(" T3="); Serial.print(Touch03_Value);
        Serial.print("/"); Serial.print(Touch03_Threshold);
        Serial.print("-"); Serial.print(Touch03_IntCount);
        Serial.print("/"); Serial.print(Touch03_LoopCount);
      }
      // STUFF - TCH03_PIN NOT TOUCHED
      if (Touch03_IntCount > 1) { Touch03_IntCount--; } else { Touch03_IntCount = 0; }
    }
    // **************************************************************
    //
    // Do Stuff If We Detect a Touch on TCH04_PIN
    if (Touch04_Value < Touch04_Threshold) {
      // DEBUG - Print current Touch value/threshold to serial console for troubleshooting
      if (DebugSerial >= 2) {
        Serial.print(" T4_TCH="); Serial.print(Touch04_Value);
        Serial.print("/"); Serial.print(Touch04_Threshold);
        Serial.print("-"); Serial.print(Touch04_IntCount);
        Serial.print("/"); Serial.print(Touch04_LoopCount);
      }
      // STUFF - TCH04_PIN TOUCHED
      if (Touch04_IntFlag == 0){
        // Put stuff to happen once per iteration loop here
        Touch04_IntFlag = 1;
        if (neo_color_bitv < 7) { neo_color_bitv++; } else { neo_color_bitv = 1;}
        setStaticColor(0, 0, 0, neo_color_bitv);
      }
      // Put stuff to happen every iteration here
      Touch04_IntCount++;
      //
      minusone_neo_color();
    //
    // Do Stuff If We DONT Detect a Touch on TCH04_PIN
    } else {
      // DEBUG - Print current Touch value/threshold to serial console for troubleshooting
      if (DebugSerial >= 2) {
        Serial.print(" T4="); Serial.print(Touch04_Value);
        Serial.print("/"); Serial.print(Touch04_Threshold);
        Serial.print("-"); Serial.print(Touch04_IntCount);
        Serial.print("/"); Serial.print(Touch04_LoopCount);
      }
      // STUFF - TCH04_PIN NOT TOUCHED
      if (Touch04_IntCount > 1) { Touch04_IntCount--; } else { Touch04_IntCount = 0; }
    }
    // **************************************************************
    //

    // Read Analog Input Values
    JSAO01_Value = analogRead(JSAO01);
    JSAO02_Value = analogRead(JSAO02);
    // Display Analog Values
    if (DebugSerial >= 2) {
      Serial.print(" SAO1="); Serial.print(JSAO01_Value);
      Serial.print(" SAO2="); Serial.print(JSAO02_Value);
    }

    if (main_led_mode == 0) {
      //
      // DEFAULT MODE
      //
      // First of three position groups i 0-84
      if (pos < 85) {
        //
        // LED FUNCTIONS
        eyes_neo_colorshift(pos, 1);
        g0dz_neo_colorshift(pos, 1);
        ledPwmDefault(pos, 1);
        BI_blink_three(pos);
      // Second of three position groups i 85-169 (pos-85 = 0-84)
      } else if (pos < 170) {
        pos = pos - 85;
        //
        // LED FUNCTIONS
        eyes_neo_colorshift(pos, 2);
        g0dz_neo_colorshift(pos, 2);
        ledPwmDefault(pos, 2);
        BI_blink_three(pos);
      // Third of three position groups i 170-254 (pos-170 = 0-84)
      } else {
        pos = pos -170;
        //
        // LED FUNCTIONS
        eyes_neo_colorshift(pos, 3);
        g0dz_neo_colorshift(pos, 3);
        ledPwmDefault(pos, 3);
        BI_blink_three(pos);
        // Split third group 3/4 (pos 0-42) for even number of transitions
        if (pos <43) {
          //
        // Split third group 4/4 (pos 43-84) for even number of transitions
        } else {
          //
        }
      }
    } else if (main_led_mode == 1) {
      //
      // BATTLE MODE
      //
      // First of three position groups i 0-84
      if (pos < 85) {
        //
        // LED FUNCTIONS
        g0dz_blast(pos);
        BI_blink_two(pos);
      // Second of three position groups i 85-169 (pos-85 = 0-84)
      } else if (pos < 170) {
        pos = pos - 85;
        //
        // LED FUNCTIONS
        g0dz_blast(pos);
        BI_blink_two(pos);
      // Third of three position groups i 170-254 (pos-170 = 0-84)
      } else {
        pos = pos -170;
        //
        // LED FUNCTIONS
        g0dz_blast(pos);
        BI_blink_two(pos);
        // Split third group 3/4 (pos 0-42) for even number of transitions
        if (pos <43) {
          //
        // Split third group 4/4 (pos 43-84) for even number of transitions
        } else {
          //
        }
      }
    }

    // DEBUG - Print NEO color vars
    if (DebugSerial >= 2) {
      Serial.print(" C="); Serial.print(neo_col_red);
      Serial.print("/"); Serial.print(neo_col_grn);
      Serial.print("/"); Serial.print(neo_col_blu);
      Serial.print("/"); Serial.print(neo_color_bitv);
    }

    // DEBUG - Print LED mode
    if (DebugSerial >= 2) {
      Serial.print(" Mode="); Serial.print(main_led_mode);
    }

    // DEBUG - Print Carriage Return for iteration level debug output
    if (DebugSerial >= 2) {
      Serial.println();
    }

    // Display Neopixel values
    neo_show();

    // Pause the loop to display everything
    delay(LEDDelayTime);

    // END OF FOR ITERATION LOOP
  }
  // //////////////////////////////////
  //     END OF ITERATION LOOP
  // //////////////////////////////////

  // Touch Loop Counters - USE TBD
  if (Touch01_IntCount >= 1) { Touch01_LoopCount++; Touch01_IntCount = 0; } else { Touch01_LoopCount = 0; }
  if (Touch02_IntCount >= 1) { Touch02_LoopCount++; Touch02_IntCount = 0; } else { Touch02_LoopCount = 0; }
  if (Touch03_IntCount >= 1) { Touch03_LoopCount++; Touch03_IntCount = 0; } else { Touch03_LoopCount = 0; }
  if (Touch04_IntCount >= 1) { Touch04_LoopCount++; Touch04_IntCount = 0; } else { Touch04_LoopCount = 0; }

  // Reset Touch Iteration Flags
  Touch01_IntFlag = 0; Touch02_IntFlag = 0; Touch03_IntFlag = 0; Touch04_IntFlag = 0;

  // Turn off all LEDs at end of loop (Optional for troubleshooting)
  // ledAllOff();

  // //////////////////////////////////////////////////
  //
  // Launch BATT_CHRG_NOLED Alternate Mainline Code When
  // Touch01_LoopCount exceeds Touch01_Loop_Threshold
  // Touch01 is the Monarch Logo
  //
  // //////////////////////////////////////////////////
  if (Touch01_LoopCount > Touch01_Loop_Threshold) {
    //
    Serial.println("LONG TOUCH DETECTED on TCH01 - JUMP TO ALTERNATE CODE");
    //
    ledAllOff();
    //
    Touch01_LoopCount = 0;
    //
    // Alternate code loop
    batt_chrg_noled();
    //
    // END ALTERNATE MAIN LOOP
    Serial.println("****************************************");
    Serial.println("***** EXITING BATT_CHRG_NOLED MODE *****");
    Serial.println("****************************************");
    //
    ledAllOff();
    //
    Touch01_LoopCount = 0;
    //
    main_led_mode = 0;
    // Pause before exiting
    delay(100);
  }

  // //////////////////////////////////////////////////
  //
  // Launch GDZL CTF MODE Alternate Mainline Code When
  // Touch04_LoopCount exceeds Touch04_Loop_Threshold
  // Touch04 is the Minus One Logo
  //
  // //////////////////////////////////////////////////
  if (Touch04_LoopCount > Touch04_Loop_Threshold) {
    //
    Serial.println("LONG TOUCH DETECTED on TCH04 - JUMP TO ALTERNATE CODE");
    //
    ledAllOff();
    //
    Touch04_LoopCount = 0;
    //
    //
    // Alternate code loop
    //
    // Pause before turning on wifi
    delay(200);
    // Turn on wifi in ap mode
    wakeModemSleep();
    // SOLID RED EYES to show we are in CTF Mode
    ledAllOff();
    NEO01.setPixelColor(1, 255, 0, 0);  // Eye-Left
    NEO01.setPixelColor(2, 255, 0, 0);  // Eye-Right
    neo_show();
    // Long Pause before launching alternate code to allow wifi to come active
    delay(4000);
    // Show Wifi Status
    Serial.println(" WiFi Status: "); Serial.println(wl_status_to_string(WiFi.status()));
    // Launch CVD ADVENTURE GAME alternate main line code
    gdlAdventureMain();
    //
    // END ALTERNATE MAIN LOOP
    Serial.println("****************************************");
    Serial.println("***      EXITING GDZL CTF MODE      ****");
    Serial.println("****************************************");
    //
    // Turn Off Wifi
    setModemSleep();
    // Pause after turning off wifi
    delay(500);
    //
    ledAllOff();
    //
    Touch04_LoopCount = 0;
    //
    main_led_mode = 0;
    // Pause before exiting
    delay(100);
  }

}
// //////////////////////////////////
//        END OF MAIN LOOP
// //////////////////////////////////


// //////////////////////////////////////////////////
//
// FUNCTIONS
//
// //////////////////////////////////////////////////
//
// WiFi & BT Functions
// //////////////////////////////////////////////////
void disableWiFi(){
    WiFi.disconnect(true);  // Disconnect from the network
    WiFi.mode(WIFI_OFF);    // Switch WiFi off
    Serial.println("WiFi disabled!");
}
//
void disableBluetooth(){
    btStop();
    Serial.println("Bluetooth stopped!");
}
//
void setModemSleep() {
    disableWiFi();
    disableBluetooth();
    setCpuFrequencyMhz(80);
}
//
void enableWiFi(){
    delay(200);
    // Switch Wifi ON in mode AP/STA/AP_STA
    WiFi.mode(WIFI_AP); // Defaulting to AP mode
    delay(200);
    Serial.println("WiFi Started!");
}
//
void wakeModemSleep() {
    setCpuFrequencyMhz(240);
    enableWiFi();
}
// //////////////////////////////////////////////////
//
// LED Functions
// //////////////////////////////////////////////////
void ledAllOff() {
    digitalWrite(LED_BI, HIGH); // HIGH = OFF?
    ledcWrite(LED_D1_pwm, 0);
    ledcWrite(LED_D2_pwm, 0);
    ledcWrite(LED_D3_pwm, 0);
    ledcWrite(LED_D4_pwm, 0);
    ledcWrite(LED_D5_pwm, 0);
    ledcWrite(LED_D6_pwm, 0);
    ledcWrite(LED_D7_pwm, 0);
    ledcWrite(LED_D8_pwm, 0);
    NEO01.setPixelColor(0, 0, 0, 0);
    NEO01.setPixelColor(1, 0, 0, 0);
    NEO01.setPixelColor(2, 0, 0, 0);
    NEO01.setPixelColor(3, 0, 0, 0);
    NEO01.show();
    NEO02.setPixelColor(0, 0, 0, 0);
    NEO02.setPixelColor(1, 0, 0, 0);
    NEO02.setPixelColor(2, 0, 0, 0);
    NEO02.setPixelColor(3, 0, 0, 0);
    NEO02.show();
}
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

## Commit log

2024-03-11 initial badge template
    [BatteryHolder_2466_1xAAA.step, BatteryHolder_2468_2xAAA.step, Battery_Holder_3xAAA_Simple.step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]
2024-03-18 added ESP32 Wemos Lolin32 Lite schem footprints 3D
2024-03-25 footprint and schem updates
2024-03-25 footprint and schematic updates
2024-03-25 footprint updates
2024-03-27 schematic anf footprint work
2024-03-27 esp footprint update
2024-04-02 schematic and footprint updates
2024-05-10 project rename
    [BatteryHolder_2466_1xAAA.step, BatteryHolder_2468_2xAAA.step, Battery_Holder_3xAAA_Simple.step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]
2024-06-04 edgecuts art and eda work
    [g0dzilla_vs.kicad_pcb]
2024-06-10 art and pcb prep
    [g0dzilla_vs_rear.kicad_pcb]
2024-06-12 middle pcb work
    [g0dzilla_vs.kicad_sch]
2024-06-17 rear pcb with crypto added
    [g0dzilla_vs_rear.kicad_pcb]
2024-06-18 sao art and eda work
    [g0dzilla_vs_sao1.kicad_pcb]
2024-06-18 pcb updates
    [g0dzilla_vs.kicad_sch, g0dzilla_vs_sao1.kicad_sch]
2024-06-18 rear pcb work
2024-06-20 final edits before prototype
    [g0dzilla_vs_sao1.kicad_sch]
2024-06-20 final pcbs for prototype
    [g0dzilla_vs-B_Cu.gbl, g0dzilla_vs-B_Mask.gbs, g0dzilla_vs-B_Paste.gbp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]
2024-06-26 prototype 3d viewer snapshots
2024-07-09 h3llo kitty sao
    [g0dzilla_vs_sao2-B_Cu.gbl, g0dzilla_vs_sao2-B_Mask.gbs, g0dzilla_vs_sao2-B_Paste.gbp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]
2024-07-11 fix cnfig file name
    All the scripts reference "arduino-cli.yml".
2024-07-13 updated assembly doc

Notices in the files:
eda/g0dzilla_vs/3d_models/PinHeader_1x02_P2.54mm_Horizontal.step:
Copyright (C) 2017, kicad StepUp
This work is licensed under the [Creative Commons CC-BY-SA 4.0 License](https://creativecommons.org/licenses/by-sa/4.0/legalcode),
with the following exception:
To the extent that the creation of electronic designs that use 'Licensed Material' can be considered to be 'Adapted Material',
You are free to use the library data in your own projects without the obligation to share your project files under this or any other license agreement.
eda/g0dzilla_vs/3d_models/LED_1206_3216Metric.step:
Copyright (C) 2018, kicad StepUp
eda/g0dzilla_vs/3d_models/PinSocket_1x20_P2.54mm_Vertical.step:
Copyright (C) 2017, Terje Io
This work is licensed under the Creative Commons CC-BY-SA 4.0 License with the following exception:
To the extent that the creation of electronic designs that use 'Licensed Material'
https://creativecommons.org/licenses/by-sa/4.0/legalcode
